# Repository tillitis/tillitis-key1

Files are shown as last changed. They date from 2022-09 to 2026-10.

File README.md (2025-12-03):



# Tillitis TKey

Read about current work in progress
[here](#current-work-in-progress-in-this-repository).

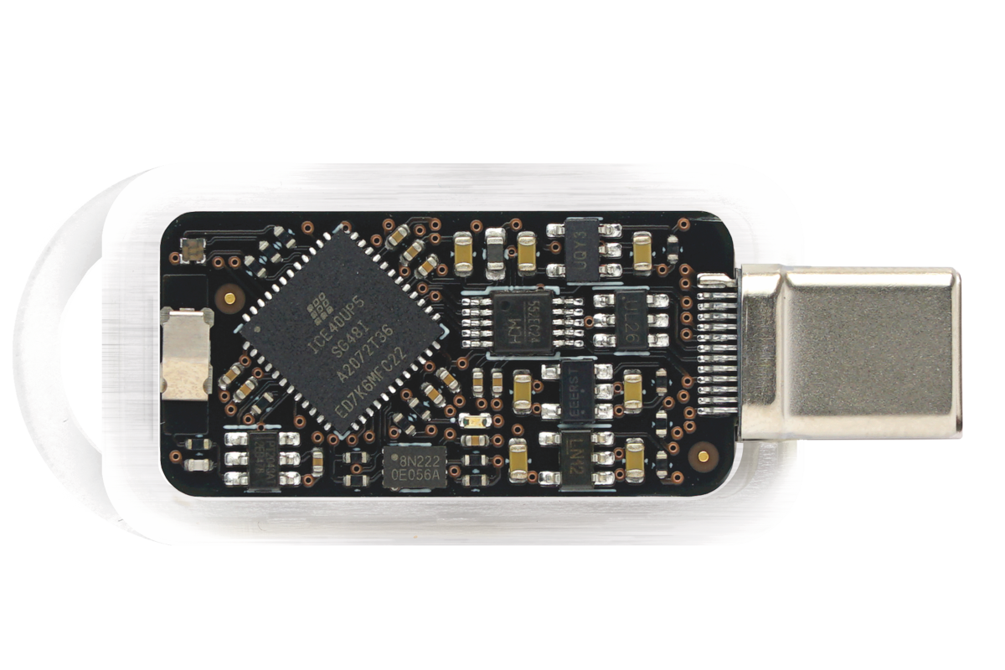
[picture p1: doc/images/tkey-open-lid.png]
TK1 PCB
 *The TK1 PCB, also known as
TKey.*

## Introduction

The Tillitis TKey is an open source, open hardware FPGA-based USB
security token using
[DICE-like](https://trustedcomputinggroup.org/work-groups/dice-architectures/)
unconditional measured boot that can run generic applications while
still guaranteeing the security of its cryptographic assets.

[TKey Threat Model](doc/threat_model/threat_model.md).

With the right application, the TKey can be used for:

- authentication,
- cryptographic signing,
- encryption,
- root of trust,
- and more: it's a general computer!

If you want to know more about Tillitis and the TKey, visit:

- Main web: <https://tillitis.se/>
- Shop: <https://shop.tillitis.se/>
- Developer Handbook: <https://dev.tillitis.se/>
- Officially supported apps: <https://tillitis.se/download/>
- Other known apps: <https://dev.tillitis.se/projects/>

All of the TKey software, firmware, FPGA Verilog code, schematics and
PCB design files are open source, just like all trustworthy security
software and hardware should be.

## Licensing

Unless otherwise noted, the project sources are copyright Tillitis AB,
but you can redistribute it and/or modify it under the terms of the
BSD-2-Clause license.

Until Oct 29, 2025, the license was GPL-2.0 Only.

Each imported project is typically kept in its own directory with its
own LICENSE file.

### SPDX

The project uses single-line references to Unique License Identifiers
as defined by the Linux Foundation's [SPDX project](https://spdx.org/).
The line in each individual source file identifies the license
applicable to that file.

The current set of valid, predefined SPDX identifiers can be found on
the SPDX License List at:

https://spdx.org/licenses/

We attempt to follow the [REUSE
specification](https://reuse.software/).

### Notable imported projects

- ch552 firmware: `hw/usb_interface/ch552_fw/`

  Originally by WCH under MIT. Much changed by Tillitis.

- picorv32: `hw/application_fpga/core/picorv32`

  From https://github.com/YosysHQ/picorv32

  ISC.

- PicoRV32 custom ops: `hw/application_fpga/fw/tk1/picorv32/`

  CC-1.

- tkey-libs: `hw/application_fpga/tkey-libs/`

  BSD2. From https://github.com/tillitis/tkey-libs

## Repositories

This repository contains the FPGA design, the source of the
firmware/bootloader, and the source of the USB controller firmware.

Specific documentation regarding implementation is kept close to the
code/design in README files, typically in the same directory.

Note that development is ongoing. To avoid unexpected changes of
derived key material, please use a tagged release. Read the [Release
Notes](doc/release_notes.md) to keep up to date with changes and new
releases.

The TKey PCB [KiCad](https://www.kicad.org/) design files are kept in
a separate repository:

<https://github.com/tillitis/tk1-pcba>

The TP1 (TKey programmer 1) PCB design files and the firmware sources
are kept in:

<https://github.com/tillitis/tp1>

Note that the TP1 is only used for provisioning the FPGA bitstream
into flash or the FPGA configuration memory. It's not necessary if you
just want to develop apps for the TKey.

We use the tkey-libs libraries used for device app development in the
firmware, too:

https://github.com/tillitis/tkey-libs

but keep our own copy of it in the repo. See below.

## Building & flashing

These instructions assume you're using a Linux distribution. Most of
them also assume you're using our OCI image
[tkey-builder](https://ghcr.io/tillitis/tkey-builder). If you want to
run native tools, look in `contrib/Dockerfile` and
`contrib/buildtools.sh` for the tools and versions to use.

### FPGA

You need a [TKey
Unlocked](https://shop.tillitis.se/products/tkey-not-provisioned), a
[the TP1 TKey Programmer
board](https://shop.tillitis.se/products/tkey-dev-kit), and probably a
[Blinkinlabs CH55x Reset
Controller](https://shop-nl.blinkinlabs.com/products/ch55x-reset-controller)
to use this on real hardware.

Building is probably easiest using make and Podman.

To build everything and then flash the resulting bitstream with the
defaultapp in app slot 0 and the partition table copies in one go,
place the TKey Unlocked in the TP1, then do:

```
cd contrib
make flash
```

This uses the make target `prog_flash` in
`hw/application_fpga/Makefile` behind the scenes, but mounts your TP1
device into the container.

If you want to change the default app the TKey uses, change
`FLASH_APP_0` in the `hw/application_fpga/Makefile`.

To see all container targets:

```
cd contrib
make
```

See the [Tillitis Developer Handbook](https://dev.tillitis.se) for
more.

### USB Controller

The TKey uses a WCH CH552 chip as a USB controller. It has its own
firmware.

Build:

```
cd contrib
make run
cd hw/usb_interface/ch552_fw
make
```

To flash the controller with new firmware you need hardware like the
[Blinkinlabs CH55x Reset
Controller](https://shop-nl.blinkinlabs.com/products/ch55x-reset-controller)
and a USB-A to USB-C converter.

[Reset Controller source](https://github.com/Blinkinlabs/ch55x_programmer).

You also need [chprog](https://github.com/ole00/chprog).

The bootloader identifies itself as USB VID 4348, PID 55e0. To be able
to access it and run `chprog` without root you need to allow your user
to access it. Place `contrib/99-tillitis.rules` in `/etc/udev/rules.d`
and run `udevadm control --reload`. Now you can add your user to the
`dialout` group and access it.

1. Connect the Reset Controller to your computer through "DUT\_IN"/"PC".
2. Connect the TKey to "DUT\_OUT"/"DUT".
3. Press the "Bootloader" button.
4. Run `make flash_patched` in `hw/usb_interface/ch552_fw` outside of
   a container.

## Updating and working with tkey-libs

A copy of [tkey-libs](https://github.com/tillitis/tkey-libs) is kept
in `hw/application_fpga/tkey-libs`. This is mostly to avoid the
subtleties of Git submodules.

If you want to change something in tkey-libs, always change in the
upstream library at:

https://github.com/tillitis/tkey-libs

You can build with an out-of-tree copy if you set `LIBDIR`, for
example:

```
make LIBDIR=~/git/tkey-libs firmware.elf
```

When it's time to update the in-tree tkey-lib first tag the upstream
repo with an `fw` prefix, like `fw-1` even if it already has an
official version tag.

Easiest is probably to just remove the tkey-libs directory and then
git clone the desired tag. Use the entire repo, but remove the .-files
like `.git`, `.github`, et cetera. Something like:

```
$ rm -rf tkey-libs
$ git clone git@github.com:tillitis/tkey-libs.git
$ cd tkey-libs
$ git checkout fw-3
```

Note that you need to change the optimization flag in the tkey-libs'
Makefile to `-Os`.

## Measured boot

The key behind guaranteeing security even as a general computer is the
unconditional measured boot. This means that we have a small,
unchangeable, trusted firmware in ROM that creates a unique identity
before starting the application. This identity is used as a seed for
all later cryptographic keys.

We call this identity the Compound Device Identity (CDI). The CDI is a
cryptographic mix of:

1. the Unique Device Secret (UDS), a hardware secret, unique per
   device, something the user *has*,
2. the hash digest of the TKey device application that has been
  loaded, the *integrity* of the application, and,
3. an optional User Supplied Secret (USS), something the user *knows*.

CDI is computed using the BLAKE2s hash function:

CDI = BLAKE2s(UDS, BLAKE2s(application loaded in RAM), USS)

When firmware is about to start the device application it changes the
TKey to a less permissive hardware mode, application mode. In
application mode the UDS and the User Supplied Secret are no longer
available, but the device application can use the CDI as a seed to
deterministically generate any cryptographic keys it needs.

- If the wrong application has been loaded, or the original
  application has been tampered with, the generated keys will be
  different.
- If the USS is not the same, the generated keys will be different.
- If the same USS and device application is used on a different TKey,
  the generated keys will be different.

The TKey unconditional measured boot is inspired by, but not exactly
the same as part of [TCG
DICE](https://trustedcomputinggroup.org/work-groups/dice-architectures/).

# Current Work in Progress in this repository

We are updating the FPGA and firmware on TKey as part of the Castor
release. This update will simplify TKey’s usage, laying the groundwork
for future support of U2F/FIDO authentication.

You can track our progress through this
[milestone](https://github.com/tillitis/tillitis-key1/milestone/1).

Note that main branch is in development. We try to keep status of main
branch updated in the [release notes](/doc/release_notes.md#upcoming-release-castor).

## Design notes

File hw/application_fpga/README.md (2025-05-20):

## TKey hardware design

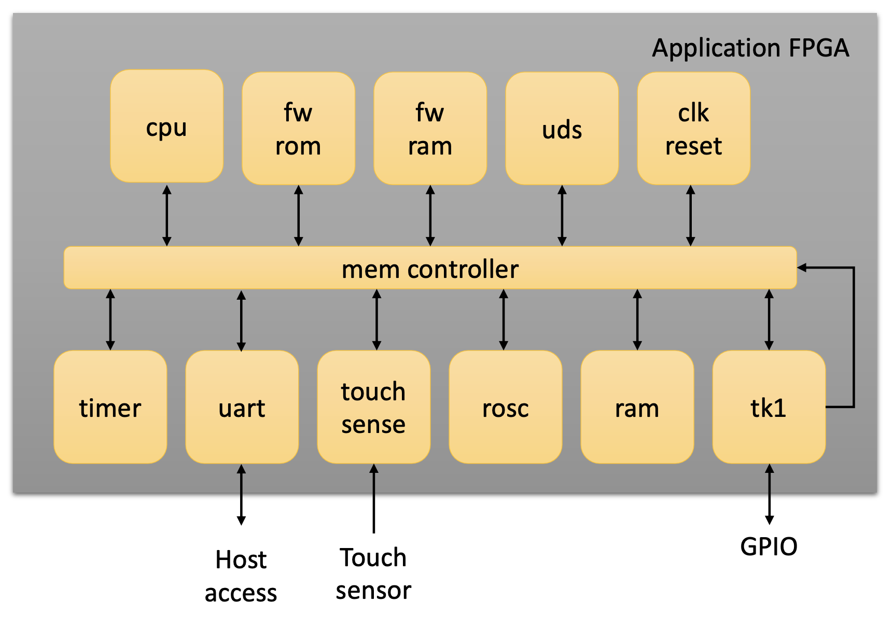
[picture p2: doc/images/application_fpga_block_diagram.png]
The Application FPGA block diagram


The application FPGA is implemented using a Lattice [iCE40 UltraPlus
UP5K
device](https://www.latticesemi.com/en/Products/FPGAandCPLD/iCE40UltraPlus).
Only open tools are used in the toolchain.

The design top level is in `rtl/application_fpga.v`. It contains
instances of all cores as well as the memory system.

The memory system allows the CPU to access cores in different ways
given the current execution mode. There are three execution modes -
firmware, application and system call. Each mode give access to a
different set of resources. Where app mode is the most restrictive and
firmware mode is the least restrictive.

The rest of the components are under `cores`, except the firmware,
which is under `fw/tk1`. They typically have their own `README.md`
file documenting them and their API in detail.

Hardware functions with APIs, assets, and input/output are memory
mapped starting at base address `0xc000_0000`. For specific offsets
and bitmasks, see the file `tk1_mem.h` in tkey-libs.

Rough memory map:

| *name*  | *prefix* |
|---|---|
| ROM | 0x00 |
| RAM | 0x40 |
| TRNG | 0xc0 |
| Timer | 0xc1 |
| UDS | 0xc2 |
| UART | 0xc3 |
| Touch | 0xc4 |
| FW\_RAM | 0xd0 |
| Syscall | 0xe1 |
| TK1 | 0xff |

## Firmware

Firmware is kept in ROM. See the [Firmware implementation
notes](fw/README.md).

## `clk_reset_gen`

Generator for system clock and system reset.

The device does not rely on external clock or reset. Instead the
internal HFOSC oscillator combined with an internal PLL is used to
generate the main clock. Currently the clock frequency driving the SoC
is 21 MHz.

The device also generates its own reset.

## `fw_ram`

Special firmware-only RAM. Unreachable from app mode.

## `picorv32`

A softcore 32 bit RISC-V CPU from [upstreams
PicoRV32](https://github.com/YosysHQ/picorv32).

Configuration of optional CPU features like `ENABLE_FAST_MUL` et
cetera are in `rtl/application_fpga.v`.

The instance enables the following features

- Compressed ISA (C extension)
- Fast multiplication. Two cycles for 32x32 multiplication
- Barrel shifter

No other modification to the core has been done. No interrupts are
used.

## `ram`

The 128 KByte main RAM. The RAM is only used by applications.
The memory is cleared by firmware before an application is loaded.

The application RAM is available to use by firmware and applications.

The RAM core also implements (from the view of the CPU) transparent
RAM address and data scrambling. This scrambling is applied to make it
harder to extract application and application data from a memory dump
directly from the memory cores.

## `rom`

ROM for the firmware. The firmware.elf minus the ELF header is
embedded here in the bitstream.

After reset the CPU will initialize the program counter to start of
ROM.

## `timer`

A general purpose 32 bit timer. The timer will count down from the
initial value to one. In order to handle long time sequences (minutes,
hours, days) there is also a 32 bit prescaler.

The timer is available to use by firmware and applications.

## Syscall

System call trigger area. A 32-bit write to address 0xe1000000 will
trigger interrupt 31, which in turn triggers a system call in the
firmware.

## Interrupts

Triggering an interrupt will cause the CPU to execute the interrupt
handler att address 0x10.

The interrupt handler is shared by all PicoRV32 interrupts but only
interrupt 31 is enabled on the Tkey. Register `x4` can be inspected to
determine the interrupt source. Each interrupt source is assigned one
bit in x4. Triggered interrupts have their bit set to `1`.

| *Source* | *x4 Bit* |
|---|---|
| Syscall  | 31 |

The return address is located in register `x3`. Calling the PicoRV32
specific instruction `retirq` exits the interrupt handler and clears
the interrupt source.

No registers are stored/restored when entering/exiting the interrupt
handler. It is up to the software to store/restore as necessary.

Interrupts can be enabled/disabled using the PicoRV32 specific
`maskirq` instruction.

## Restricted resources

The following table shows resource availablility for each execution
mode:

| *Execution Mode* | *ROM* | *FW RAM* | *SPI* | *UDS* |
|---|---|---|---|---|
| Firmware mode | r/x | r/w | r/w | r/w*  |
| Syscall | r/x | r/w | r/w | i |
| Application mode | r | i | i | i |

Legend:
r = readable
w = writeable
x = executable
i = invisible
* = UDS words are readable only once in firmware mode.

## `tk1`

See [tk1 README](core/tk1/README.md) for details.

Contains:

- FPGA name and version.
- Execution mode control: firmware mode/application mode.
- RGB LED control.
- General purpose input/output (GPIO) pin control.
- Application introspection: start address and size of binary.
- Compound Device Identity (CDI).
- Unique Device Identity (UDI).
- RAM memory protection.
- Security monitor.
- SPI main.
- System reset.

### Illegal instruction monitor

Execution of illegal instructions will cause the CPU to enter its trap
state from which it can't exit. The hardware in the TKey will monitor
the CPU state. If the CPU enters the trap state, the hardware will
start flashing the RED led, signalling that the TKey is stuck in an
error state.

### RAM memory protection

The TKey hardware includes a simple form of RAM memory protection. The
purpose of the RAM memory protection is to make it somewhat harder and
more time consuming to extract application assets by dumping the RAM
contents from a TKey device. The memory protection is not based on
encryption and should not be confused with real encryption. The
protection is randomised between power cycles. The randomisation
should make it infeasible to improve asset extraction by observing
multiple memory dumps from the same TKey device. The attack should
also not directly scale to multiple TKey devices.

The RAM address and data scrambling is done in the RAM core.

The memory protection is setup by the firmware. Access to the memory
protection controls is disabled for applications. Before the memory
protecetion is enabled, the RAM is filled with randomised data using
Xorwow. During boot the firmware perform the following steps to setup
the memory protection:

1. Get a random 32-bit value from the TRNG to use as data state for
   Xorwow.
2. Get a random 32-bit value from the TRNG to use as accumulator
   for Xorwow.
3. Fill RAM with a random sequence of values by writing to all RAM
   addresses. For each address use Xorwow to generate a new state,
   using the accumulator.
4. Write a random 32-bit value from the TRNG into the
   ADDR\_RAM\_ADDR\_RAND register.
5. Write a random 32-bit value from the TRNG into the
   ADDR\_RAM\_DATA\_RAND register.
6. Receive the application sent from the client and write it in
   sequence into RAM.

## `touch_sense`

Provide touch sensor events to software.

It is recommended that software start by acknowledge any stray events
prior to signalling to the user that a touch event is expected and
then start waiting for an event.

The touch sensor is available to use by firmware and applications.

## `trng`

Provide a True Random Number Generator to software.

The TRNG generates entropy with a fairly good quality. However for
security related use cases, for example key generation, the TRNG
should not be used directly. Instead use it to create a seed, and
reseed as necessary, for a Digital Random Bit Generator (DRBG), also
known as a Cryptographically Safe Pseudo Random Number Generator
(CSPRNG). Examples of such generators are Hash\_DRGG, CTR\_DRBG, and
HKDF.

## `uart`

A simple universal asynchronous receiver/transmitter (UART) used for
communication with the client through the USB controller.

The UART contain a 512-byte Rx-FIFO with status (data available).

The UART is available to use by firmware and applications.

## `uds`

The Unique Device Secret. During build initial value is taken from
`data/uds.hex`.

However, with the finished bitstream you can patch in another UDS and
UDI by using `tools/patch_uds_udi.py` with nextpnr.

It's a 256 bit memory implemented using eight 32-bit registers. The
registers can only be accessed once between power cycling. This means
that the UDS **must** be read as u32. If read as u8, only the first
byte from a given address will be correct, subsequent bytes will be
zero.

The UDS can only be read in firmware mode. Reading from the UDS in
application mode will return all zeros.

## References
More detailed information about the firmware running on the device can
be found in the
[hw/application_fpga/fw/README.md](hw/application_fpga/fw/README.md).

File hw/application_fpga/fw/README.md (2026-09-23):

# Firmware implementation notes

## Introduction

This text is specific for the firmware, the piece of software in TKey
ROM. For a more general description on how to implement device apps,
see [the TKey Developer Handbook](https://dev.tillitis.se/).

## Definitions

- Firmware: Software in ROM responsible for loading, measuring,
  starting applications, and providing system calls. The firmware is
  included as part of the FPGA bitstream and not replaceable on a TKey
  (note: on TKey Unlocked the user themself program the TKey and can
  choose not to lock the memory in TKey and thus leave it open for
  re-programming).
- Client: Software running on a computer or a mobile phone the TKey is
  inserted into.
- Device application or app: Software supplied by the client or from
  flash that runs on the TKey.

## CPU modes and firmware

The TKey has two modes of software operation: firmware mode and
application mode. The TKey always starts in firmware mode when it
starts the firmware. When the application starts the hardware
automatically switches to a more constrained environment: the
application mode.

The TKey hardware cores are memory mapped but the memory access is
different depending on mode. Firmware has complete access, except that
the Unique Device Secret (UDS) words are readable only once even in
firmware mode. The memory map is constrained when running in
application mode, e.g. FW\_RAM and UDS isn't readable, and several
other hardware addresses are either not readable or not writable for
the application.

When doing system calls from a device app the context switches back to
firmware mode. However, the UDS is still not available, protected by
two measures: 1) the UDS words can only be read out once and have
already been read by firmware when measuring the app, and, 2) the UDS
is protected by hardware after the execution leaves ROM for the first
time.

See the table in [the Developer
Handbook](https://dev.tillitis.se/memory/) for an overview about the
memory access control.

## Communication

The firmware communicates with the client using the
`UART_{RX,TX}_{STATUS,DATA}` registers. On top of that it uses three
protocols: The USB Mode protocol, the TKey framing protocol, and the
firmware's own protocol.

To communicate between the CPU and the CH552 USB controller it uses an
internal protocol, used only within the TKey, which we call the USB
Mode Protocol. It is used in both directions.

| *Name* | *Size* | *Comment* |
|---|---|---|
| Endpoint | 1B | Origin or destination USB endpoint |
| Length | 1B | Number of bytes following |
| Payload  | See below | Actual data from or to firmware |

The different endpoints:

| *Name* | *Value* | *Comment* |
|---|---|---|
| CH552  | 0x04 | USB controller control endpoint. Always active. |
| CDC | 0x08 | USB CDC-ACM, a serial port on the client. |
| FIDO | 0x10 | A USB FIDO security token device, useful for FIDO-type applications. |
| CCID | 0x20 | USB CCID, a port for emulating a smart card |
| DEBUG  | 0x40 | A USB HID special debug pipe. Useful for debug prints. |

You can turn on and off different endpoints dynamically by sending
commands to the `CH552` control endpoint. After a power cycle only the
`CH552` endpoint is active. After a software-induced reset, the TKey
firmware quickly sets the USB controller back to this state.

To change which endpoints are active you send a command to `CH552` in
this form:

| *Name* | *Size* | *Comment* |
|---|---|---|
| Command  | 1B | Command to the CH552 firmware |
| Argument | 1B | Data for the command |

Commands:

| *Name* | *Value* | *Argument* |
|---|---|---|
| Enable endpoints | 0x01 | Bitmask of endpoints |

On top of the USB Mode Protocol is [the TKey Framing
Protocol](https://dev.tillitis.se/protocol/) which is described in the
Developer Handbook.

The firmware uses a protocol on top of this framing layer which is
used to load a device application. All commands are initiated by the
client. All commands receive a reply. See [Firmware
protocol](http://dev.tillitis.se/protocol/#firmware-protocol) in the
Dev Handbook for specific details.

## Memory constraints

| *Name*  | *Size* | *FW mode* | *App mode* |
|---|---|---|---|
| ROM | 8 kByte | r-x | r |
| FW\_RAM | 4 kByte*  | rw- | - |
| RAM | 128 kByte | rwx | rwx |

* FW\_RAM is divided into the following areas:

- firmware stack: 3000 bytes.
- `resetinfo` area: 256 bytes.
- `.data` and `.bss`: 840 bytes.

## Firmware behaviour

The purpose of the firmware is to:

1. Load, measure, and start an application received from the client
   over the USB/UART or from one of two flash app slots.
2. Provide functionality to run only apps with specific BLAKE2s
   digests.
3. Provide system calls to access the filesystem and get other data.
4. To help measure data into the new Compound Device Identifier when
   chaining apps.

The firmware binary is part of the FPGA bitstream as the initial
values of the Block RAMs used to construct the ROM. The ROM is located
at `0x0000_0000`. This is also the CPU reset vector.

### Reset type

When the TKey is started or reset it can load an app from different
sources. We call this the reset type. Reset type is located in the
`resetinfo` part of FW\_RAM. The different reset types loads and start
an app from:

1. Flash slot 0 (default): `FLASH0` with a specific app hash defined
   in a constant in firmware.
2. Flash slot 1 with a specific app hash left from previous app:
   `FLASH1_VER`.
3. Client: `CLIENT`.
4. Client with a specific app hash left from previous app:
   `CLIENT_VER`.

### Firmware state machine

Change of state occur when we receive specific I/O or a fatal error
occurs.

```mermaid
stateDiagram-v2
    S0: INITIAL
    S1: WAITCOMMAND
    S2: LOADING
    S3: LOAD_FLASH
    S4: LOAD_FLASH_MGMT
    S5: START
    SE: FAIL

    [*] --> S0

    S0 --> S1
    S0 --> S4: Default
    S0 --> S3
    S0 --> SE: Unknown reset type

    S1 --> S1: Other commands
    S1 --> S2: LOAD_APP
    S1 --> SE: Error

    S2 --> S2: LOAD_APP_DATA
    S2 --> S5: Last block received
    S2 --> SE: Error

    S3 --> S5
    S3 --> SE

    S4 --> S5
    S4 --> SE

    SE --> [*]
    S5 --> [*]
```

States:

- *INITIAL*: Transitions to next state through reset type left in
  `FW_RAM`.
- *WAITCOMMAND*: Waiting for initial commands from client. Allows the
  commands `NAME_VERSION`, `GET_UDI`, `LOAD_APP`.
- *LOADING*: Expecting application data from client. Allows only the
  command `LOAD_APP_DATA` to continue loading the device app.
- *LOAD_FLASH*: Loading an app from flash. Allows no commands.
- *LOAD_FLASH_MGMT*: Loading an app from flash and registering it as a
  prospective managment app. Allows no commands.
- *START*: Computes CDI. Possibly verifies app. Starts the
  application. Does not return to firmware. Allows no commands.
- *FAIL* - Halts CPU. Allows no commands.

Allowed data in state *INITIAL*:

| *reset type* | *next state* |
|---|---|
| `FLASH0` | *LOAD_FLASH_MGMT* |
| `FLASH1_VER` | *LOAD_FLASH* |
| `CLIENT` | *WAITCOMMAND* |
| `CLIENT_VER` | *WAITCOMMAND* |
| unknown | *FAIL* |

I/O in state *LOAD_FLASH*:

| *I/O* | *next state* |
|---|---|
| Last app data read | *START* |

I/O in state *LOAD_FLASH_MGMT*:

| *I/O* | *next state* |
|---|---|
| Last app data read | *START* |

Commands in state *WAITCOMMAND*:

| *command* | *next state* |
|---|---|
| `FW_CMD_NAME_VERSION` | unchanged |
| `FW_CMD_GET_UDI` | unchanged |
| `FW_CMD_LOAD_APP` | *LOADING* or unchanged on invalid app size |

Commands in state *LOADING*:

| *command* | *next state* |
|---|---|
| `FW_CMD_LOAD_APP_DATA` | unchanged or *START* on last chunk |

No other states allows commands.

See [Firmware protocol in the Dev
Handbook](http://dev.tillitis.se/protocol/#firmware-protocol) for the
definition of the specific commands and their responses.

Plain text explanation of the states:

- *INITIAL*: Start here. Check the `FW_RAM` for the `resetinfo` type
  for what to do next.

  For type `FLASH0` transition to *LOAD_FLASH_MGMT* because the app in
  slot 0 is considered a special management app. For all other types
  beginning with `FLASH*` transition to *LOAD_FLASH* to load an
  ordinary app from flash.

  For type `CLIENT*` transition to *WAITCOMMAND* to expect a device app
  from the client.

  If type is unknown, error out.

- *LOAD_FLASH*: Load device app from flash into RAM, app slot taken
  from context. Compute a BLAKE2s digest over the entire app.
  Transition to *START*.

- *LOAD_FLASH_MGMT*: Load device app from flash into RAM, app slot
  always 0. Compute a BLAKE2s digest over the entire app. Register the
  app as a prospective management app. Transition to *START*.

- *WAITCOMMAND*: Wait for commands from the client. Transition to
  *LOADING* on `LOAD_APP` command, which also sets the size of the
  number of data blocks to expect.

- *LOADING*: Wait for several `LOAD_APP_DATA` commands until the last
  block is received, then transition to *START*.

- *START*: Compute the Compound Device Identifier (CDI). If we have a
  registered verification digest, verify that the app we are about to
  start is indeed the correct app. This also means that a prospective
  management app is now verified.

  We can compute the CDI in two different ways. See [Compound Device
  Identifier computation](#compound-device-identifier-computation) below

  Clean up firmware data structures, enable the system calls, and
  start the app, which ends the firmware state machine. Hardware
  guarantees that we leave firmware mode automatically when the
  program counter leaves ROM.

- *FAIL*: Execute an illegal instruction which traps the CPU. Hardware
  detects a trapped CPU and blinks the status LED in red until power
  loss. No further instructions are executed.

After leaving *START* the device app is now running in application
mode. We can, however, return to firmware mode (excepting access to
the UDS) by doing system calls. Note that ROM is still readable, but
is now hardware protected from execution, except through the system
call mechanism.

If during this whole time any commands are received which are not
allowed in the current state, or any errors occur, we enter the *FAIL*
state.

### Golden path from start to default app

Firmware will load the device application at the start of RAM
(`0x4000_0000`) from either flash or from the client through the UART.
Firmware is using a part of the FW\_RAM for its own stack.

When reset is released, the CPU starts executing the firmware. It
begins in `start.S` by clearing all CPU registers, clears all FW\_RAM,
except the part reserved for the `resetinfo` area, sets up a stack for
itself there, and then jumps to `main()`. Also included in the
assembly part of firmware is an interrupt handler for the system
calls, but the handler is not yet enabled.

Beginning at `main()` it fills the entire RAM with pseudo random data
and setting up the RAM address and data hardware scrambling with
values from the True Random Number Generator (TRNG).

Firmware then proceeds to:

1. Read the partition table from flash and store in FW\_RAM.

2. Reset the CH552 USB controller to a known state, only allowing the
   CDC USB endpoint and the internal command channel between the CPU
   and the CH552.

3. Check the special `resetinfo` area in FW\_RAM for reset type. Type
   zero means default behaviour, load from flash app slot 0, expecting
   the app there to have a specific hard coded BLAKE2s digest.

4. Load app data from flash slot 0 into RAM.

5. Compute a BLAKE2s digest of the loaded app.

6. Compare the computed digest against the allowed app digest
   hard coded in the firmware. If it's not equal, halt CPU.

7. [Start the device app](#start-the-device-app).

### Start the device app

1. Check if there is a verification digest left from the previous app
   in the `resetinfo` area. If it is, compare with the loaded app's
   already computed digest. Halt CPU if different.

2. Compute the Compound Device Identifier
   ([CDI](#compound-device-identifier-computation)).

3. Write the start address of the device app, currently `0x4000_0000`,
   to `APP_ADDR` and the size of the loaded binary to `APP_SIZE` to
   let the device application know where it is loaded and how large it
   is, if it wants to relocate in RAM.

4. Clear the stack part of `FW_RAM`.

5. Enable system call interrupt handler.

6. Start the application by jumping to the contents of `APP_ADDR`.
   Hardware automatically switch from firmware mode to application
   mode. In this mode some memory access is restricted, e.g. some
   addresses are inaccessible (`UDS`), and some are switched from
   read/write to read-only (see [the memory
   map](https://dev.tillitis.se/memory/)).

### Management app, chaining apps and verified boot

Normally, the TKey measures a device app and mixes it together with
the Unique Device Secret in hardware to produce the [Compound Device
Identifier]((#compound-device-identifier-computation)). The CDI can
then be used for creating key material. However, since any key
material created like this will change if the app is changed even the
slightest, this make it hard to upgrade apps and keep the key
material.

This is where a combination of measured boot and verified boot comes
in!

To support verified boot the firmware supports reset types with
verification. This means that the firmware will load an app as usual
either from flash or from the client, but before starting the app it
will verify the new app's computed digest with a verification digest.

Such a verified boot loader app:

- Might be loaded from either flash or client.

- Typically includes a security policy, for instance a public key and
  code to check a cryptographic signature.

- Can be specifically trusted by firmware to be able to do filesystem
  management to be able to update an app slot on flash. Add the app's
  digest to `allowed_app_digest` in `mgmt_app.c` to allow it to use
  `PRELOAD_DELETE`, `PRELOAD_STORE`, `PRELOAD_STORE_FIN`, and
  `PRELOAD_GET_METADATA`.

It works like this:

- The app reads a digest of the next app in the chain and the
  signature over the digest from either the filesystem (system call
  `PRELOAD_GET_METADATA`) or sent from the client.

- If the signature provided over the digest is verified against the
  public key the app use the system call `RESET` with the reset type
  set to `START_FLASH1_VER`, or `START_CLIENT_VER` depending on where
  it wants the next app to start from. It also sends the now verified
  app digest to the firmware in the same system call.

- The app leaves something it want's to be measured by the firmware
  for the coming CDI, typically a digest of its own security policy,
  like a vendor public key.

- The key is reset and firmware starts again. It checks:

  1. The reset type. Start from client or a slot in the filesystem?
  2. The expected digest of the next app.

- Firmware loads the app from the expected source.

- Firmware refuses to start if the loaded app has a different digest.

- If the app was allowed to start it can use the CDI as usual for its
  key material. See the [Compound Device Identifier
  computation](#compound-device-identifier-computation) for more about
  the different CDI computations.

### App loaded from client

The default is always to start from a verified app in flash slot
0. To be able to load an app from the client you have to send
something to the app to reset the TKey with a reset type of
`START_CLIENT` or `START_CLIENT_VER`.

After reset, firmware will:

1. Wait for data coming in through the UART.

2. The client sends the `FW_CMD_LOAD_APP` command with the size of
   the device app and the optional 32 byte hash of the user-supplied
   secret as arguments and gets a `FW_RSP_LOAD_APP` back. After
   using this it's not possible to restart the loading of an
   application.

3. On a successful response, the client will send multiple
   `FW_CMD_LOAD_APP_DATA` commands, together containing the full
   application.

4. On receiving`FW_CMD_LOAD_APP_DATA` commands the firmware places
   the data into `0x4000_0000` and upwards. The firmware replies
   with a `FW_RSP_LOAD_APP_DATA` response to the client for each
   received block except the last data block.

5. When the final block of the application image is received with a
   `FW_CMD_LOAD_APP_DATA`, the firmware measure the application by
   computing a BLAKE2s digest over the entire application. Then
   firmware send back the `FW_RSP_LOAD_APP_DATA_READY` response
   containing the digest.

6. [Start the device app](#start-the-device-app).

### User-supplied Secret (USS)

USS is a 32 bytes long secret provided by the user. Typically a client
program gets a secret from the user and then does a key derivation
function of some sort, for instance a BLAKE2s, to get 32 bytes which
it sends to the firmware to be part of the CDI computation.

Note: From the user’s perspective, the USS can be any length—there is
no minimum or maximum. The client program must safely convert the user
input into a 32-byte value.

### Compound Device Identifier computation

The CDI is computed in one of two ways. In both of them the Unique
Device Secret is used as a key in the BLAKE2s hash function.

1. CDI is a result of a hash of the Unique Device Secret, a domain
   byte with the measured-id bit cleared, the digest of the entire
   loaded app, and optionally the User Supplied Secret, if sent from
   the client:

   ```C
   CDI = blake2s(
       key = UDS,
       data = domain || blake2s(app) || USS)
   ```

   This is the default case.

2. CDI is a result of a hash of the Unique Device Secret, a domain
   byte with the measured-id bit set, something left by the previous
   app, and optionally the User Supplied Secret, if sent from the
   client:

   ```C
   CDI = blake2s(
       key = UDS,
       data = domain || measured_id* || USS)
   ```

   ```C
    measured_id* = blake2s(
        key = previous-CDI,
        data = measured_id_seed)
    ```

  This alternative computation is only done if the `mask` in `struct
  reset` includes `RESET_SEED`.

  Note that this is done in two parts, before and after reset, in
  order not to leak CDI between resets.

  1. Before reset (marked with an asterisk above): Typically a calling
     app would do a `TK1_SYSCALL_RESET` system call and fill in
     something it wants to be mixed into the new CDI in
     `measured_id_seed`. The firmware will then mix a new
     `measured_id` before doing the actual reset:

  2. After reset: `measured_id` will survive the reset and will be
     used in the CDI computation for the next app.

The domain byte is used to separate combinations of the following:

- Directly loaded or chained app
- USS or no USS
- Boot type (resetinfo.type)

| *Bits* | *Name* | *Value* | *Meaning* |
|---|---|---|---|
| 0 | DOMAIN_USS_USED | 0 | No USS |
| | | 1 | USS |
| 1 | DOMAIN_CHAINED | 0 | Directly loaded app |
| | | 1 | Chained app |
| 2:3 | DOMAIN_RESET_TYPE | 0-3 | Value present in resetinfo.type at boot |
| 4:7 | | | Reserved, all zeros |

- Directly loaded app: the app's BLAKE2s digest is used.
- Chained app: the `measured_id` measurement from before a reset is used.

In an ideal world, software would never be able to read UDS at all and
we would have a BLAKE2s function in hardware that would be the only
thing able to read the UDS. Unfortunately, we couldn't fit a BLAKE2s
implementation in the FPGA.

The firmware instead does the CDI computation using the special
firmware-only `FW_RAM` which is invisible in app mode. We keep the
entire firmware stack in `FW_RAM` and clear the stack just before
switching to app mode just in case.

We sleep for a random number of cycles before reading out the UDS,
call `blake2s_update()` with it and then immediately call
`blake2s_update()` again with the program digest, destroying the UDS
stored in the internal context buffer. UDS should now not be in
`FW_RAM` anymore. We can read UDS only once per power cycle so UDS
should now not be available even to firmware.

Then we continue with the CDI computation by updating with the domain,
measured_id, and optional USS digest. Then finalizing the hash,
storing the resulting digest in `CDI`.

### System calls

The firmware provides a system call mechanism through the use of the
PicoRV32 interrupt handler. They are triggered by writing to the
trigger address: 0xe1000000. It's typically done with a function
signature like this:

```C
int syscall(uint32_t number, uint32_t arg1, uint32_t arg2,
	    uint32_t arg3);
```

Arguments are system call number and up to 6 generic arguments passed
to the system call handler. The caller should place the system call
number in the a0 register and the arguments in registers a1 to a7
according to the RISC-V calling convention. The caller is responsible
for saving and restoring registers.

The system call handler returns execution on the next instruction
after the store instruction to the trigger address. The return value
from the system call is now available in x10 (a0).

The system call numbers are kept in `syscall_num.h`. The system calls
are handled in `syscall_handler()` in `syscall_handler.c`.

#### `RESET`

```C
struct reset {
	enum reset_start type;
	uint8_t mask;
	uint8_t app_digest[RESET_DIGEST_SIZE];
	uint8_t measured_id_seed[RESET_DIGEST_SIZE];
	uint8_t next_app_data[RESET_DATA_SIZE];
};

struct reset rst;
uint32_t len; // Length of data in next_app_data.

syscall(TK1_SYSCALL_RESET, (uint32_t)&rst, len, 0);
```

Resets the TKey. Does not return.

You can pass data to the firmware about the reset type `type` and
`measured_id_seed` that you want to include in the CDI measurement for
the next app by the firmware. The next app's identity will be measured with
what you leave in `measured_id_seed`, typically a digest of your
security policy, the current app's CDI, the UDS of the TKey, and
optionally a USS.

You can also leave some data to the next app in the chain in
`next_app_data`.

The types of reset are defined in `reset.h`:

| *Name* | *Comment* |
|---|---|
| `START_FLASH0` | Load next app from flash slot 0 |
| `START_FLASH1_VER` | Load next app from flash slot 1, but verify it |
| `START_CLIENT` | Load next app from client |
| `START_CLIENT_VER` | Load next app from client |

#### `GET_RESET_DATA`

```C
uint8_t next_app_data[184];
syscall(TK1_SYSCALL_GET_RESET_DATA, (uint32_t)next_app_data, 0, 0);
```

Fills in data left from previous app in the chain into next_app_data.
Buffer needs to be large enough to receive `RESET_DATA_SIZE` bytes.

#### `ALLOC_AREA`

```C
syscall(TK1_SYSCALL_ALLOC_AREA, 0, 0, 0);
```

Allocate a flash area for the current app. Returns 0 on success.

#### `DEALLOC_AREA`

```C
syscall(TK1_SYSCALL_DEALLOC_AREA, 0, 0, 0);
```

Free an already allocated flash area for the current app. Returns 0 on
success.

#### `WRITE_DATA`

```C
uint32_t offset = 0;
uint8_t buf[17];

syscall(TK1_SYSCALL_WRITE_DATA, offset, (uint32_t)buf, sizeof(buf))
```

Write data in `buf` to the app's flash area at byte `offset` within
the area. Returns 0 on success.

Up to storage area size bytes can be written at once and offset must
be a multiple of 256 bytes.

#### `READ_DATA`

```C
uint32_t offset = 0;
uint8_t buf[17];

syscall(TK1_SYSCALL_READ_DATA, offset, (uint32_t)buf, sizeof(buf);
```

Read into `buf` at byte `offset` from the app's flash area. The read
length limit is the size of the storage area.

#### `ERASE_DATA`

```C
uint32_t offset = 0;
uint32_t size = 4096;

syscall(TK1_SYSCALL_ERASE_DATA, offset, size, 0);
```

Erase `size` bytes from `offset` within the area. Returns 0 on
success.

Both `size` and  `offset` must be a multiple of 4096 bytes.

#### `GET_VIDPID`

```C
syscall(TK1_SYSCALL_GET_VIDPID, 0, 0, 0);
```

Returns Vendor and Product ID. Notably the serial number is not
returned, so a device app can't identify what particular TKey it is
running on.

#### `PRELOAD_STORE`

```C
uint8_t *appbinary;
uint32_t offset;
uint32_t size;

syscall(TK1_SYSCALL_PRELOAD_STORE, offset, (uint32_t)appbinary,
			  size);
```

Store an app, or possible just a block of an app, from the `appbinary`
buffer in flash slot 1 at byte `offset`.

If you can't fit your entire app in the buffer, call `PRELOAD_STORE`
many times as you receive the binary from the client. Returns 0 on
success.

At most 4096 bytes can be written at once and `offset` must be a
multiple of 4096 bytes.

Only available for the verified management app.

#### `PRELOAD_STORE_FIN`

```C
uint8_t app_digest[32];
uint8_t app_signature[64];
size_t app_size;

syscall(TK1_SYSCALL_PRELOAD_STORE_FIN, app_size,
		    (uint32_t)app_digest, (uint32_t)app_signature)
```

Finalize storing of an app where the complete binary size is
`app_size` in flash slot 1. Returns 0 on success. Only available for
the verified management app.

Compute a BLAKE2s hash digest over the entire binary. Pass the result
in `app_digest`.

Sign `app_digest` with your Ed25519 private key and pass the
resulting signature in `app_signature`.

#### `PRELOAD_DELETE`

```C
syscall(TK1_SYSCALL_PRELOAD_DELETE, 0, 0, 0);
```

Delete the app in flash slot 1. Returns 0 on success. Only available
for the verified management app.

#### `PRELOAD_GET_METADATA`

```C
uint8_t app_digest[32];
uint8_t app_signature[64];
uint8_t pubkey[32];

syscall(TK1_SYSCALL_PRELOAD_GET_METADATA, (uint32_t)app_digest,
		(uint32_t)app_signature, (uint32_t)pubkey;
```

Copies the digest and signature of app, and pubkey in flash slot 1 to
`app_digest`, `app_signature` and `pubkey`. Returns 0 on success. Only
available for the verified management app.

#### `PRELOAD_SET_PUBKEY`

```C
uint8_t pubkey[32];

syscall(TK1_SYSCALL_PRELOAD_SET_PUBKEY, (uint32_t)pubkey, 0, 0);
```

Stores pubkey for app in flash slot 1. Only available for the verified
management app. Returns 0 on success.

#### `STATUS`

```C
syscall(TK1_SYSCALL_PRELOAD_STATUS, 0, 0, 0);
```

Returns filesystem status. Non-zero when problems have been detected,
so far only that the first copy of the partition table didn't pass
checks.

#### `ERASE_AREA`

```C
uint8_t area;
syscall(TK1_SYSCALL_ERASE_AREA, (uint32_t)area, 0, 0);
```

Erases a storage area. Privileged syscall. Returns 0 on success.

## Developing firmware

Standing in `hw/application_fpga/` you can run `make firmware.elf` to
build just the firmware. You don't need all the FPGA development
tools. See [the Developer Handbook](https://dev.tillitis.se/tools/)
for the tools you need. The easiest is probably to use our OCI image,
`ghcr.io/tillitis/tkey-builder`.

[Our version of qemu](https://dev.tillitis.se/tools/#qemu-emulator) is
also useful for debugging the firmware. You can attach GDB, use
breakpoints, et cetera.

There is a special make target for QEMU: `qemu_firmware.elf`, which
sets `-DQEMU_DEBUG`, so you can debug prints using the `debug_*()`
functions. Note that these functions are only usable in QEMU and that
you might need to `make clean` before building, if you have already
built before.

To build a flash image file suitable for use with qemu, use the
`tools/tkeyimage` program. See its documentation.

If you want debug prints to show up on the special TKey HID debug
endpoint instead, define `-DTKEY_DEBUG`. This might mean you can't fit
the firmware in the ROM space available, however. You will get a
warning if it doesn't fit. In that case, just use explicit
`puts(IO_DEBUG, ...)` or `puts(IO_CDC, ...)` and so on.

Note that if you use `TKEY_DEBUG` you *must* have something listening
on the corresponding HID device. It's usually the last HID device
created. On Linux, for instance, this means the last reported hidraw
in `dmesg` is the one you should do `cat /dev/hidrawX` on.

### tkey-libs

Most of the utility functions that the firmware use lives in
`tkey-libs`. The canonical place where you can find tkey-libs is at:

  [https://github.com/tillitis/tkey-libs](https://github.com/tillitis/tkey-libs)

but we have vendored it in for firmware use in `../tkey-libs`. [See
top README](../../../README.md) for how to update.

### Test firmware

The test firmware is in `testfw`. It's currently a bit of a hack and
just runs through expected behavior of the hardware cores, giving
special focus to access control in firmware mode and application mode.

It outputs results on the UART. This means that you have to attach a
terminal program to the serial port device, even if it's running in
qemu. It waits for you to type a character before starting the tests.

It needs to be compiled with `-Os` instead of `-O2` in `CFLAGS` in the
ordinary `application_fpga/Makefile` to be able to fit in ROM.

### Test apps

There are a couple of test apps, see `../apps`.

## Filesystem

The TKey supports a simple filesystem.

The `tkeyimage` tool is used to parse or generate partition table or
entire filesystem images for the TKey.

The fileystem layout looks like this:

| **name** | **size** | **start address** | **comment** |
|---|---|---|---|
| Bitstream | 128 kiB  | 0x00 | The FPGA bitstream |
| Partition | 64 kiB | 0x20000 | Partition table |
| Slot 0 | 128 kiB  | 0x30000 | 1st pre-loaded app |
| Slot 1 | 128 kiB  | 0x50000 | 2nd pre-loaded app |
| Storage 0 | 128 kiB  | 0x70000 | Storage for app |
| Storage 1 | 128 kiB  | 0x90000 | Storage for app |
| Storage 2 | 128 kiB  | 0xB0000 | Storage for app |
| Storage 3 | 128 kiB  | 0xD0000 | Storage for app |
| Partition 2 | 64 kiB | 0xf0000 | Backup of parititon table |

The storage area `Bitstream` is for development and prototyping
purposes with a TKey Unlocked. For normal use of a TKey the bitstream
should be programmed in the NVCM memory inside the FPGA and locked for
re-programming.

The partition table is made up of:

| **name**  | **size** |
|---|---|
| Version | 1 B |
| App 0 | 4 B length, 32 B digest, 64 B signature, 32 B pubkey |
| App 1 | 4 B length, 32 B digest, 64 B signature, 32 B pubkey |
| Storage 0 | 1 B status, 16 B nonce, 16 B auth tag |
| Storage 1 | 1 B status, 16 B nonce, 16 B auth tag |
| Storage 2 | 1 B status, 16 B nonce, 16 B auth tag |
| Storage 3 | 1 B status, 16 B nonce, 16 B auth tag |
| Checksum  | 32 B |

- Digest is a BLAKE2s hash digest of the app.
- Signature is an Ed25519 signature of the above digest.
- Pubkey is an Ed25519 pubkey which can verify the signature above.
- Checksum is a BLAKE2s hash digest of everything that came before.
  Usual to detect broken flash and a signal to use the backup copy.

The digest, signature and pubkey are reported from the
`PRELOAD_GET_METADATA` system call as a part of chaining of apps. See
Management app, chaining apps and verified boot.

The storage status field is 0 if not allocated by an app and 1 if
allocated.

The storage auth tag is a way of controlling if a device app can
access a storage area. It's computed with the 16 byte version of the
BLAKE2s hash function like this:

```C
digest = BLAKE2s_16(
    key = CDI,
    data = nonce)
```

The auth tag is filled in when a device app first allocates an area.
It is then checked on all calls to access the app storage area.

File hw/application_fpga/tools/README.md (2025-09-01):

# Tools

We have developed some tools necessary for the build.

- `app_bin_to_spram_hex.py`: Script used to include a device app in a
  testbench simulation.

- `b2s`: Compute and print a BLAKE2s digest over a file. Used for the
  digest of the app in app slot 0 included in the firmware.

- `load_preloaded_app.sh`: Script to load two copies of the partition
  table to flash and a pre-loaded to app slot 0 or 1. Needs
  `default_partition.bin`, generated with `tkeyimage` and the binary
  of the device app to load. Call like:

  ```
  ./tkeyimage/tkeyimage -app0 path/to/binary -o default_partition.bin
  ./load_preloaded_app 0 path/to/binary
  ```

- `makehex.py`: Used to build hex version of firmware ROM for FPGA
  bitstream build.

- `patch_uds_udi.py`: Script used to patch in the Unique Device Secret
  in `data/uds.hex` and the Unique Device Identifier in `data/udi.hex`
  into the bitstream without having to rebuild the entire bitstream.

- `run_pnr.sh`: Script to run place and route with `nextpnr` in order
  to find a routing seed that will meet desired timing.

- `tkeyimage`: Utility to create and parse a partition table or entire
  flash images with a TKey filesystem. You can flash the image with
  the [iceprog tool](https://github.com/tillitis/icestorm/). Remember
  to flash the flash image first and the FPGA bitstream afterwards.

- `tpt/tpt.py`: Utility to create the Unique Device Secret (UDS) and
  Unique Device Identity (UDI) interactively.

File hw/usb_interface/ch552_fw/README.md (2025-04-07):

# CH552 USB-to-Serial firmware

## Toolchain setup

SDCC:

    sudo apt install build-essential sdcc

chprog (for flashing the firmware to a device):

    cd ~
    sudo apt install libusb-1.0-0-dev
    git clone https://github.com/ole00/chprog.git
    cd chprog
    ./build_linux.sh
    sudo cp chprog /usr/local/bin

## Usage

Build the firmware using a default serial number:

    make

Flash the firmware to a device:

    make flash_patched

## Re-programming the firmware

By design, once the USB to serial firmware is loaded onto the chip,
there isn't an intended way to reflash it using only software.
However, if 3.3V is applied to the D+ line through a 10K resistor
during power-up, then the CH552 will enter bootloader mode, and a new
firmware can be programmed onto the chip.

The Blinkinlabs CH55x Reset Controller can help you do this:

https://shop-nl.blinkinlabs.com/products/ch55x-reset-controller

https://github.com/Blinkinlabs/ch55x_programmer

Note that the CH552 flash is only guaranteed for a few hundred flash
cycles.

## License

Originally based on reference firmware for the CH552 by WCH released
under the MIT license:

https://www.wch-ic.com/

The oldest files Copyright 1999.

Much changed and added to by Tillitis.

Check licenses using the reuse tool:

https://github.com/fsfe/reuse-tool

Note that so far you need to specify this directory as root, as in:

```
$ reuse --root . lint
```

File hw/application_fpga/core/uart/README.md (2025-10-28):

uart
====

A simple universal asynchronous receiver/transmitter (UART) core
implemented in Verilog. The core is completed and has been used in
several FPGA designs.

## Introduction

The UART core is used as main communication channel between the TKey
device System on Chip (SoC) and the TKey client. The UART contains a
512 byte receive buffer, allowing the SW running on the SoC to not
have to wait for bytes and poll them as soon as they are received. The
number of bytes in the FIFO is also exposed to the SW through the
ADDR_RX_BYTES address.

The number of data and stop bits can be configured prior to building
the core.

The bit rate can also be configured prior to building the core. It
should be based on the target clock frequency divided by the bit rate
in order to hit the center of the bits. For example, a clock of 18 MHz
and a target bit rate of 62500 bps yields:
Divisor = 18E6 / 62500 = 288

The UART core includes hardware flow control in the form of two CTS
lines. One input that the core will check before sending bytes, and
one output to signal to a connected device that the internal FIFO is
full. The CTS are active-low.

## API

```
ADDR_RX_STATUS: 0x20
ADDR_RX_DATA:   0x21
ADDR_RX_BYTES:  0x22

ADDR_TX_STATUS: 0x40
ADDR_TX_DATA:   0x41
```

## Implementation notes.

The FIFO allocates a single block RAM (EBR).

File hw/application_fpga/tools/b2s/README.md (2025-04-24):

# b2s

The firmware included a BLAKE2s digest of the expected device app in
the first app slot. The firmware refuses to start the app if the
computed digest differs from the constant.

To simplify computing the digest, use this tool with the `-c` flag for
including the digest in a C program:

## Building

`go build`

## Running

```
./b2s -m b2s -c
// BLAKE2s digest of b2s
uint8_t digest[32] = {
0x17, 0x36, 0xe9, 0x4e, 0xeb, 0x1b, 0xa2, 0x30, 0x89, 0xa9, 0xaa, 0xe, 0xf2, 0x6f, 0x35, 0xb2, 0xa9, 0x89, 0xac, 0x64, 0x63, 0xde, 0x38, 0x60, 0x47, 0x40, 0x91, 0x4e, 0xd7, 0x72, 0xa0, 0x58,
};
```

To print the digest in a more user friendly way, leave out the `-c`:

```
./b2s -m b2s
1736e94eeb1ba23089a9aa0ef26f35b2a989ac6463de38604740914ed772a058 b2s
```

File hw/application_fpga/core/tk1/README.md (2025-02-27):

# tk1

## Introduction

The tk1 core is where information, control and monitoring
functionality unique to the TKey1 can be found. This means that it
provides more than one distinct functionality accessible via the core
API.

## API

### Access to device information

```
ADDR_NAME0:   0x00
ADDR_NAME1:   0x01
ADDR_VERSION: 0x02
```

These addresses provide read only information about the name (type)
and version of the device. They can be read by FW as well as
applications.

### Control of RGB LED

```
ADDR_LED:  0x09
LED_B_BIT: 0
LED_G_BIT: 1
LED_R_BIT: 2
```

This register control the RGB LED on the TKey device. Setting a bit to
one turns the corresponding color on. It can be read and written by FW
as well as by Apps.

### Control and status of GPIO

```
ADDR_GPIO: 0x0a
GPIO1_BIT: 0
GPIO2_BIT: 1
GPIO3_BIT: 2
GPIO4_BIT: 3
```

This register control and provide status access to the four GPIOs on
the TKey. GPIO one and two are inputs. They will sample the input
level and present it to SW. GPIO three and four are outputs. They will
emit either high or low voltage level depending on if the
corresponding register is one or zero.

### Application introspection

```
ADDR_APP_START: 0x0c
ADDR_APP_SIZE:  0x0d
```

These registers provide read only information to the loaded app to
itself - where it was loaded and its size. The values are written by
FW as part of the loading of the app. The registers can't be written
in application mode.

### Access to CDI

```
ADDR_CDI_FIRST: 0x20
ADDR_CDI_LAST:  0x27
```

These registers provide access to the 256-bit compound device secret
calculated by the FW as part of loading an application. The registers
are written by the FW. The register can't be written in application
mode. The CDI is readable by apps, which can then use it as a base
secret for any other secrets required to carry out their intended use
case.

### Access to UDI

```
ADDR_UDI_FIRST: 0x30
ADDR_UDI_LAST:  0x31
```

These read-only registers provide access to the 64-bit Unique Device
Identity (UDI).

The two UDI words are stored using 32 named SB\_LUT4 FPGA multiplexer
(MUX) instances, identified in the source code as "udi\_rom\_idx". One
instance for each bit in core read_data output bus.

Each SB\_LUT4 MUX is able to store 16 bits of data, in total 512 bits.
But since the UDI is 64 bits, we only use the two LSBs in each MUX.
Note that only the LSB address of the SB\_LUT4 instances are connected
to the CPU address. This means that only the two LSBs in each MUX can
be addressed.

During build of the FPGA design, the UDI is set to a known bit
pattern, which means that the SB\_LUT4 instantiations are initialized
to a fixed bit pattern.

The tool 'patch\_uds\_udi.py' is used to replace the fixed bit pattern
with a unique bit pattern before generating the per device unique FPGA
bitstream. This allows us to generate these device unique FPGA
bitstreams without having to do a full FPGA build.

### RAM memory protection

```
ADDR_RAM_ADDR_RAND: 0x40
ADDR_RAM_DATA_RAND: 0x41
```

These write only registers control how the data in the RAM is
randomized as a way of protecting the data. The randomization is
implemented using a pseudo random number generator with a state
initialized by a seed.

The `ADDR_RAM_ADDR_RAND` store the seed for how the addresses are
randomized over the memory space. The `ADDR_RAM_DATA_RAND` store the
seed for how the data itself is randomized. FW writes random seed
values to these registers during boot.

### Security monitor

```
ADDR_CPU_MON_CTRL: 0x60
ADDR_CPU_MON_FIRST:0x61
ADDR_CPU_MON_LAST: 0x62
```

Monitors events and state changes in the SoC and handles security
violations. Currently checks for:

1. Trying to access memory that is outside of the defined size of the
   defined memory areas. *Always enabled*
2. Trying to execute instructions in FW\_RAM. *Always enabled.*
3. Trying to execute instructions from a memory area in RAM defined by
   the application.

Number 1 and 2 are always enabled. Number 3 is set and enabled by the
device application. Once enabled, by writing to `ADDR_CPU_MON_CTRL`,
the memory defined by `ADDR_CPU_MON_FIRST` and `ADDR_CPU_MON_LAST`
will be protected against execution. Typically the application
developer will set this protection to cover the application stack
and/or heap.

An application can write to these registers to define the area and
then enable the monitor. Once enabled the monitor can't be disabled,
and the `ADDR_CPU_MON_FIRST` and `ADDR_CPU_MON_LAST` registers can't be
changed. This means that an application that wants to use the monitor
must define the area first before enabling the monitor.

Once enabled, if the CPU tries to read an instruction from the defined
area, the core will force the CPU to instead read an all zero, which
is an illegal instruction. This illegal instruction will trigger the
CPU to enter its TRAP state, from which it can't return unless the
TKey is power cycled.

The firmware will not write to these registers as part of loading an
app. The app developer must define the area and enable the monitor to
get the protection.

One feature not obvious from the API is that when the CPU traps the
core will detect that and start flashing the status LED with a red
light indicating that the CPU is in a trapped state and no further
execution is possible.

## SPI-master

The TK1 includes a minimal SPI-master that provides access to the
Winbond Flash memory mounted on the board. The SPI-master is byte
oriented and very minimalistic.

In order to transfer more than a single byte, SW must read status and
write commands needed to send a sequence of bytes. In order to read
out a sequence of bytes from the memory, SW must send as many dummy
bytes as the data being read from the memory.

The SPI-master is controlled using a few API
addresses:

```
ADDR_SPI_EN:   0x80
ADDR_SPI_XFER: 0x81
ADDR_SPI_DATA: 0x82
```

`ADDR_SPI_EN` enables and disabled the SPI-master. Writing a 0x01 will
lower the SPI chip select to the memory. Writing a 0x00 will raise the
chip select.

Writing to the `ADDR_SPI_XFER` starts a byte transfer. Reading from
the address returns the status for the SPI-master. If the return value
is not zero, the SPI-master is ready to send a byte.

`ADDR_SPI_DATA` is the address used to send and receive a byte. data.
The least significant byte will be sent to the memory during a
transfer. The byte returned from the memory will be presented to SW if
the address is read after a transfer has completed.

The sequence of operations needed to perform is thus:

1. Activate the SPI-master by writing a 0x00000001 to ADDR_SPI_EN
2. Write a byte to `ADDR_SPI_DATA`
3. Read `ADDR_SPI_XFER` to check status. Repeat until the read
   operation returns non-zero value
4. Write to `ADDR_SPI_XFER`
5. Read `ADDR_SPI_XFER` to check status. Repeat until the read operation
   returns a non-zero value
6. Read out the received byte from `ADDR_SPI_DATA`
7. Repeat 2..6 as many times as needed to send a command and data to
   the memory and getting the expected status, data back.
8. Deactivate the SPI-master by writing 0x00000000 to `ADDR_SPI_EN`

The SPI connected memory on the board is the Winbond W25Q80. For
information about the memory including support commands and protocol,
see the datasheet:

https://www.mouser.se/datasheet/2/949/w25q80dv_dl_revh_10022015-1489677.pdf

## System Reset

The TK1 includes an ability for FW and applications to trigger a
hardware reset of the FPGA by writing to an API address.

The hardware reset will force all registers that are in the Tkey FPGA
design reset circuit to be reset to their default values. Basically
this is all registers in the Tkey FPGA design.

The reset will not clear the RAM. However since the CPU program
counter is reset to its reset vector, the CPU will unconditionally
start executing the FW. As part of the device initialization, the FW
will fill the RAM with random data, overwriting any app and
data present in the RAM before the reset was triggered.

The hardware reset will not force the FPGA to read its
configuration. That requires a power cycle of the Tkey device.

The reset is controlled by the following API address. Note that
any value written to the address will trigger the reset.

```
ADDR_SYSTEM_RESET: 0x70
```

## Implementation

The core is implemented as a single module. Future versions will
probably be separated into separate modules.

## Winbond Flash memory model

The testbench for the SPI master requires a memory model of the
Winbond Flash memory. The model [can be downloaded from
Winbond](https://www.winbond.com/hq/support/documentation/downloadV2022.jsp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)
by providing the requested information and supplying the received
verification code.

From the downloaded file 'W25Q80DL.zip', please extract the file
W25Q80DL.v and place it in the 'tb' directory before building the
simulation model.

---

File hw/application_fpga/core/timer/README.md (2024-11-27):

# timer
A simple timer with prescaler.

## Introduction
This core implements a simple timer with a prescaler. The prescaler
can be used to divide the system clock frequency to yield a specific
amount of clock frequency ticks for each timer tick. This allows
measurement of time rather than cycles. If for example setting the
prescaler to the clock frequency in Hertz, the timer will count
seconds.

## API

The following addresses define the API for the timer:

```
	ADDR_CTRL: 0x08
	CTRL_START_BIT: 0
	CTRL_STOP_BIT:  1

	ADDR_STATUS: 0x09
	STATUS_RUNNING_BIT: 0

	ADDR_PRESCALER: 0x0a
	ADDR_TIMER:     0x0b
```

## Details
The core consists of the timer_core module (in timer_core.v) and a top
level wrapper, timer (in timer.v). The top level wrapper implements
the API, while the timer_core implements the timer functionality.

The timer counter and the prescaler counter are both 32 bits. Both the
`prescaler` and the `timer` register can be set through the API above,
and should be a non-zero value, the defaults are one. These values
cannot be changed when the timer is running.

Bit zero of the `status` register shows if the timer is running, one
indicates a running timer.

Start the timer by writing 1 to bit zero of the `ctrl` register, write
1 to bit one to stop it.

Time elapsed can be calculated using:

```
time = clock_freq / (prescaler * timer)
```

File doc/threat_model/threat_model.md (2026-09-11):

# Tillitis TKey threat model

## Introduction

The Tillitis TKey is a platform for running small programs (device
applications) in a physically separated and restricted execution
environment. The device app on the TKey typically provides
functionality to a companion client app for different use cases:
cryptographic signing, authentication, encryption, et cetera.

The TKey provides the device app a secret derived through measurement
of the device app or, when chaining, a secret generated from a chain
of apps.

For more about the TKey, see [TKey Developer
Handbook](https://dev.tillitis.se/), [the firmware
documentation](../../hw/application_fpga/fw/README.md) or [the top
level hardware documentation](../../hw/application_fpga/README.md).

This threat model tries to describe the threats that needs to be
mitigated in order for the device app to work in a secure and
trustworthy manner.

TL;DR:

- We believe that a successful attack reproducing the same key
  material will need access to both the user's User Supplied Secret
  (something they know) and physical access to the TKey device
  (something they have).

- When using measured boot we believe the attacker *also* needs to run
  the exact same device app.

- When using chained apps we believe the attacker *also* needs to run
  the exact same device app as the first app in the chain.

- If the first app is our boot verifier we believe the attacker *also*
  needs access to the vendor's private and public key to get the same
  secret. Other verifying apps might have similar requirements.

- We think there are some assets (EBR) available to someone with
  physical access and the knowledge and equipment to do a warm boot
  attack replacing the FPGA configuration while the FPGA chip is
  running. See [Known weaknesses](#known-weaknesses).

- The TKey should be able to withstand software based attacks from the
  client.

- The TKey should be able to make evil maid attacks either take long
  enough that a user will discover that their TKey is missing or an
  attack can be detected after the fact. Regardless, the keys
  generated will be the wrong keys.

### TKey Unlocked

The TKey is available in two versions: the ordinary TKey for general
use and the TKey Unlocked. The Unlocked is for users who want to
provision the bitstream themselves, either because they want to choose
the Unique Device Secret themselves or want to change the hardware
design or the firmware.

The threat model and the mitigations listed applies to unlocked
devices too as long as they have been provisioned with:

- the bitstream from the official release,
- a unique, random UDS,
- a unique UDI

The configuration must have been written into the NVCM and locked by
blowing the fuses.

TODO Might need to remove above if we rely on new casing as
mitigations in the threat model.

## Assumptions

- The security boundary is the FPGA itself. The client, the CH552 USB
  controller, and the flash chip, are outside of the security
  boundary, even if we make our best efforts to secure them they are
  basically outside of our control.

- There are no backdoors or vulnerabilities in Lattice iCE40 UltraPlus
  FPGA devices that allow external access to the internal
  configuration memory (Non-Volatile Configuration Memory, NVCM) after
  the device configuration has been written to the NVCM and external
  access has been locked down through the fuses.

- There is no access path to the contents of the NVCM from the FPGA
  fabric besides the configuration circuit.

- The FPGA development toolchain, including YoSys, NextPnR and
  IceStorm generates a correct design, and also does not inject
  hardware exfiltration mechanisms in the generated bitstream.

- The end user is not an attacker. The end user at least doesn't
  knowingly aid the attacker in attacks on their device.

## Assets

- UDS - Unique Device Secret.

  Provisioned and stored in the FPGA NVCM during TKey device
  provisioning. Never to be replaced or altered during the life time
  of a given TKey device. Used to derive application secrets. Must
  never leave the device. Tillitis must not store a copy of the
  UDS.

- UDI - Unique Device ID.

  Provisioned and stored in the FPGA NVCM during TKey device
  provisioning. Never to be replaced or altered during the life time
  of a given device. Not secret, although the second half (serial
  number) is more sensitive, since it uniquely identifies a specific
  device.

- USS - User Supplied Secret.

  Provisioned by the user from the client during loading of the device
  app. Should not be revealed to a third party.

- CDI - Compound Device Identity.

  A secret computed by firmware. Used by the device app to derive
  cryptographic keys et c. as needed. The CDI should never be exposed
  outside of the FPGA.

- Vendor public key.

  Used in a verified boot scenario to verify the next app to start.

  The vendor public key can either be stored on the flash and be
  associated with the device app in slot 1 or be fed to a boot
  verifier app from the client.

- Vendor private key.

  Used by a vendor to sign device apps that are meant to get the same
  CDI by a combination of measured boot and verified boot.

  Not kept on TKey, so handling not in scope in this threat model, but
  handling of the vendor private key is crucial for the verified boot
  scenario.

- Filesystem partition table.

  Partition table on the TKey flash. Keeps metadata about the vendor
  key, preloaded apps, and app storage slots.

- Firmware RAM.

  The firmware has its own memory, `FW_RAM`. It does all its sensitive
  computations here.

- Firmware ROM.

  Firmware is stored and executed from `FW_ROM`.

- RAM.

  The TKey has a memory where the device app is loaded and executed.
  It's available for the apps.

- Firmware mode.

  The TKey has two execution modes: firmware mode and app mode.
  Firmware mode has more priveleges. When running in firmware mode the
  entire memory map (including some of the other assets listed here)
  are available for read and write access.

- Preloaded apps.

  The TKey comes with two preloaded apps stored in slot 0 and slot 1,
  the boot verifier and the FIDO2 app. By default they are started in
  a chain.

- Verification files

  Published files used by the The [TKey Verification
  System](https://github.com/tillitis/tkey-verification). Includes a
  Sigsum proof over a message and some metadata the user can recreate
  from this data.

## Threats and mitigations

There are two major type of attacks

1. Software (SW) based. These are attacks against the TKey device that
   are performed from a client and enter the TKey device through the
   USB port. The SW attacks includes buffer overflow attacks and
   attacks on the firmware protocol.

2. Hardware (HW) based. These are attacks against the FPGA design of
   the TKey device as well as the PCB. The HW attacks includes fault
   injection, side-channel leakage as well as warm boot attacks. These
   attacks may be performed from the client through the USB port,
   through the TKey enclosure, or near the TKey device.

## In scope

- SW attacks from the client against the firmware in the FPGA, the
  boot verifier in flash slot 0, and against the FPGA design itself
  via USB.

- Timing attacks on the firmware and the FPGA design.

## Out of scope

- All physical and electrical attacks applied to the board, including:

  - Reading out of the UDS from the external flash chip. A bitstream
    on flash is not used in production, only development.

  - Triggering of the FPGA warm boot functionality. It should be hard
    to successfully perform against the TKey, but the attack is not
    yet fully mitigated.

  - Triggering firmware update of the CH552 MCU, using the port
    knocking mechanism.

- Glitching attacks including:

  - Faulting of the execution by the CPU in the FPGA and the CH552
    MCU.

  - Disturbing of the TRNG entropy generation.

- Electromagnetic leakage.

- Attacks on the TKey device apps, except the special case the boot
  verifier in slot 0, which we count as a trusted boot stage.

- Attacks on Tillitis' infrastructure outside of the TKey itself.

### General physical attacks

Threat: Opening the TKey to access the chips and the programming pins.

Mitigation:

- A transparent TKey casing glued together which makes it harder to
  open up without leaving physical marks indicating tamper attempts.

### General memory map attacks

Threats:

- Illegal execution.
- Illegal access.

Mitigation:

- Depending on the hardware mode (firmware mode/app mode), different
  areas of the memory map are available. Unmapped or unavailable
  memory forces the CPU into a trap state that requires a reboot. This
  state is indicated by the hardware by slowly flashing the status LED
  red. No software execution takes place.

### Firmware fuzzing

Threat: Finding exploits in the firmware.

Mitigation:

- Firmware has a strict protocol state machine. Illegal messages in a
  specific state leads to a CPU trap state that requires a reboot.

### UDS

Threat: Leaking or changing to known value.

Mitigations:

- The UDS is part of the bitstream, locked down within the NVCM in the
  FPGA chip and can't be read or changed after locking.

  The data in NVCM shouldn't be visible on X-ray and isn't visible
  with microscopes, even SEM. See Lattice's whitepaper [Security
  aspects of Lattice semiconductor iCE40 mobile FPGA
  devices](https://www.latticesemi.com/-/media/LatticeSemi/Documents/WhitePapers/NZ/SecurityAspectOfLatticeSemiconductor-English-090313.ashx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).

- The UDS is implemented as hardware registers, not EBR, so it's not
  vulnerable to a warm boot attack.

- The hardware design allows only one read of the entire UDS once per
  reset, meant to be done by the firmware.

- The firmware reads out UDS exactly once and keeps it in the special
  firmware RAM for a very short period while doing the CDI
  computation, almost immediately discarding it after just a few
  instructions. In order not to keep the UDS in `FW_RAM` on
  predictable cycles, it randomizes when the UDS handling takes place
  using the TRNG.

- UDS is generated and provisioned in an airgapped environment. It's
  kept only until the bitstream for that particular device is
  provisioned and then deleted.

- `tkey-verify` is used by the user to verify that the UDS is
  unchanged from time of provisioning. Usage:

  https://www.tillitis.se/applications/tkey-device-verification/

  Repo with source code and detailed documentation:

  https://github.com/tillitis/tkey-verification

### UDI

Threats:

- Changing after provisioning.
- Behave maliciously for specific devices.

Mitigations:

- The UDI is part of the bitstream, locked down within the NVCM in the
  FPGA chip. The NVCM is write-once and then locked down. According to
  our assumptions it's no longer changeable.

- The second part of the UDI, the serial number, is not available to
  device apps, only the vendor ID and product ID (see `sys_get_vidpid`
  syscall). A malicious device app can't access the serial number and
  can therefore not behave maliciously for a specific device and not
  others.

### USS and USS digest

Threat: Leaking.

Mitigations:

- On the client side, our apps use the pinentry protocol to get the
  USS. They usually depend on gnome3-pinentry on Linux and Gpg4Win on
  Windows, but this isn't enforced. The protection is weak.
  Keyloggers, especially on X11, would probably leak the USS.

- The firmware uses the USS digest in the CDI computation. The memory
  the digest was kept in is wiped and made unavailable to the device
  app by hardware protection.

  Since the firmware does the computation, the device app doesn't even
  see the USS digest.

- On the device side, only the USS digest is handled, not what the
  user entered, but this digest is also very sensitive, as it's the
  actual argument used in the CDI computation, but this means the
  firmware can't leak what the user entered.

### CDI

Threats:

- Leaking.
- Changing by device app.
- Impersonation: one combination of USS, app, vendor key pretending to
  be another app.

Mitigations:

- Leaking (measured boot case): A malicious app designed to leak the
  CDI will leak the *wrong* secret since the CDI includes a
  measurement of the app itself.

- Leaking (verified boot case): A malicious app designed to leak the
  CDI will not be allowed to execute by the trust policy of the boot
  verifier. See [the boot verifier design
  document](https://github.com/tillitis/tkey-boot-verifier/blob/main/doc/design.md)
  for details.

- Leaking (out of scope warm boot attack): CDI is implemented as
  hardware registers, not EBR, so it's not vulnerable to reading even
  with an out of scope warm boot attack.

- Changing: CDI is protected by hardware. It is only writable in
  firmware mode, not app mode. This protects against an app changing
  its own CDI to something not measured by the firmware.

- Impersonation: We separate the CDI into domains/namespaces by
  always measuring the domain, depending on:

  1. If the app was loaded with or without USS.
  2. If the app was directly loaded (the entire app is measured) or
     verified (combination of measured boot and verified boot).

- Impersonation: When using *verified boot* the attacker is in control
  of:

  - vendor public key
  - message (the app they want to load)
  - signature over the app digest.

  It's possible to use an vendor public key with a non-canonical point
  encoding which might verify signatures over many messages. This
  means an attacker can send a correct vendor signature but use their
  own public key and a malicious app, which will still verify with the
  vendor signature.

  The mitigation is that our
  [tkey-boot-verifier](https://github.com/tillitis/tkey-boot-verifier/)
  always measures the vendor key, too, which means if they use an
  unexpected vendor key, they get the wrong CDI.

  This is, of course, also the case if someone uses a valid vendor key
  and their own signature. We're not stopping them from loading and
  executing a malicious app: we're stopping them from unlocking the
  secret.

  If the attacker use their own boot verifier app to try to verify and
  impersonate next app, the entire verifier app is *also* always
  measured, so they still get the wrong CDI.

### Vendor public key

Threat: Replaced by malicious vendor key.

Mitigations:

- Needs physical access, since it can only be done only either by
  cracking case and updating flash (out of scope) or by requesting
  that `tkey-boot-verifier` update the key, which asks the user to
  assert presence.

- Needs to be signed by current vendor private key. Enforced by the
  boot verifier in app slot 0, which cannot be modified [see Preloaded
  apps](#preloaded-apps).

### Vendor private key

Not on TKey. Out of scope, but included for reference.

Threat: Leaking or changing to malicious.

Mitigation:

- Encrypted at rest.
- Used in an airgapped environment.

### Filesystem partition table

Threats: Corruption or malicious change.

Mitigations:

- Corruption: The partition table is held in two copies on flash. It
  also contains a checksum. Firmware checks the checksum at every read
  and computes it on every write. If it ever differs, the filesystem
  is marked as suspect and the copy is used.

- Malicious change: Only firmware is allowed to change the partition
  table. Barring bugs, a malicious change will require physical
  access, breaking of the case, and accessing the flash directly,
  which is currently out of scope.

### Firmware memory (`FW_RAM`)

Threats:

- Leaking sensitive data.
- Execution.

Mitigation:

- The entire `FW_RAM` is cleared when the FPGA is powered up and the
  FPGA is configured.

- Firmware clears the `FW_RAM` except the `resetinfo` area before
  doing a reset.

- The firmware's stack in `FW_RAM` is cleared by firmware before
  jumping to an app.

- Firmware memory is hardware protected by the current execution mode.
  It is only available for reading and writing in firmware mode.

- It is at all times protected by hardware against execution.

### RAM

Threats:

- Leaking sensitive data.
- Execution of writable areas.

Mitigation:

- Execution: A device app can mark one continous area as
  non-executable, typically the areas after `.text`, up to and
  including the stack.

- Writable: No protection.

- Leaking: Firmware fills entire RAM with random data at startup to
  ensure that any rests of data that might have been present are
  wiped.

- Leaking: Firmware turns on a hardware assisted RAM address and data
  scrambling mechanism. This makes it harder for an outside attacker
  to find assets generated by and stored in the RAM by applications.
  Note that this mitigates an attack from outside the CPU, not from an
  exploit towards applications running on it.

  The address and data scrambling is initiated with different
  randomness from the TRNG at each start of the firmware.

### Firmware mode

Threat: Unlawful privilege escalation.

Mitigation:

- Hardware execution modes: Firmware mode (all access, except UDS
  after first read). App mode: Sensitive stuff not readable or
  writable (see specific assets).

- Hardware protection at app start. Execution begins in firmware mode,
  but when starting the app it automatically changes the hardware
  status to app mode, locking off sensitive areas of the memory map
  from reading and/or writing. The entire ROM, where firmware resides,
  is marked non-executable in app mode. It must still be readable,
  though, since `tkey-verify` checks it.

- Hardware protection for system call privilege escalation. In order
  to do priveleged actions the app needs to temporarily change to
  firmware mode. This is done with hardware support from an interrupt
  call.

  When this interrupt is raised, the device temporarily enters
  firmware mode and calls the system call handler in the firmware.
  Arguments are passed in registers. The firmware does the system call
  and then automatically goes back to the hardware app mode when
  returning to the app.

  See the Developer Handbook for [a list of the system
  calls](https://dev.tillitis.se/castor/syscalls/).

### Preloaded apps

Threats:

- Changed to malicious apps.
- Changed remotely.
- Bypassing verified boot.

Mitigation:

- App slot 0, containing the boot verifier, can not be changed after
  provisioning. It's app digest is mentioned in the firmware in ROM.
  Firmware will only start it if the computed digest is the same.

- App slot 1: Changing app needs user to assert presence by touching
  touch sensor. For malicious apps we rely on the app getting it's own
  CDI with the measured boot/verified boot combination so a malicious
  app cannot leak secrets.

- The TKey allows a reset to reset and start directly from slot 1,
  bypassing the boot verifier in slot 0. However, the CDI computed
  will then be different since the app in slot 1 will be measured
  directly, and not use verified boot at all.

## Known weaknesses

- All RAM is writable in both firmware and app mode, even addresses
  marked executable.

- It's possible to change the configuration of the Lattice iCE40
  UltraPlus FPGA while the power is on even when the NVCM is locked.
  See "Security of the On-Chip CRAM and BRAM" in Lattice's whitepaper
  [Security aspects of Lattice semiconductor iCE40 mobile FPGA
  devices](https://www.latticesemi.com/-/media/LatticeSemi/Documents/WhitePapers/NZ/SecurityAspectOfLatticeSemiconductor-English-090313.ashx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).

  > On resetting the product with power still applied, it is possible
  > to insert a new program in CRAM that will read the BRAM data out.
  >
  > However, on resetting the product, the CRAM memory itself is fully
  > erased and there is no possible way to read the CRAM data externally.
  >
  > Therefore, storing Digital Key data in the NVCM with the
  > protection flag set, and then sending that secure data to the CRAM
  > memory of the chip, there is no way to extract it.

  A warm boot leaves the EBR (what the whitepaper calls BRAM) and
  SPRAM intact after the new configuration is loaded, and the contents
  of the EBR and SPRAM can leak. "CRAM" in the quoute is the
  configuration memory the bitstream is in when the chip has power.

  Mitigations:

  - Requires physical access.

  - Requires breaking the case.

  - UDS is stored in locked-down NVCM and in registers in CRAM when
    running. It is not in SPRAM nor EBR, except for a very short
    moment when firmware computes CDI. See [UDS](#UDS) protection
    above.

  - SPRAM is protected by a scrambling mechanism. See above under
    [RAM](#RAM).

  - EBR is not protected, so any hardware cores that use EBR is still
    vulnerable.

    These use EBR:

    - `CPU register x1 to x31`.
    - `FW_RAM`, including the `resetinfo` that is kept over soft
      resets.
    - `FW_ROM`.
    - `UART`, specifically the Rx-FIFO.

- The CH552 MCU USB weaknesses

  Asset: CH552 firmware.

  Threat: Change of firmware to listen and modify to communication
  between client app and device app. For instance:

    - The controller firmware can be updated over USB.

      An attacker with physical access to the TKey and a CH55x
      programmer board can change the USB controller firmware. This
      means they can listen to and modify all communication between
      the client and the firmware and the client and a device app.

    - There may be vulnerabilities in the CH552 firmware reachable
      through USB allowing both controlled execution and modification
      of the CH552 firmware.

  These are outside the security boundary defined above but mentioned
  since a user can actively do a test to mitigate the threat.

  Partial mitigation: `tkey-verify` uses a cryptographic
  challenge/response against a known public key with a device app.
  Succesfully verifying the signature by running `tkey-verify`
  verifies that the communication, at least for those commands, is not
  modified.

## Threat Actors - The bad guys

Different actors have different reasons for performing attacks. They
have also different access to competence, resources etc. This
description tries to capture examples of possible attacks and how the
TKey device should be able to stand up against them.

### 0. Average Joe
[Average Joe Soundtrack](https://www.youtube.com/watch?v=BB0DU4DoPP4)

* Curious opportunist
* No real competence, no resources beyond a personal computer
* No planning or preparation before an attack
* Prepared to invest little time (minutes) or resources - for example
  to connect a device found, try a few user supplied secrets
* End game is to gain access to possible information, client resources
  unknown to the attacker before the attack is performed

Attacks by Average Joe will come from the USB port and is SW based, or
just manual attempts. Given a hard to guess USS, the TKey Device
should withstand any attack no matter how long time the attack is
allowed

### 1. The CCC Hacker
[CCC Hacker Soundtrack](https://www.youtube.com/watch?v=l8DBEbmPh7E)

* Sympathetic to the goals of the project
* Wants to probe all parts and the system in a quest to determine how
  the device really works, use it in possibly different ways, find
  weaknesses (and get them fixed)
* Is possibly a user, but in this case not the legitimate end user
* Have a high level of competence
* Prepared to spend time to prepare and perform an attack. Possibly low
  effort over an extended period
* Access to compute resources. Possibly access to lab equipment
* Will try all possible SW and HW attack vectors. In and out of scope
* End game is to find flaws in threat model. Acquire knowledge and
  findings to produce an interesting talk at Chaos Communication
  Congress, USENIX or Security Fest

Over time (with new releases), and given feedback by the CCC Hacker,
the TKey device should be able to withstand attacks by the CCC Hacker.

### 2. vERyRevil
[vERyRevil Soundtrack](https://www.youtube.com/watch?v=sTSA_sWGM44)

* Ransomware gang. Driven by short term financial gain
* Short term focus. Fastest possible access to economic assets
* Have, or can acquire high level of competence
* Have access to large amount of resources
* Have time and is prepared to spend time on preparations
* Short time to perform an attack. Will not persist for a long time
* Will do strict cost benefit-analysis to decide to perform, abort
  attacks if they don't work
* SW based attacks. Is assumed to remotely own the host
* Supply chain attacks on secure application, host application, SDK,
  infiltration of device and application development
* End game is to gain access, control over resources protected by the
  device. Resources that can be used as leverage for financial gain

Over time (with new releases), The TKey device should be able to
withstand SW attacks by vERyRevil.

### 4. APT4711
[APT4711 Soundtrack](https://www.youtube.com/watch?v=lrWV6pxepDo)

* State actor
* Interested in access to information, perform surveillance, and
  possibly control of the end user or resources
* Long term focus. Attacks are discreet and persistent
* Access to high competence
* Access to very large amounts of resources
* Prepared to invest a lot of time, effort to prepare and execute an
  attack
* Prepared to perform physical visits (evil maid missions) at target
  (end user) as well as Tillitis or the suppliers to Tillitis as
  needed to manipulate, steal, replace components, systems
* SW based attacks. Is assumed to remotely own the host
* Supply chain attacks - both on SW and HW, components
* Supply chain attacks on application, host application, SDK,
  development
* End game: Long term stealth presence providing access to information
  about the end user

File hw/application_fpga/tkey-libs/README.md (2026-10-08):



# Device libraries for the Tillitis TKey

- C runtime: libcrt0.
- System call support: libsyscall.
- Common C functions including protocol calls: libcommon.
- Cryptographic functions: libmonocypher. Based on
  [Monocypher](https://github.com/LoupVaillant/Monocypher) version
  4.0.3
- BLAKE2s hash function: libblake2s.

Release notes in [RELEASE.md](RELEASE.md).

## Licenses

Unless otherwise noted, the project sources are copyright Tillitis AB,
licensed under the terms and conditions of the "BSD-2-Clause" license.
See [LICENSE](LICENSE) for the full license text.

Until Oct 8, 2024, the license was GPL-2.0 Only.

External source code we have imported are isolated in their own
directories. They may be released under other licenses. This is noted
with a similar `LICENSE` file in every directory containing imported
sources.

Imported sources:

- [Monocypher](https://github.com/LoupVaillant/Monocypher)
  (BSD-2/CC-0) by Loup Vaillant.
- blake2s (CC-0), originally based on the reference implementation in
  [RFC 7693](https://www.rfc-editor.org/rfc/rfc7693.html) written by
  Markku-Juhani O. Saarinen ([original
  repository](https://github.com/mjosaarinen/blake2_mjosref). Imported
  from [Joachim Strömbergson's
  fork](https://github.com/secworks/blake2s/) used as a model for a
  hardware implementation.

### SPDX tags

The project uses single-line references to Unique License Identifiers
as defined by the Linux Foundation's [SPDX project](https://spdx.org/)
on its own source files, but not necessarily imported files. The line
in each individual source file identifies the license applicable to
that file.

The current set of valid, predefined SPDX identifiers can be found on
the SPDX License List at:

https://spdx.org/licenses/

We attempt to follow the [REUSE
specification](https://reuse.software/).

## Hardware support

### Bellatrix and earlier

Please note that:

- For reading, only use the blocking `read(IO_UART,..)` or
`serial_read()`.

- Only `IO_UART` and `IO_QEMU` destinations are useful for writing as
  in `write(IO_UART, ...)`, `puts(IO_UART, ...)`, and so on.

- Defining `QEMU_DEBUG` works with all the `debug_*` functions, but
  `TKEY_DEBUG` does not.

## Building

In order to build, you must have the `make`, `clang`, `llvm`, and
`lld` packages installed.

Version 15 or higher of LLVM/Clang is necessary for the RV32IC\_Zmmul
architecture we are using. For more detailed information on the
supported build and development environment, please refer to the
[Developer Handbook](https://dev.tillitis.se/).
## Building using Podman

You can also build the libraries with our OCI image
`ghcr.io/tillitis/tkey-builder`.

The easiest way to build this is if you have `make` installed:

```
make podman
```

You can also specify a different image by using
`IMAGE=localhost/tkey-builder-local`.

Or use Podman directly:

```
podman run --rm --mount type=bind,source=.,target=/src -w /src -it ghcr.io/tillitis/tkey-builder:4 make -j
```

## Minimal application build

You will typically need to link at least the `libcrt0` C runtime
otherwise your program won't even reach `main()`.

We provide a linker script in `apps.lds` which shows the linker the
memory layout.

Minimal compilation would look something like:

```
clang -target riscv32-unknown-none-elf -march=rv32iczmmul -mabi=ilp32 \
  -mcmodel=medany -static -std=gnu99 -O2 -ffast-math -fno-common \
  -fno-builtin-printf -fno-builtin-putchar -nostdlib -mno-relax -flto \
  -Wall -Werror=implicit-function-declaration \
  -I ../tkey-libs/include \
  -I ../tkey-libs -c -o foo.o foo.c

clang -target riscv32-unknown-none-elf -march=rv32iczmmul -mabi=ilp32 \
  -mcmodel=medany -static -ffast-math -fno-common -nostdlib \
  -T ../tkey-libs/app.lds \
  -Wl,--gc-sections,--print-gc-sections \
  -L ../tkey-libs -lcrt0 \
  -I ../tkey-libs -o foo.elf foo.o
```

Note the `--gc-sections` which you need to remove unused sections. For
instance, the recently added support for division means that you
otherwise would get a kilobyte-large table included in your device app
even if you don't use division.

Since the TKey doesn't accept ELF binaries, you now have to strip the
ELF header to produce a raw binary:

```
llvm-objcopy --input-target=elf32-littleriscv --output-target=binary foo.elf foo.bin
```

## Makefile example

See `example-app/Makefile` for an example Makefile for a simple device
application.

## Debug output

If you want to have debug prints in your program you can use the
`debug_putchar()`, `debug_puts()`, `debug_putinthex()`,
`debug_hexdump()` and friends. See `include/tkey/debug.h` for list of
functions.

These functions will be turned on if you define either of these when
compiling your program and linking with `libcommon`:

- `QEMU_DEBUG`: Uses the special debug port only available in qemu to
  print to the qemu console.
- `TKEY_DEBUG`: Uses the extra HID device.

Note that if you use `TKEY_DEBUG` you *must* have something listening
on the corresponding HID device. It's usually the last HID device
created. On Linux, for instance, this means the last reported hidraw
in `dmesg` is the one you should do `cat /dev/hidrawX` on.

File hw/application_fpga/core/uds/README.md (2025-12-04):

# uds

Unique Device Secret core

## Introduction

This core store and protect the Unique Device Secret (UDS) asset. The
UDS can be accessed as eight separate 32-bit words. The words can only
be accessed as long as the `en` input is high.

The UDS words can be accessed in any order, but a given word can only
be accessed once between reset cycles. This read once functionality is
implemented with a companion read bit for each word. The read bit is
set when the word is first accessed. The read bit controls if the real
UDS word is returned or not.

This means that the even if the chip select (cs) control
input is forced high, the content will become all zero when the read
bit has been set after one cycle.

## API

Three address bits are used. Addresses 0-7 address each of the UDS
words. All words are read-only and read-once between reset.

## Implementation

These read-only registers provide read access to the 256-bit UDS.

The eight UDS words are stored using 32 named SB\_LUT4 FPGA
multiplexer (MUX) instances, identified in the source code as
"uds\_rom\_idx". One instance for each bit in the core read\_data
output bus.

During build of the FPGA design, the UDS is set to a known bit
pattern, which means that the SB\_LUT4 instantiations are initialized
to a fixed bit pattern.

The tool 'patch\_uds\_udi.py' is used to replace the fixed bit pattern
with a unique bit pattern before generating the per device unique FPGA
bitstream. This allows us to generate these device unique FPGA
bitstreams without haveing to do a full FPGA build.

Each SB\_LUT4 MUX is able to store 16 bits of data, in total 512 bits.
But since the UDS is 256 bits, we only use the eight LSBs in each MUX.

The eighth MSBs in each MUX will be initialized to zero. The read
access bit (se description above) for a given word is used as the
highest address bit to the MUXes. This forces any subsequent accesses
to a UDS word to read from the MUX MSBs, not the LSBs where the UDS is
stored.

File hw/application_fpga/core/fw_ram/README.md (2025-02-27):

# fw_ram
RAM for the firmware (FW).

## Introduction
This core implements the RAM exclusive to the FW. This allows the FW
to execute without having to use the application RAM. The core
supports mode based lock down to prevent any access in application
mode.

## API
The core does not have an API.

## Implementation Details
The core is implemented by explicitly instantiating one or more pairs
of SB_RAM40_4K RAM cores in the FPGA.

The contents of the fw_ram is cleared when the FPGA is powered up and
configured by the bitstream. The contents is not cleared by a system
reset.

If the app_mode input is set, i.e. in app mode, no memory
accesses are allowed. Any reads when the app_mode is set will
return an all zero word.

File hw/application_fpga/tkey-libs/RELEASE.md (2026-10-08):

# Release notes

## Upcoming release

- NOTE WELL! Rewritten I/O functions with new signatures and
  semantics!
- `blake2s()` with new signature.
- System call support.

### BLAKE2s hash function

The `blake2s()` function no longer call the firmware.

- The `blake2s.h` header file has moved to `blake2s/blake2s.h`.

- The `blake2s()` hash function has changed signature. It's now defined
  as:

  ```
  // All-in-one convenience function.
  int blake2s(void *out, size_t outlen,   // return buffer for digest
      const void *key, size_t keylen,     // optional secret key
      const void *in, size_t inlen);      // data to be hashed

  ```

- The component functions `blake2s_init()`, `blake2s_update()`, and
  `blake2s_final()` are now available.

### I/O

The Castor TKey hardware supports more USB endpoints:

- CDC - the same thing as older versions.
- FIDO security token, for FIDO-like apps.
- CCID, smart card interface.
- DEBUG, a HID debug port.

The communication is still over a single UART. To differ between the
endpoints we use an internal USB Mode Protocol between programs
running on the PicoRV32 and the CH552 USB Controller.

The I/O functions has changed accordingly. Please use:

- `readselect()` with appropriate bitmask (e.g. `IO_CDC|IO_FIDO`) to
  see if there's anything to read in the endpoints you are interested
  in. Data from endpoints not mentioned in the bitmask will be
  discarded. Castor only function.

- `read()` is now non-blocking and returns the number of bytes read
  from the endpoint you specify, because more might not be available
  yet.

- `write()` now takes an endpoint destination.

- We also introduce generic `putchar()`, `puts()`, `puthex()`,
  `putinthex()`, and `hexdump()` functions that take a destination
  argument.

All functions above, except `readselect()`, works with Bellatrix if
using `IO_UART`, or `IO_QEMU` for `puts()` etc.

### Serial convenience functions

To make it easier to write applications working on both Bellatrix and
Castor `serial_read()` and `serial_write()` is added. They use the
appropriate destination depending on version. The cost is a larger
binary size. This API only works with either `IO_CDC` or `IO_UART`
depending on version. They cannot safely be used if additional
endpoints are enabled via `config_endpoints()`.

### Frame handling

When using the defined framing protocol the helper functions
`frame_read()` and `frame_write()` can be used. They can be used with
both Bellatrix and Castor and will aid in the frame parsing.

### Debug prints

The optionally built debug prints have changed. You now use
`debug_puts()` et cetera instead of `qemu_*()`.

You define the debug output endpoint when you compile your program by
including `debug.h` and defining `QEMU_DEBUG` for the qemu debug port
or `TKEY_DEBUG` for output on the DEBUG HID endpoint. If you don't
define either, they won't appear in your code.

Similarly, `assert()` now also follows `QEMU_DEBUG` or `TKEY_DEBUG`,
and prints something on either before halting the CPU.

Note that on the Bellatrix platform only `QEMU_DEBUG` works.

## v0.1.2

From now on tkey-libs is licensed under the BSD-2-Clause license,
moving from the previous GPLv2-only.

Note: There is a possibility that this update may impact the generated
CDI for an app that relies on this library. It is recommended to
always check for potential CDI changes for each specific app with
every update. If the generated CDI does change, and if applicable, it
should be clearly communicated to end users to prevent unintentional
changes to their identity.

Changes:
- New license, BSD-2-Clause
- Reuse compliant, see https://reuse.software/
- Fix row alignment in qemu_hexdump
- Update memory map, tk1_mem.h, from canonical tillitis-key1 repo
- Added make target for creating compile_commands.json for clangd
- Added missing include in touch.h

Full changelog:
[v0.1.1...v0.1.2](https://github.com/tillitis/tkey-libs/compare/v0.1.1...v0.1.2)

## v0.1.1

This is a minor release correcting a mistake and syncing with the
latest HW release, TK1-24.03.

Note: There is a possibility that this update may impact the generated
CDI for an app that relies on this library. It is recommended to
always check for potential CDI changes for each specific app with
every update. If the generated CDI does change, and if applicable, it
should be clearly communicated to end users to prevent unintentional
changes to their identity.

Changes:
- Update memory map, tk1_mem.h, to match the latest TK1-24.03 release.
- Default to tkey-builder:4 for the podman target
- Default to have QEMU debug enabled in tkey-libs. Mistakenly removed
  in previous release.
- Revise readme accordingly

Full changelog:
[v0.1.0...v0.1.1](https://github.com/tillitis/tkey-libs/compare/v0.1.0...v0.1.1)

## v0.1.0

This release contains some changes that forces applications that use
tkey-libs to be updated to work with this release.

Note: It is highly likely that this update will affect the CDI of the
TKey. It is advised to always verify this for each specific app, for
every update. If the CDI changes, and it is applicable, it should be
stated clearly to end users to avoid unknowingly changing the TKey
identity.

Breaking changes:
- Check destination buffer's size for read(). To prevent writing
  outside of destination buffer.
- Renaming LED-functions to follow led_*().

Changes:
- New function, secure_wipe(), to clean memory of secret data.
- New function, touch_wait(). Waits for a touch by the user, with
  selectable timeout.
- New function, led_get(). Get the value of the applied LED color.
- Upgraded Monocypher to 4.0.2.
- Add variable AR in Makefile to enabling passing llvm-ar from command
  line.
- Update example app to use led.h.
- Don't have QEMU debug enabled by default.
- Minor tweaks and formatting.

Full changelog:
[v0.0.2...v0.1.0](https://github.com/tillitis/tkey-libs/compare/v0.0.2...v0.1.0)

## v0.0.2

This release contains some changes that forces applications that use
tkey-libs to be updated to work with this release.

Breaking changes:
- Introducing include hierarchy to make it less generic, e.g.,
  `#include <tkey/led.h>`.
- Use stdint.h/stddef.h infavor of types.h.
- Library .a files built on top level to simplify inclusion.
- Upgraded Monocypher to 4.0.1.
- QEMU debug behaviour changed, instead of defining `NODEBUG` to
  disable debug, one has to enable it by defining `QEMU_DEBUG`.

Changes:
- Introduce functions to control the LED, led.h and led.c.
- New function, assert() to make an illegal instruction and forcing
  the CPU to halt.
- Add functions memcpy_s(), wordcpy_s(), memeq() from firmware
- Adding `const` to MMIO variables and qemu_* functions.
- Minor tweaks, clean up and bugfixes.

Full changelog:
[v0.0.1...v0.0.2](https://github.com/tillitis/tkey-libs/compare/v0.0.1...v0.0.2)

## v0.0.1

Just ripped from

https://github.com/tillitis/tillitis-key1-apps

No semantic changes.

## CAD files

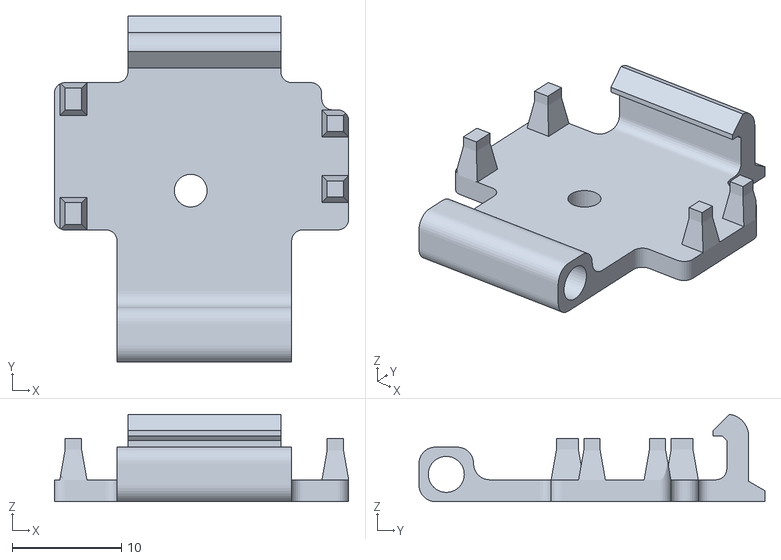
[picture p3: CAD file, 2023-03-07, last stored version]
hw/boards/mta1-usb-v1-programmer/clip_plastic/clip-tk1.stl
27.0 x 31.7 x 8.00

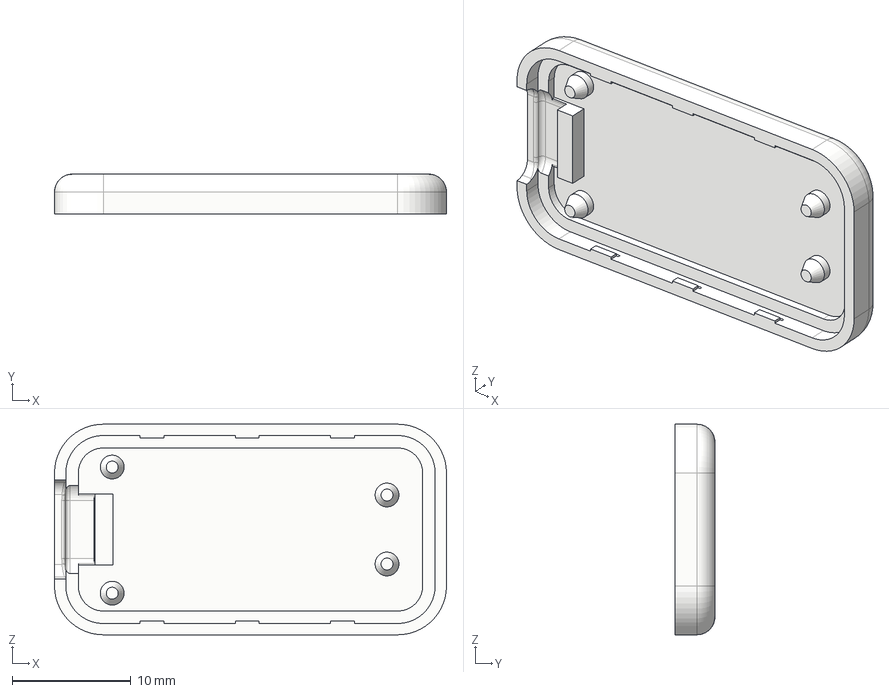
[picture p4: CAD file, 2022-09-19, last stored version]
hw/boards/mta1-usb-v1/case_plastic/2022-08-22 case production top.step
33.0 x 3.35 x 17.7 mm

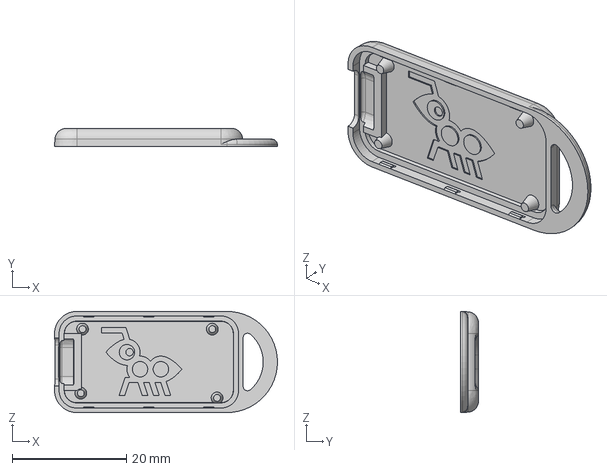
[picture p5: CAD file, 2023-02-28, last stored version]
hw/boards/tk1/case_plastic/3D_printed/case_top_revc.step
39.0 x 3.20 x 17.7 mm

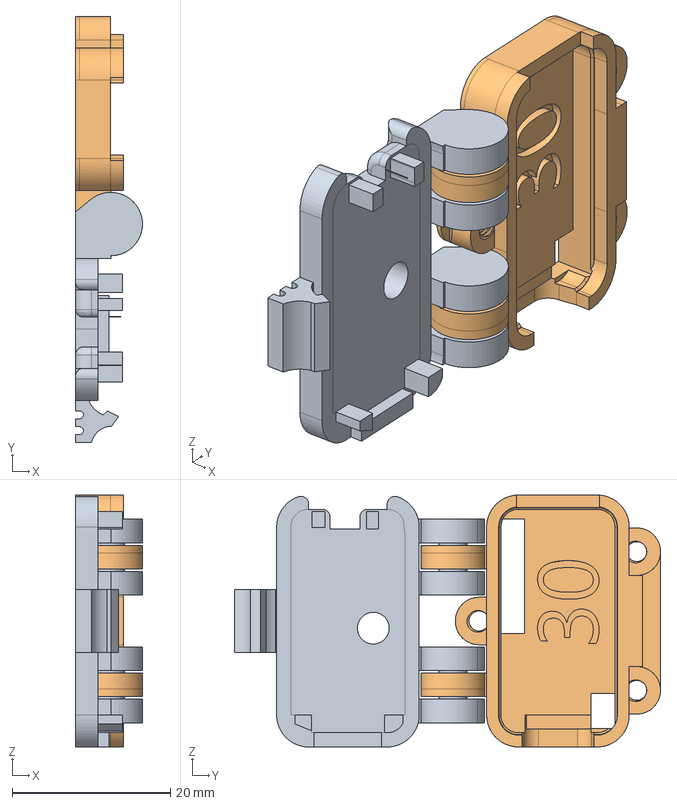
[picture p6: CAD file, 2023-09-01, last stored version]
hw/boards/tp1/clip_plastic/clip_base_30.stp
8.45 x 53.8 x 31.8 mm

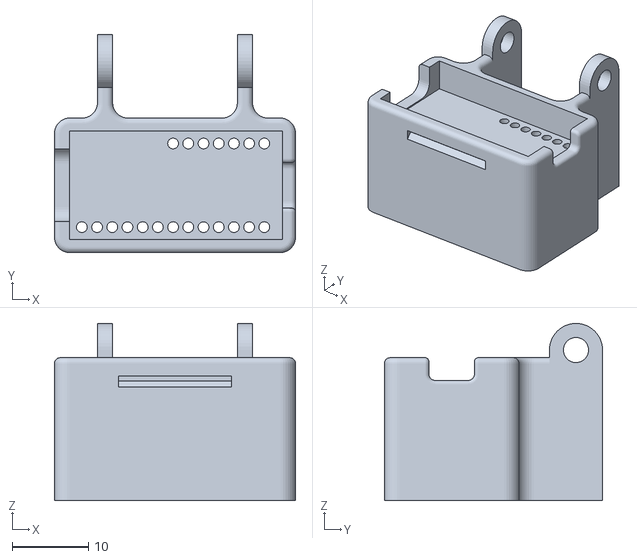
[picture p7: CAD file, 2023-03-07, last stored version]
hw/boards/mta1-usb-v1-programmer/clip_plastic/base-tk1.stl
31.7 x 28.7 x 23.3

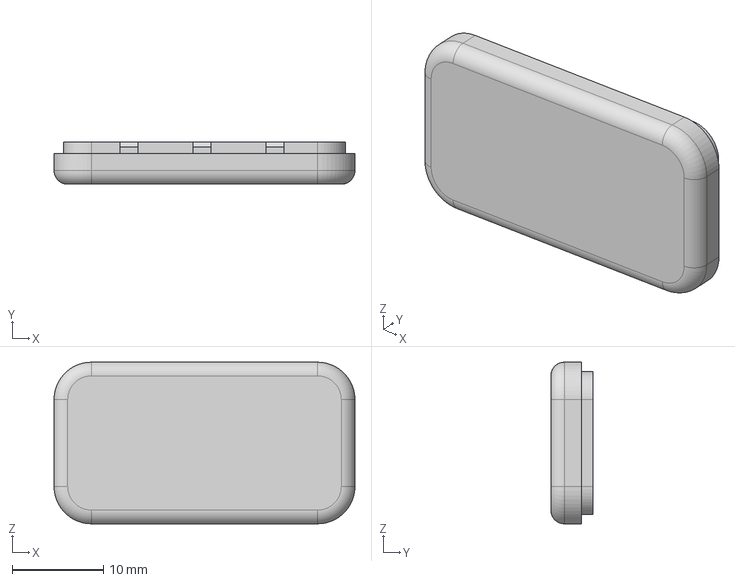
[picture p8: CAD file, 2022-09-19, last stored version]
hw/boards/mta1-usb-v1/case_plastic/2022-08-22 case production bottom.step
33.0 x 4.65 x 17.7 mm

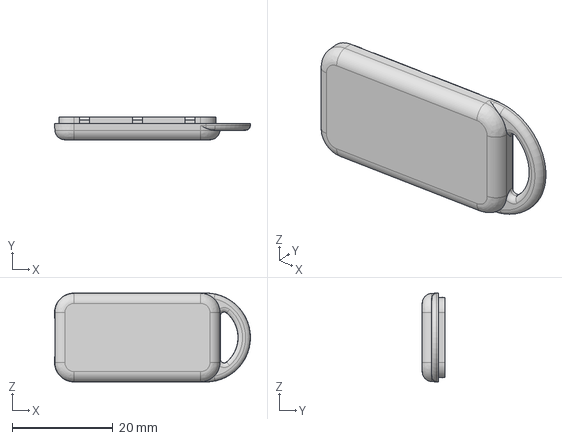
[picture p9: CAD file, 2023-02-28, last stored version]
hw/boards/tk1/case_plastic/3D_printed/case_bottom_revc.step
39.0 x 4.50 x 17.7 mm

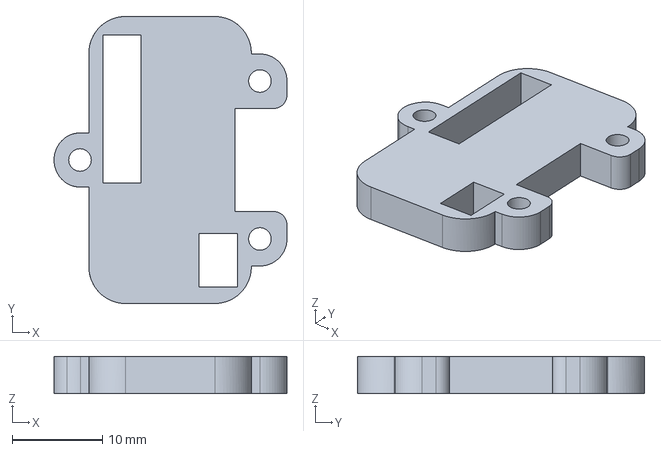
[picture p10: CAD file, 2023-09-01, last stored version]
hw/boards/tp1/clip_plastic/clip_base_spacer_30.stp
25.8 x 31.8 x 4.10 mm

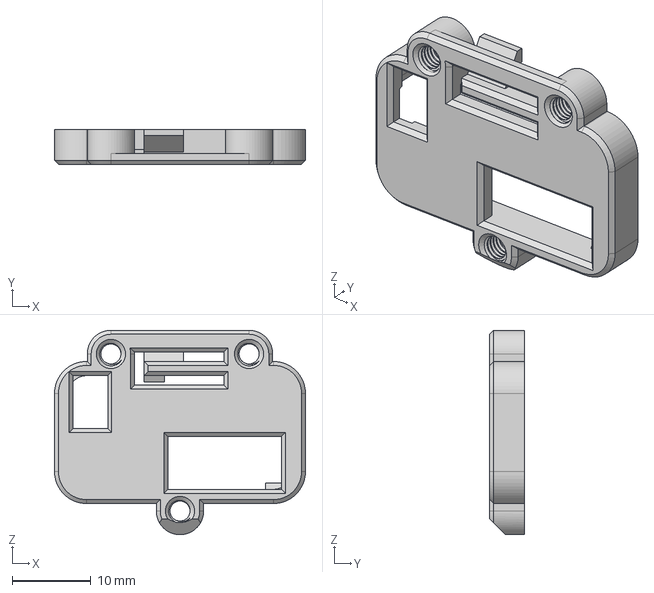
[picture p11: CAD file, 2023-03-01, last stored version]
hw/boards/tp1/clip_plastic/clip_base_15.step
31.8 x 4.40 x 25.9 mm

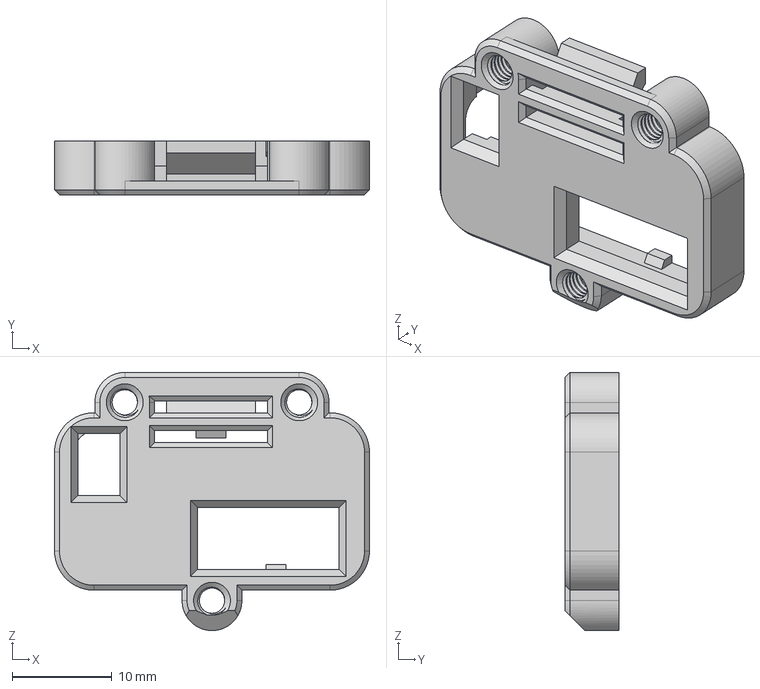
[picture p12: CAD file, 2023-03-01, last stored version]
hw/boards/tp1/clip_plastic/clip_base_24.step
31.6 x 5.40 x 25.9 mm

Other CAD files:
hw/boards/mta1-usb-v1-programmer/clip_plastic/clip.stl
hw/boards/mta1-usb-v1-programmer/clip_plastic/base-mta1.stl
hw/boards/mta1-usb-v1-programmer/clip_plastic/clip-mta1.stl
hw/boards/mta1-usb-v1-programmer/clip_plastic/base.stl
hw/boards/mta1-usb-v1/case_plastic/2022-08-22 case v3.f3z
hw/boards/tp1/clip_plastic/clip_base_15.f3d
hw/boards/tp1/clip_plastic/clip_base_24.f3d
hw/boards/tp1/clip_plastic/clip_base_30.3mf

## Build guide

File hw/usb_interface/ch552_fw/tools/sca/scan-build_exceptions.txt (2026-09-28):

# <issue_type_regex>:<filename_regex>:<function_regex>:<reason_string>
alpha.core.CastToStruct:src/main.c:UsbEp0SetupHandler:Ignore for now
alpha.core.Conversion:inc/debug.h:mInitSTDIO:Ignore for now
alpha.unix.cstring.OutOfBounds:src/main.c:CreateCfgDescriptor:False positive
deadcode.DeadStores:inc/debug.h:UART1Clean:By design

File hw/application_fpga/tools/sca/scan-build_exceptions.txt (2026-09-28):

# <issue_type_regex>:<filename_regex>:<function_regex>:<reason_string>
core.FixedAddressDereference:.*:.*:Ignore FixedAddressDereference
core.NullPointerArithm:fw/tk1/flash.c:flash_read_status:False positive

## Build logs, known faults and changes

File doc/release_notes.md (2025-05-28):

# Release Notes

Descriptions of the tagged TKey releases.

## Upcoming release: Castor

Overview of changes since [TK1-24.03
Bellatrix](https://github.com/tillitis/tillitis-key1/releases/tag/TK1-24.03)
for the Castor milestone so far.

Main branch in the repository contains Castor design and specifically
the tag `TK1-Castor-alpha-1` reflects the upcoming release.

**Note well**: BREAKING CHANGE! Older device apps WILL NOT WORK.

The introduction of the USB Mode Protocol between the programs running
on the PicoRV32 CPU and the CH552 means that device apps that have not
been changed to use the protocol will not have any way to communicate
with the outside world.

### How to test TK1-Castor-alpha

To test this alpha release you will need:

- Tkey Unlocked
- TKey Programmer Board
- CH55x Reset Controller from [Blinkinlabs](https://shop-nl.blinkinlabs.com/products/ch55x-reset-controller)

Read
[here](https://github.com/tillitis/tillitis-key1/blob/main/README.md#building--flashing)
for instructions.

### General

- Split repo:

  - tk1, mta1-usb-dev, mta-usb-v1 and mta1-library moves to
    <https://github.com/tillitis/tk1-pcba>

  - tp1, mta1-usb-programmer, mta1-library and KiCad-RP Pico moves to
    <https://github.com/tillitis/tp1>

For full change log [see](https://github.com/tillitis/tillitis-key1/compare/TK1-23.03.2...coming-tag)

### FPGA

- Make Security Monitor memory access checks more complete.

- Add SPI main controller mainly to access the flash chip.

- Add system reset API. Device apps can reset the FPGA and restart
  the firmware.

- Increase clock frequence to 24 MHz.

- Increase UART baudrate to 500,000.

- Fix UART baudrate counter issues noticable at higher baudrates.

- Fix missing clock cycles in timer core.

- Remove the UART runtime configuration API.

- Several minor clean ups of design and testbench.

- Add hardware clear to send (CTS) signals for communication between
  UART and CH552.

- Increase size of ROM and FW\_RAM.

- Make ROM non-executable in app mode.

- Remove MMIO address for access to the firmware blake2s() function
  from apps.

- Automatically leave firmware mode when execution leaves ROM and
  remove the now unnecessary APP\_MODE\_CTRL register.

- Change UDS read protection: When execution leaves ROM the first
  time, UDS is hardware protected from reads. The already existing
  protection that UDS is protected after the first read is also still
  available.

- Introduce interrupt handler for hardware-based privilege raising and
  automatically privelege lowering for system calls.

### Firmware

- At startup, fill RAM with random data using the xorwow PRNG, seeded
  by TRNG.

- Add support for the new USB Mode Protocol to communicate with
  different USB endpoints in the USB controller.

- Support a filesystem on flash: There's space for two pre-loaded
  apps and four storage areas for device apps.

  A typical use is that app slot 0 will contain a loader app for
  verified boot and app slot 1 contains the app to be verified.

- Automatically start an app in flash app slot 0 after power cycle and
  when instructed to by reset intentions.

  The automatically started app is trusted by the firmware by
  including an app digest in the firmware ROM. This means we extend
  the user's trust in the firmware to the first app, but only if it's
  measured to the correct digest by the firmware. Anything else is a
  hard error which halts the CPU.

- Support chaining of apps through soft resets, including support for
  verifying that the next app is the expected one (exact measured
  digest the previous app expected), and leaving data for the next app
  to use.

- Add a system call mechanism and system calls. See [firmware's
  README](../hw/application_fpga/fw/README.md) for documentation, but
  its probably easier to use the the syscall wrappers in libsyscall in
  [tkey-libs](https://github.com/tillitis/tkey-libs) if you're writing
  in C.

- Harmonize with [tkey-libs](https://github.com/tillitis/tkey-libs).
  Import tkey-libs to this repo for convenience.

- Rewrite test firmware to work with the new leaving ROM-scenario.
  Introduce a separate `testapp` for the app mode parts.

### Device apps

Introduce some device apps mostly for testing.

- `reset_test`: Test the different types of soft reset.

- `testapp`: Tests in app mode that used to live in `testfw`.

- `testloadapp`: A simple loader app for management and verification
  of a second app.

- `defaultapp`: An app that immediately resets the TKey to load an app
  from the client, just like earlier releases.

### CH552 firmware

- Use the new CTS signals for communication over the UART.

- Add support for two HID endpoints (security token and our debug
  HID).

- Add support for CCID endpoint.

- Add a protocol to communicate with the different endpoints: CDC,
  CCID, FIDO, debug.

- Change USB frame sending from a software timer to instead be
  controlled by the USB Controller Protocol.

Note that to update the CH552 firmware you will need something like
the Blinkinlabs CH55x Reset Controller:

<https://shop-nl.blinkinlabs.com/products/ch55x-reset-controller>

<https://github.com/Blinkinlabs/ch55x_programmer>

### Tooling

- Add tools to parse and generate partition tables and flash images.

- Add tool to compute a print a BLAKE2s digest, optionally as C code.

### tkey-builder

- New versions of:
  - clang (18.1.3, part of ubuntu 24.04)
  - icestorm (commit 738af822905fdcf0466e9dd784b9ae4b0b34987f
)
  - yosys (0.45)
  - nextpnr (0.7) + extra patches for RNG seed handling and early exit
  - iverilog (v12)
  - verilator (v5.028)
  - verible (v0.0-3795)
  - cocotb (v1.9.1)

- Remove TKey Programmer (TP) toolchain:

  - gcc-arm-none-eabi: Used for the TKey Programmer firmware, now
    moved to it's own repo.
  - libnewlib-arm-none-eabi
  - libstdc++-arm-none-eabi-newlib
  - pico-sdk

  TP1 is now in <https://github.com/tillitis/tp1>

- Remove Go compiler support.

- Introduce buildtools.sh for building upstream tools for inclusion
  in the image.

### Docs

- All docs now in READMEs close to the design or code.

- Protocol docs moved to [the Developer
  Handbook](https://dev.tillitis.se/)
  [repo](https://github.com/tillitis/dev-tillitis)

## TK1-24.03

This is an official release of the "Bellatrix" version of the Tillitis'
TKey. This version is ready for general use.

Using OCI image `ghcr.io/tillitis/tkey-builder:4`, built from
`../contrib/Dockerfile`, and the generic
`../hw/application_fpga/data/uds.hex` and
`../hw/application_fpga/data/udi.hex`, a clean build should generate
the following digest:

```
321924aa3b26507f2a02325750e63c83b306c7831f8e2c87e8d198cecf8cc1c1  application_fpga.bin
```

### FPGA

- Security Monitor now prevents access to RAM outside of the physical
  memory. If it detects an access outside of the RAM address space, it
  will halt the CPU.
- CPU Monitor changes name to Security monitor, which CPU Monitor is a
  part of. Prepare for more functions in the future.
- Support incremental builds for the bitstream, when changing UDS/UDI
  between builds. Requires tkey-builder:3 or higher.
- Update Verilog linter to Verilog-2005 and fixed warnings.
- Complete testbenches and add 9 tests for the FPGA cores.

### Firmware

- Protect zeroisation against compiler optimisation by using
  secure_wipe(), fixing a memset() that was removed during
  compilation.
- Make memeq() function side channel silent.
- Change memory constants to defines instead of an enum, to be
  compatible with ISO C.
- Deprecate TK1_MMIO_TK1_RAM_ASLR and introduce
  TK1_MMIO_TK1_RAM_ADDR_RAND instead to distinguish from OS-level
  ASLR.
- Use pedantic warnings while building firmware and fixed warnings.
- Use clang-tidy in CI.
- Fix warnings from splint.

### TP1

- New plastic clip o and update of BOM.
- Build TP1 firmware in CI.

### CH552

- Fixed a bug where a byte of data could in some rare circumstances be
  dropped, causing a client app to hang.
- General clean-up of code, translated all comments to English.

### TK1

- New injection moulded plastic case

### tkey-builder

- Updated to version 3. Bumping Ubuntu to 23.10, Yosys to 0.36 and
  nextpnr to 0.6.
- Updated to version 4. Bumping pico-sdk to 1.5.1, adding clang-tidy
  and splint.

### Docs

- Fixing broken links, cleaning up docs and READMEs.
- Clarify warm boot attack mitigations and scope for Bellatrix in
  threat model.

For full change log [see](https://github.com/tillitis/tillitis-key1/compare/TK1-23.03.2...TK1-24.03)

## TK1-23.03.2

This is the official release of the "Bellatrix" version of the
Tillitis TKey device. This version is ready for general use.

This release only contains a hardware update to tk1. Capacitor C8 is
not populated. A PCB spring contact, U11, is insted placed on the
footprint of C8.

## TK1-23.03.1

This is the official release of the "Bellatrix" version of
the Tillitis TKey device. This version is ready for general
use.

Given the OCI image `ghcr.io/tillitis/tkey-builder:2` built from
`../contrib/Dockerfile` and the generic UDS.hex and UDI.hex, a clean
build should generate the following digest:

```
sha256sum application_fpga.bin
d2970828269b3ba7f09fb73b8592b08814dfe8c8087b00b0659feb516bb00f33  application_fpga.bin
```

This bug fix release contains the following changes:

- Change the firmware protocol max frame size back to 128 bytes
- Correct a bug with the reading out of UDS

## TK1-23.03

This is the official release of the "Bellatrix" version of
the Tillitis TKey device. This version is ready for general
use.

Given the OCI image `ghcr.io/tillitis/tkey-builder:1` built from
`contrib/Dockerfile` and the generic UDS.hex and UDI.hex, a clean
build should generate the following digest:

```
shasum -a256 application_fpga.bin
f11d6b0f57c5405598206dcfea284008413391a2c51f124a2e2ae8600cb78f0b  application_fpga.bin
```

### New and improved functionality

- (ALL) The TKey HW design, FW, protocol and first applications has
  been audited by a third party. No major issues was found, but the
  audit has lead to several updates, changes and fixes to improve
  the security and robustness. The third party report will be
  published when completed.

- (APPS) Applications can now use the whole 128 kByte RAM.

- (FW) The firmware now use the `FW_RAM` for the stack. It keeps no
  .bss or .data segments and only uses RAM for loading the
  application.

- (FW) The firmware has been hardened and the state machine simplified
  to reduce the number of commands that can be used and in which
  order. It exits early on failure to a fail state indicated by the
  RGB LED blinking red on error in an eternal loop.

- (FW) Steady white LED while waiting for initial commands. LED off
  while loading app.

- (HW) The memory system now has an execution monitor. The monitor
  detects attempts at reading instructions from the firmware ram.
  The execution monitor can also, when enabled by an application,
  detect attempts at reading instructions from the application
  stack. If any such attempt is detected, the memory system will
  force the CPU to read an illegal instruction, triggering the
  trap state in the CPU.

  Note that the execution monitor can only be enabled, not
  disabled. The address range registers defining the region
  protected by the monitor can only be set when the monitor
  has not yet been enabled.

- (HW) The CPU trap signal is now connected to an illegal instruction
  trap indicator. When an illegal instruction is detected, the RGB LED
  will start flashing red. Note that the CPU will stay in the trap
  state until the TKey device is disconnected.

- (HW) The RAM memory now includes an address randomisation and data
  scrambling mechanism to make it harder for someone outside of the
  CPU to find assets generated by and stored in the RAM by
  applications. This randomisation and scrambling is set up by
  firmware before the application is loaded, and does not affect how
  applications executes.

- (HW) The UART Rx FIFO now allows applications to read out the
  number of bytes received and not yet consumed by the application.

- (HW) The FPGA bitstream can now be stored in the non volatile
  configuration memory (NVCM). This is done using of a new icestorm
  tool developed partly in the project and sponsored by Tillitis
  and Mullvad. The tool supports locking down NVCM access after
  writing the FPGA bitstream to the memory.

- (TOOLS) There is now an OCI image
  (`ghcr.io/tillitis/tkey-builder:1`) and Dockerfile setting up all
  tools as needed to build the bitstream.

- (TOOLS) There is now a version of iceprog able to write to the FPGA
  bitstream to the NVCM and lock the NVCM from external access

### Bugs fixed

- No known bugs have been fixed. Numerous issues has been closed.

### Limitations

- The RAM address and data scrambling in this release is not
  cryptographically secure. It his however randomized every time
  a TKey device is powered up.

## engineering-release-2

### New and improved functionality

- (HW) The rosc TRNG has now been completed and tested. The TRNG
  can now be used to generate seeds by applicaitons.

- (HW) The main clock frequency has been increased to 18 MHz.

- (HW) The FW now has a separate RAM used during loading and
  measurement of applications.

- (HW) The UART Rx FIFO is now able to handle 512 bytes.

- (HW) The UART default bitrate has been increased to 62500 bps.

- (HW) Support for division instruction (div) was removed from
  PicoRV32. Please compile your programs with the Zmmul extension,
  `-march=rv32iczmmul` for `clang`.

- (HW) The UDI is locked down and can only be accessed by firmware, to
  prevent applications from tracking a particular TKey.

- (HW) The timer MMIO API now takes separate start and stop bits for
  triggering the respective action, mitigating a time-of-check to
  time-of-use (TOCTOU) issue.

- (FW) The firmware has been restructured to be a Finite State
  Machine (FSM) with defined states for booting, loading
  applications, measure applications, calculate the CDI and
  start the loaded application.

  This change also changes the firmware protocol which now accepts a
  request to load a binary with an optional USS and automatically
  returns its digest and start the program when the last data chunk is
  received.

- (FW) A BLAKE2s hash function present in firmware is now exposed for use
  by TKey apps (through a function pointer located in MMIO `BLAKE2S`).
  See [software.md](system_description/software.md) for more
  information.

- (FW) To make warm boot attacks harder, the firmware sleeps for a
  random number of cycles before reading out the sensitive UDS into
  FW RAM.

## engineering-release-1

### Hardware

#### Limitations

- The entropy generated by the TRNG has not yet been thoroughly tested,
  and the generator has not been adjusted to generate good, unbiased
  randomness. Any application that wants to use the entropy source
  SHOULD NOT use the output directly, but only as seed to a Digital
  Random Bit Generator (DRBG), such as Hash_DRBG.

- The UART is currently running at 38400 bps. Future releases will
  increase the bitrate when communication at higher bitrates has
  been verified as stable and error free.

- The internal clock frequency is currently limited to 12 MHz.
  Future releases will increase the clock frequency to provide
  improved performance.

- The functionality in the firmware is currently not exposed to the
  applications via a stable name space, API. Future releases will
  provide access to FW functions such as the BLAKE2s hash function.

- The timer currently does not include a timeout interrupt. Applications
  using the timer must check the status in order to detect a timeout event.

- The timer currently does not provide a set of typical settings.
  Applications using the timer must set timer and prescaler as
  needed to get the desired time given the current clock speed.

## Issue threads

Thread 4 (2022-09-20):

[tillitis-key1/hw/boards/mta1-usb-v1/] USB-C connector might not be very durable?

GvY85, 2022-09-20:
Hi,

First of all, thanks for the great work.

If I may, I would like to critique the USB-C connector choice a bit. It seems you are limited (but then you did your own housing design) in PCBA space but it feels like the SMT USB-C connector uses is not very durable and would come off the board pretty quickly after some insertion cycles.
Any chance of changing it to a part that offers some THT mechanical support? This can even be a pin-in-paste type so that you do not need an additional THT solder step but can reflow the THT connector part.

Also, I noticed a few instances in the layout where the min gap is around 100um that could easily be extented to 125um minimum track-gap to improvbe manufacturability a bit.

cibomahto, 2022-09-20:
Thanks- do you have any recommendations for a connector?

The plastic housing is designed to capture the USB connector, so that the majority of the insertion/removal forces are absorbed by the case/connector interface, instead of the connector/pcb interface.

GvY85, 2022-09-20:
Hi,

Thanks for the quick reply.
I understand the reasoning behind it but in my experience in the long term that is not always the most robust solution.

Some connectors can be found here, most are reasonably priced (<€1,-) and feature 4 THT solder tabs that, with creative solder paste design, can be soldered in a SMT reflow process

[Digikey](https://www.digikey.nl/en/products/filter/usb-dvi-hdmi-connectors/usb-dvi-hdmi-connectors/312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)

GvY85, 2022-09-20:
Hmm, I see I linked in receptacles and not plugs.

Plug doe not seem to have such robust options it seem....:

[Digikey](https://www.digikey.nl/en/products/filter/usb-dvi-hdmi-connectors/usb-dvi-hdmi-connectors/312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)

Closed 2022-11-21.

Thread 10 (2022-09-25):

Flash the key from the container (a rootless podman container)

faern, 2022-09-25:
I have been trying to figure out how to flash the device from within the [build container](https://github.com/tillitis/tillitis-key1/blob/main/contrib/Dockerfile) without needing root. This issue serves both as documentation for others coming here, and a request to update the documentation around it :)

1. Add udev rules to allow the `dialout` group to access the programmer board. Your user must then of course be in the `dialout` group:
    ```
    $ cat /etc/udev/rules.d/55-tillitis.rules
    SUBSYSTEM=="usb", ATTR{idVendor}=="cafe", ATTR{idProduct}=="4004", MODE="0666", GROUP="dialout"
    KERNEL=="hidraw*", ATTRS{idVendor}=="cafe", ATTRS{idProduct}=="4004", MODE="0666", GROUP="dialout"

    $ sudo udevadm control --reload-rules && sudo udevadm trigger
    ```
    Make sure to unplug and plug your device again after this.

    *If you have SELinux on your system (for example Fedora)*, you will also need to allow containers to access forwarded hardware devices. Run the following:
    ```
    setsebool container_use_devices=true
    ```

1. Build the container:
    ```
    podman build -t tillitis-dev contrib/
    ```

1. Open `hw/application_fpga/Makefile` and remove all usages of `sudo` (It's not installed in the container, and not needed)

1. Build the firmware and flash the device, all from within the container:
    ```
    podman run --rm \
        --device /dev/bus/usb/$(lsusb | grep -m 1 cafe:4004 | awk '{ printf "%s/%s", $2, substr($4,1,3) }') \
        -v .:/build:Z -w /build/hw/application_fpga \
        -it tillitis-dev make prog_flash
    ```

faern, 2022-09-26:
I got some very helpful tips in https://github.com/containers/podman/issues/15930 that allowed me to flash without disabling SELinux :partying_face:

mchack-work, 2023-09-11:
Thanks for the input. Now documented in Dev Handbook at https://dev.tillitis.se/ - only a year later!

Closed 2023-09-11.

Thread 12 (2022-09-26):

picorv32 built without DIVision, but extension "m" includes div/rem (rv32imc)

quite, 2022-09-26:
@bjoto wrote:

> The picorv32 on the key is built with ENABLE_DIV=0, and we're compiling the source (fw/app) with the "m extension" enabled. The m-ext includes div/rem so we're just lucky that we're not getting those in the app/fw. Two options:
> - Enable division in the picorv32 (more LUTs)
> - Use the Zmmul extension instead of m (recent clangs has support): "RISC-V Zmmul Multiply Only enables low-cost implementations that require multiplication operations but not division, and is part of the RISC-V Unprivileged Specification."

Thank you. We currently use clang 14 and it does not have `Zmmul`, checked with `llc -march=riscv32 -mcpu=help |& grep -i zmmul`. For catching this early and right now we could do `llvm-objdump | grep (div|rem)` or "look into the exception handling of illegal instruction in picorv32... maybe it's possible to trap and blink the leds aggresively!"

quite, 2022-09-26:
@secworks  I tried building with `ENABLE_DIV=1`, result is this increased device utilisation, from:

 ```
 Info:            ICESTORM_LC:  4446/ 5280    84%
```
to
```
 Info:            ICESTORM_LC:  5189/ 5280    98%
 ```

Maybe this is not great at all, considering that the space might be needed for other things, like a blake2 in hw? Or what else we've had on the table.

quite, 2022-09-26:
Maybe we can just avoid DIV/REM being used? If so, then eating up more space in the FPGA seems like really bad idea. In this case, would it be fine to check for DIV/REM in the final ELF, and fail if they are present. And once we get onto clang 16 (or what is needed), we can get onto Zmmul extension.

quite, 2022-09-27:
Ah yes, we should try to use a DIV and see what happens, crash or not?

secworks, 2022-09-27:
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

Interesting, I don't see the change in utilization when I enable DIV.

To answer the the use of resources - if apps crash when using a div instruction that would make this a high priority, and thus a good use of resources. As long as we get good clock frequency with 98% fill rate I would be happy. I don't see any things more important to add right now.

Blake2s in HW will require more resources that we have as it is before enabling DIV.

secworks, 2022-09-28:
Fixed in commit https://github.com/tillitis/tillitis-key1/commit/f09ff87f9e5d5ed9940f1550ae7fae4b6486aabf

Closed 2022-09-28.

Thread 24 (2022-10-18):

I/O problems

quite, 2022-10-18:
I furnished a script to run signing in a loop. After some 1000-2000 iterations, the signing hangs. This on 38400 bps.

I seemed to have hung on `getSig` in the signerapp. So a byte was lost, and the ReadFull() hung because it never got the whole frame, the whole size that it expected? Possibly

When trying this at 500_000 bps, it would hang after some 10s of signing iterations.

quite, 2022-10-18:
One small observation: when signing has hung, device is back flashing blue. So i should be able to sign again, right? i try, but it doesn't work -- the first getPubkey cmd doesn't have the expected number of bytes in the response.

I also tried -- upon connecting to the device -- to first read any "left over" bytes, and then proceed to sign (like, was there something laying around there?). didn't work.

So, is there then something wonky with the state of the device's fifo.

secworks, 2022-10-18:
There is no TX FIFO, so unless FW itself has a buffer that it is trying to send there wouldn't be any data left to send. Since device is flashing blue I assume that it is not ready to send stuff, but to receive stuff (commands).
But you do get a response when asking for a pubkey? And are the number of missing bytes the same?

There could be something wonky with the  RX FIFO. But we need to isolate when hanging occurs. Is it always at the same situation? One thing we could try is look at if the FIFO get full. We currently have no detection of this, but could be added.

quite, 2022-10-19:
Yesterday I set up uart.v for 40000 bps, which is a nice and even divisor of 450. I started the test-loop and it ran overnight successfully (I stopped it now after more than 16h). 105000 iterations! So we might have both the fractional divisor issue (with 38400), and some other speeding issue?

quite, 2022-10-20:
Ran 62500 overnight -- a supposedly good bps for both fpga-uart and ch552. After 47000 iterations (almost 7 hours) the signing loop had stopped, because a signature from the device could not be verified.

The next "good" number is 100_000 bps, but that hangs very soon.

secworks, 2022-11-21:
I think we have concluded that 62500 is what works. It is the default bitrate since several weeks.
I suggest that we close this issue.

Closed 2022-11-21.

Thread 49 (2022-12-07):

Lock down access to UDI to only FW

secworks, 2022-12-07:
Only the FW should have access to the UDI.
We should add a check of the switch_app_reg when handling UDI read operations.

quite, 2022-12-07:
Oh, is having app access it some security issue?  In tkey-ssh-agent it is useful to display as the ssh key comment in `ssh-add -L`, so use can identify which TKey is plugged in that way.

quite, 2022-12-07:
Firmware protocol should still allow fetching of UDI, right?

secworks, 2022-12-08:
Yes, FW will have access to UDI. It is useful to display UDI to the user when the device has been connected. It is also useful for Tillitis to be able to extract UDI to identify devices during production, handling of warranty, repair issues.

secworks, 2022-12-08:
The security issue with apps having access to the UDI allows apps to use the UDI for all kinds of identification towards services etc. This may lead to hard connection between a user and a device, possibly leakage of who the user really is in a way the user have little, no knowledge nor control of.

This way identification towards a service has to be solved either by deriving an identity based on CDI, or explicitly asking the user for an ID. Which of course could be scripted (having a cookie on the host, for example). But we should at least not provide device specific info to the apps to support this.

quite, 2022-12-08:
Yup, I understand the reasoning.

My notes about the consequences of this change (@mchack-work for information):

This would mean that tkey-ssh-agent only will be able to get hold of the UDI the TKey if is started when TKey is in firmware mode (and it loads the signerapp itself). If signerapp is already loaded when tkey-ssh-agent starts, it would be able to use the agent, but not get hold of UDI for showing through the comment field displayed by `ssh-add -L`.

When tkey-ssh-agent loads the app itself, the UDI is also displayed in the USS input dialog for the user.

Either tkey-ssh-agent won't (or alternatively should not ever) display the UDI in `ssh-add -L` if it doesn't load the signerapp itself. Or maybe it should refuse to operate if it does not find TKey in firmware mode when starting up. Not sure.

secworks, 2022-12-08:
Created a feature branch with a commit that locks down the UDI access:
https://github.com/tillitis/tillitis-key1/compare/main...udi_fw_access_only

quite, 2022-12-08:
Looks good @secworks , will be expecting adjustments to software.md and system_description.md in the same PR ;)

secworks, 2022-12-08:
Good! Yes, those should be updated too. And we need to test the access control too.
I just wanted to add the isse and a commit with the HW changes to have something to discuss.

mchack-work, 2022-12-19:
PLease see PR https://github.com/tillitis/tillitis-key1/pull/60

quite, 2023-01-26:
This was impl in the tk1 core in 5c74a0727c19b4f0f21d75a9eef8e7f231d48a43

Closed 2023-01-26.

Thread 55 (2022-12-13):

CI

mchack-work, 2022-12-13:
CI for main repo: Probably at least do a complete build and run linters.

Maybe start things under Verilator.

secworks, 2022-12-15:
I'll start looking into this. Possibly asking OlofK for help.

mchack-work, 2022-12-15:
I pushed a container image built from `contrib/Dockerfile` to ghcr.io/tillitis/tkey-builder so it can be used by Github Actions. Not sure if we can keep it there since it's 2.3 GiB.

quite, 2023-02-03:
I've added basic CI. On push to main and on PR it does:
- build all
- check fw C code fmt

- [ ] I also added spdx-ensure script like I did in the apps repo. But it is not enabled, as we have many files in hw/boards/ and hw/production_test/ that either need the SPDX tag, or should be marked in the script as not needing the tag.
- [ ] should also do `make verilator`, but it is currently broken @secworks

Also @secworks I see we have a `make lint` target that uses verilator for linting, but there are quite some lint_issues.txt that should be fixed before we can run it automatically (perhaps some are related to verilator build currently breaking)

secworks, 2023-02-06:
Regarding the warnings in lint_issues. All but one relates to issues in the ice40 cell library, and ports not assigned by Yosys when instantiating the cells. This is external to our design. The final warning relates to PicoRV32 using both blocking and non-blocking assignments for the same signal. This is bad coding, but will break the CPU functionality. Since we instantiate the PicoRV32 as a component, I've decided to ignore it too.

secworks, 2023-02-06:
The "make verilator" target will be fixed. Not sure if we should run it as part of CI though.

secworks, 2023-02-06:
So "make" to build the whole FPGA including FW,  and "make lint" should be in CI. IMHO.

quite, 2023-02-07:
No we chose to not actually run verilator for now. And leave the spdx-ensure out for now.

Closed 2023-02-07.

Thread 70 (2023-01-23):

Change timer API to have explicit start and stop bits to fix TOCTOU.

secworks, 2023-01-23:
The current API for the timer contain a combined start/stop-bit. Based on the current state (idle or running), writing to the bit will either start or stop the timer. The problem is that when reading the status and then writing to this bit, the status may have changed (the timer finished). A nice example of a TOCTOU issue.

secworks, 2023-01-23:
Commit https://github.com/tillitis/tillitis-key1/commit/b84a5aa18a3ef1d4f116a955247d9e99f3284551 changes the API to have separate 'start' and 'stop' bits.  The start bit is will only work when timer is not running. Similarly, the stop bit will only work when the timer is running.

Additionally, this commit change the name of the 'ready' bit to 'running' to make it more clear. This change also inverse the values. The bit is zero when the timer is not running, and one when the timer is running.

The commit updates the documentation and header file. The commit also updates the core testbench.

quite, 2023-01-23:
@secworks Just to confirm; you mentioned that for the watchdog, writing to the start-bit when the timer is already running would cause it to restart (with same timer value & prescaler). That was only for the watchdog, and not for our general timer then?

secworks, 2023-01-23:
Yes. That is only for the watchdog. Unless you think otherwise. I'm open to suggestions on the API, alining behaviours between cores have benefits (I think - like having control and status on the same intra-addresses.). Would it make sense to have the timer behave like this? When would it make sense? (Use case?)

quite, 2023-01-30:
@secworks i've updated fw & testfw to the new API and pushed a commit. Also small change to software.md in another commit.

secworks, 2023-01-30:
I have reviewed the changes and think this can be merged.

Closed 2023-01-30.

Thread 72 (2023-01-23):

Add watchdog core

secworks, 2023-01-23:
We want to be able to handle TKey FW and apps stuck. We do this by adding a watchdog core.

The core when activated will count cycles from a preset value down to zero. When it reaches zero it will trigger the reset process in the FPGA design. Note that this will NOT force the FPGA device to perform configuration by reading the configuration bitstream, just reset the FPGA design already configured.

FW and SW can avoid the reset by periodically write the 'start'-bit in the watchdog core API. FW and SW can also disable the watchdog by writing to the 'stop'-bit when the watchdog counter is running.

secworks, 2023-01-23:
The https://github.com/tillitis/tillitis-key1/tree/watchdog branch contains a (hopefully) working implementation. It needs review and testing.

mchack-work, 2023-01-26:
When attempting to add support for the hardware watchdog in qemu I noticed that exposing `TK1_MMIO_WATCHDOG_CURR_TIMER` means we have to update it 18 million times per second. This slows down qemu quite a lot.

I propose we don't expose `CURR_TIMER` to software at all.

mchack-work, 2023-01-26:
qemu support in branch watchdog in https://github.com/tillitis/qemu

Still WIP. Timers and MMIO work and the watchdog() callback function is hit but we still can't reset the machine properly.

secworks, 2023-01-27:
Commit https://github.com/tillitis/tillitis-key1/commit/01fab59132375fc7e8c828b0afca35c9160b8e9f remove the CURR_TIMER from the API.

secworks, 2023-02-08:
An important question is if the watchdog improves the ability to perform warm-boot attacks. By crafting an app that simply enables the watchdog after n cycles it allows an attacker to control when a device is being reset, and get the FPGA to configure itself without disconnecting it (and reconnecting it again) to the host.

secworks, 2023-05-03:
Will not be integrated in the TKey1 device.

Closed 2023-05-03.

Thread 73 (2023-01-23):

Checking if TKey is running an App

0xMihir, 2023-01-23:
Currently, if you try to send app commands when the TKey is in firmware mode, the TKey locks up and cannot load apps.

It would be nice if there were a way to check that the TKey is currently running an app so you do not need to re-flash software each time.

quite, 2023-01-24:
It would be interesting to know exactly what you send to the firmware which "bricks" it, making app-loading impossible. But I think I can see ways of this happening.

Our usual procedure in the host programs is that they either assume the TKey-app they want to talk to is running, and talk away. This is the simple case.

The `tkey-ssh-agent` tries to probe for firmware by doing GetNameVersion with a read timeout. If it gets a response, then firmware is running and it proceeds to load its signer-app. If it times out, then some app is assumed to be running, so it does GetNameVersion towards the app (which signer-app implements) and if it the signer-app is indeed running, then go ahead and talk to it. If it times out, some other TKey-app is probably running and the TKey currently needs to be removed and plugged in again to put it back in firmware mode.

We're considering to add watchdog which can be used to allow firmware and app to reset itself to a known state if it doesn't receive enough bytes for a cmd etc. https://github.com/tillitis/tillitis-key1/issues/72

quite, 2023-01-24:
Oh, and to specifically answer your question. No you cannot in the general case find out if an app is running, because the app can implement any protocol of choice. So you can try to talk to firmware with timeout, and this *should* fail if an app is running. But it would also fail if you're talking to the wrong serial port/tty. And the app could as well implement the firmware protocol, impersonating the firmware.

Protocol guidelines could be introduced, where TKey app developers agree to implement a certain command in the same way, or to ignore a certain firmware command.

mchack-work, 2023-03-23:
In https://github.com/tillitis/tillitis-key1-apps we decided to probe for firmware and have running apps checking framing protocol header for incoming commands to `DST_FW` and replying `NOK`. Not great, but at least a workaround for now.

Closing.

Closed 2023-03-23.

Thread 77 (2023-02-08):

Add EXE monitor

secworks, 2023-02-08:
Currently all context of a TKey application is stored in the same memory - code (text section), heap and stack. A malicious (or inventive - dynamic programming is fun.) App (or a successful injection attack) would be able to change the code loaded. It would also be possible to have the CPU execute data stored on the stack as instructions.

We would like to improve this by being able to prevent the CPU from writing to the code in App mode. We would also like to prevent execution from the stack. This is similar in concept to The W^X in OpenBSD (and other OSes) - that is exclusively allow either writes or execution to specific memory areas.

This issue deals with how we can accomplish this. And what the proper response should be when an incorrect behavior is encountered.

secworks, 2023-02-08:
If we could expose the instruction pointer (PC) inside the CPU core we can observe where the CPU is trying to to read instructions. We can also already observe write operations (the CS and WE flags in combination with the address).

A monitor core that exposes registers for FW (and possibly Apps themselves) to set boundary limits for execution er write operations could then simply compare the PC or the write address against the boundaries. This monitor would be very cheap in hardware to implement. And if it is not used it would also not change the behavior of the TKey compared to today.

The big question is what the proper response to an access violation should be? Reset the whole FPGA? Would that make it easier to perform warm-boot attacks? Another possible response is to force the CPU to load an instruction that hangs the CPU. Possibly then also trigger flashing of the LED.

secworks, 2023-02-20:
The branch https://github.com/tillitis/tillitis-key1/tree/exe_monitor contains a first implementation of an execution monitor. The monitor allows SW (FW or APP) to define a region that the CPU should not fetch instructions from. SW can also set an instruction that should be returned if instructions are being fetched from that area. The monitor can be enabled by SW. (This allows SW to set up the area and proper response before the monitor starting doing its job.)

The monitor allocates 272 LCs and the design meet timing.

The monitor does not observe write operations to areas writes should not be allowed. This can be added. However the forced execution becomes trickier. Therefore we wait with this function.

Another limitation is that the monitor only works with ROM. It should of course work with the complete memory system.

secworks, 2023-02-20:
The force jump-functionality has now been moved from ROM to top level memory system. This allows us to perform the force jump for all the whole memory space. This means that we can protect from cpu instruction access in  MMIO cores. in RAM, ROM and FW_RAM.

secworks, 2023-02-28:
Changed the design. Now the exe monitor will cause a trap instruction to be read by the CPU, which will cause it to hang. This simplifies the exe monitor a bit (removing the API register for the instruction). It also clearly defines what happens when the exe monitor triggers.

This simplification reduce the allocated LCs to 205, which is 136 less. Surprisingly many.

secworks, 2023-03-02:
The exe monitor should not be possible to disable after being enabled in app mode.
The first and last addresses should not be possible to change when enabled.

secworks, 2023-03-06:
The exe-monitor should really look at prefix bits and then just part of the address. Currently we use the complete 32-bit address.

secworks, 2023-03-06:
There is not a change pushed that adds the fw_ram to be observed by the monitor at all times. And apps can only enable, not disable the monitor.

secworks, 2023-03-07:
The exe monitor has been merged into main.

Closed 2023-03-07.

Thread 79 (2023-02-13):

Programming board: implement faster USB protocol

cibomahto, 2023-02-13:
I'd like to upgrade the USB protocol that the programmer boards speak, in order to have drastically better flash performance. Unfortunately the protocol change is incompatible with the firmware that we currently ship on the programmer boards, so they will need to be updated for this to work.

To upgrade, at the moment you need to:

1. Update the firmware in your programmer to the 'raw_usb' version: https://github.com/blinkinlabs/ice40_flasher/tree/raw_usb (this is already done on the production test jig pico)
2. Update iceprog to the 'raw_usb' version: https://github.com/tillitis/icestorm/tree/raw_usb/iceprog (this should work on Linux, but will need modification again to work on macOs)
3. For anyone using the production test tools (either reset.py, or the actual production test), they will need to switch over to the raw_usb branch in tillits-key1 as well: https://github.com/tillitis/tillitis-key1/tree/raw_usb

Ideally I'd like to merge all of these changes into the main branch on each repo, but doing so will mean that any programmers with older firmware won't work correctly, and will need to be updated.

My proposal is to make this a clean break, and to merge these changes into each of the updated branches. I added a check to iceprog, that warns the user if their programmer firmware needs to be updated. Perhaps this is enough?
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

quite, 2023-03-28:
I think this has all been merged?

cibomahto, 2023-03-28:
Yep, seems so!

Closed 2023-03-28.

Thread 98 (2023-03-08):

Document NVCM programming procedure

cibomahto, 2023-03-08:
This needs to be placed somewhere in the project documentation-

First, the script needs to be run in a python virtual environment. It can use the same one as the production test, so this would be sufficient to set it up:

    ./run (then ctrl+c to exit the production test once it's set up)
    . venv/bin/activate

Next, there are three separate steps that need to be performed for NVCM programming: write, verify, then secure. Note that the device will boot from nvcm once the write stage is completed, but it will still allow read backs until the secure command is completed.

    ./pynvcm.py --write ../application_fpga/application_fpga.bin --my-design-is-good-enough
    ./pynvcm.py --verify ../application_fpga/application_fpga.bin
    ./pynvcm.py --secure --my-design-is-good-enough

dehanj, 2023-08-29:
@cibomahto i'm about to break out the pynvcm.py with friends to a separate repository to separate it a bit from the rest in this repo.
Just to cross-check, it is still fine to do the write, verify and secure in one go? It seems to work fine during my tests, but got a bit curious since you mention it as three seperate steps here
```
./pynvcm.py --write ../application_fpga/application_fpga.bin --verify ../application_fpga/application_fpga.bin --secure --my-design-is-good-enough
```

cibomahto, 2023-08-30:
I think it's fine, the Lattice tools don't power cycle the chip between these steps.

Just note that pynvcm doesn't honor the order of operations passed to it; it has a fixed order that it evaluates them (which works for this case):
https://github.com/tillitis/tillitis-key1/blob/7cd085a17e2b7849ad4ff192286a65678412d2eb/hw/production_test/pynvcm.py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

I think I wrote it as separate steps for clarity.

dehanj, 2023-08-31:
Thanks, appreciate the clarity!

dehanj, 2023-09-11:
pynvcm.py now lives in its own repo: https://github.com/tillitis/pynvcm

We have not removed these files from this repo, but it will most likely be done in the near future, so closing this.

Closed 2023-09-11.

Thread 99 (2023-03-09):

Accelerate blake2s with hardware support

secworks, 2023-03-09:
We would like to increase performance in blake2s by moving the frequent parts into HW.

secworks, 2023-03-09:
The following branch contain a HW implementation of the Blake2s G-function. SW writes a, b, c, d, m0 and m1 variables and then read out the updated values for a, b, c, d.

https://github.com/tillitis/tillitis-key1/tree/blake2s_hw

The implementation is a hair too big and we end up with 103% utilization of LCs.

secworks, 2023-03-28:
There is an even more minimal acceleration (that is also not 100% correct) for BLAKE2s in the following branch:
https://github.com/tillitis/tillitis-key1/compare/main...minimal_blake2s_hw

In this branch we basically accelerate those operations in the G function that takes more than two operators, or can be combined into being so. We calculate the result from two different operations in parallel, and SW is responsible for reading out the result it wants. This saves a control MUX. The implementation fits in the FPGA, but timing is < 18 MHz.

secworks, 2023-05-03:
Will not be integrated in the TKey1 device.

LoupVaillant, 2023-05-29:
Hi,

If I may there may be lower hanging fruits before we start to add actual hardware support. It’s something I’ve noticed with BLAKE2b on my out-of-order 64-bit laptop CPU, that _might_ affect the small RISC-V core as well: loading bytes in the update function:

```c
void blake2s_update(blake2s_ctx *ctx,
    const void *in, size_t inlen)       // data bytes
{
    for (size_t i = 0; i < inlen; i++) {
        // blake2s_compress() and stuff
        ctx->b[ctx->c++] = ((const uint8_t *) in)[i]; // THIS LINE MAY BE VERY SLOW
    }
}
```

On big out of order cores I noticed that loading bytes one by one takes up so much time that switching to loading word by word improved my performance by over 50%. Now this significantly complicated my own update function, whose current version looks like the following monster:

```c
void crypto_blake2b_update(crypto_blake2b_ctx *ctx,
                           const u8 *message, size_t message_size)
{
	// Avoid undefined NULL pointer increments with empty messages
	if (message_size == 0) {
		return;
	}

	// Align with word boundaries
	if ((ctx->input_idx & 7) != 0) {
		size_t nb_bytes = MIN(gap(ctx->input_idx, 8), message_size);
		size_t word     = ctx->input_idx >> 3;
		size_t byte     = ctx->input_idx & 7;
		FOR (i, 0, nb_bytes) {
			ctx->input[word] |= (u64)message[i] << ((byte + i) << 3);
		}
		ctx->input_idx += nb_bytes;
		message        += nb_bytes;
		message_size   -= nb_bytes;
	}

	// Align with block boundaries (faster than byte by byte)
	if ((ctx->input_idx & 127) != 0) {
		size_t nb_words = MIN(gap(ctx->input_idx, 128), message_size) >> 3;
		load64_le_buf(ctx->input + (ctx->input_idx >> 3), message, nb_words);
		ctx->input_idx += nb_words << 3;
		message        += nb_words << 3;
		message_size   -= nb_words << 3;
	}

	// Process block by block
	size_t nb_blocks = message_size >> 7;
	FOR (i, 0, nb_blocks) {
		if (ctx->input_idx == 128) {
			blake2b_compress(ctx, 0);
		}
		load64_le_buf(ctx->input, message, 16);
		message += 128;
		ctx->input_idx = 128;
	}
	message_size &= 127;

	if (message_size != 0) {
		// Compress block & flush input buffer as needed
		if (ctx->input_idx == 128) {
			blake2b_compress(ctx, 0);
			ctx->input_idx = 0;
		}
		if (ctx->input_idx == 0) {
			ZERO(ctx->input, 16);
		}
		// Fill remaining words (faster than byte by byte)
		size_t nb_words = message_size >> 3;
		load64_le_buf(ctx->input, message, nb_words);
		ctx->input_idx += nb_words << 3;
		message        += nb_words << 3;
		message_size   -= nb_words << 3;

		// Fill remaining bytes
		FOR (i, 0, message_size) {
			size_t word = ctx->input_idx >> 3;
			size_t byte = ctx->input_idx & 7;
			ctx->input[word] |= (u64)message[i] << (byte << 3);
			ctx->input_idx++;
		}
	}
}
```

Now in the PicoRV32 core I don’t expect the speed up to be nearly as impressive, but I expect it costs little firmware ROM, and no FPGA gates at all. It might be worth trying out someday.

---

Now I understand actual hardware support may not be worth adding, but I have a couple ideas. How about, instead of implementing the full G function, we’d only implement tiny bits of it in a couple dedicated instructions? Recalling the G function’s main shape:

```c
a += x;  a += b;  d ^= a;  d >>>= 16;
         c += d;  b ^= c;  b >>>= 12;
a += y;  a += b;  d ^= a;  d >>>=  8;
         c += d;  b ^= c;  b >>>=  7;
```

I see a couple candidates for macro-op fusion or dedicated opcodes (`a`, `b`, and `c` are registers, `k` is a constant).

    a = (a + b) + c
    a = (a ^ b) >>> k
    a += b;  c ^= a;  c >>>= k

For the ones involving `k` we could have 4 dedicated opcodes instead of using the barrel shifter. For the last one I even suspect that’s the only way to make it work without lowering frequency.

Though if we’re being honest, the main bottleneck right now probably lies in asymmetric operations. If special hardware support were ever to be added the priority is probably bignum arithmetic, to speed up elliptic curves (and polynomial hashes). Of course there’s no way we’d ever add big multipliers on the puny ICE, I was thinking more of 32->64 bits MUL-ADD instructions, likely separated into MULADD and MULADDH[S] or like MUL and MULH.

Though now the only way to take advantage is for application writers to use those likely non-standard instructions deliberately, either by patching code generation, adding intrinsics, or writing assembly by hand. Probably best left to users of unlocked version.

secworks, 2023-05-30:
Hi!
First, thanks for great comments and ideas!
Changing from byte by byte-copy to w32 copy is a really good idea. It asymptotically reduce the number of read-write ops by four. One needs to measure this of course, but should provide some performance benefit.

I've actually implemented three versions of HW acceleration for blake2s (BLAKE2s, really important according to J-P Aumasson): A full blake2s (https://github.com/secworks/blake2s), a core that perform the G-function, and the minimal version that was related to this issue. The minimal version basically accepts three operands and provides two results in parallel - which is pretty close to what you are suggesting with (a = (a + b) + c and a = (a ^ b) >>> k)

  always @*
    begin : b2_gf_logic
      blake2s_res0 = blake2s_op0_reg + blake2s_op1_reg + blake2s_op2_reg;
      blake2s_res1 = ~blake2s_op0_reg ^ blake2s_op1_reg ^ blake2s_op2_reg;
    end

The second one (blake2s_res1) is incorrect. It should be a barrel shifter controlled by one of the three operands as k (for example blake2s_op0_reg). The reason for the code was just to see that we could fit even this amount of extra logic resources. Changing to a barrel shifter would eat up even more resources than inverse and xor. Unfortunately, even this very minimal acceleration does not fit in our highly allocated FPGA. I can get the resources, but the routing to get to the resources becomes so long that the clock frequency drops below our target 18 MHz.

The purpose of having two results from the same operands is to have fewer operand registers and muxes to select what operation to perform. There will still be a mux selecting which result to read out. The changes SW part of Blake2s would know which result would be valid and read out the appropriate result.

There is a coprocessor interface on the PicoRV32 (pcpi), which could potentially open up for not having to copy register contents to registers in a core. Unfortunately pcpi doesn't support three operands (since the PicoRV32 is a two operand, one result reg-reg machine). So using pcpi would still require the coprocessor to have hold registers and some control logic.  One could potentially see a way to modify the CPU to support three operand operations, but the PicoRV32 doesn't lend itself easily to those more radical modifications. It would for example hit the register file implementation quite hard. The easy route for HW acceleration is MMIO connected cores.

Since I can't even fit these two operations, and we were running out of time for the Bellatrix release, I decided do close this issue and move the minimal blake2s acceleration work to a private repo for now. There are several things we would like to use the very few resources left in the FPGA, and acceleration of blake2s is not the highest priority. But if/when we have a FPGA with more resources I'm sure we will add blake2s HW in some form. One reason is that we would like to not have the Unique Device Secret in Embedded Block Ram, just registers. This would make evil maid-attack much harder. Having the blake2s state in discrete registers, and initialize them with the UDS would allow us to do that.

Regarding the performance - blake2s is used in a several ways not directly related to asymmetric operations. One thing we do every time an application is being loaded onto the TKey device, is to measure it loading it into the application RAM - measure means calculating a blake2s digest of the app together with the Unique Device Secret (UDS) and any User Supplied String (USS). If we could improve the performance of blake2s, we could potentially reduce the time it takes to load the application.

The random number generator app use blake2s in a Hash_DRBG construct to generate the random numbers (periodicallty seeded by the TRNG). And if used in the new signed randomness-mode, it will also calculate a blake2s digest for the random numbers provided to the host. Other applications may also be using the blake2s provided by the FW, so a performant blake2s is quite important.

LoupVaillant, 2023-05-30:
Thanks for your detailed answer. I figured you had good reasons, but man _that_ is due diligence.

> If we could improve the performance of blake2s, we could potentially reduce the time it takes to load the application.

I don't know the relative performance of download and hashing, but I was thinking that perhaps the current hardware (including bitstream) allows parallel download and computation? If it does, interleaving hashing with download might speed things up a bit even if the actual performance of BLAKE2s isn't improved.

_(Just one little regret here: programs come in 127 byte chunks, while they theoretically could have come in 128 byte chunks if we omitted the header just this once.  It would have made optimising incremental hashing a teeny bit easier, since 128 bytes mean exactly two BLAKE2s blocks. Though it would also have broken your firmware protocol's orthogonality…)_

secworks, 2023-05-30:
Good point on the protocol

Closed 2023-05-03.

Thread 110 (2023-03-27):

cannot program again after aborting with ctrl-c

quite, 2023-03-27:
If I run tillitis-iceprog, and abort it using ctrl-c, then i cannot run it again -- it hangs after saying it has raw power. It does not matter if there is a usb stick sitting in the jig or not. The programmer has to be re-plugged to get it working again.

cibomahto, 2023-03-27:
This is probably because the usb device isn't released properly when the program is interrupted by SIGINT.

I think the correct way to fix that is (in rpi_pico_interface.c) to install a signal handler after iceprog claims the device, something like this:

```
void close_on_sigint(int unused) {
    close(); // Call the close routine to release the USB device
}
```

And register the handler before [printing the 'raw power' message](https://github.com/tillitis/icestorm/blob/1d3351826dfbb58133a0a44be91814a78c5f2ff8/iceprog/rpi_pico_interface.c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) :

   signal(SIGINT, close_on_sigint);

The previous communication protocol used HID, and this might have been handled automatically by the hidapi library, or might not have been needed if it used the kernel HID interface instead of the USB interface.

quite, 2023-03-27:
doing the `close()` on `SIGINT` also does not help.

quite, 2023-03-27:
Can you reproduce? Maybe this is on my AMD laptop, that also doesn't benefit from any speed increase heh

quite, 2023-03-28:
Seems ctrl-c:ing does not cause problems on Intel laptop

quite, 2023-03-28:
seems a call to `flash_release_reset()` was what was needed. But I think i'm gonna catch SIGINT in main, let the handler set a bool and let while/for loops stop when that bool is true. And if interrupted probably exit the program with code 1.

Closed 2023-03-30.

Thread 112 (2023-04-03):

Force CPU-hang on errors in FW

secworks, 2023-04-03:
I suggest that errors caught by the FW should be handled by forcing the CPU to hang, not by jumping to an error loop that does the LED blinking. A SW loop could possibly be forced to jump somewhere. By triggering an illegal instruction, the CPU will hang and stop executing. The external effect will be the same - blinking red.

dehanj, 2023-09-11:
Use `assert_fail()` from `tkey-libs`.
This will harmonize code used and lower the amount of code to maintain.

mchack-work, 2023-09-11:
See https://github.com/tillitis/tillitis-key1/issues/129

dehanj, 2024-03-14:
Closes with #168

Closed 2024-03-18.

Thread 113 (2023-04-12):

Side channel leakage in memeq

secworks, 2023-04-12:
The function memeq in lib.c makes an early return when non equal values are found. This creates a timing based side-channel. The memeq function is (currently) only used by the test FW. But we should fix this anyway.

The branch https://github.com/tillitis/tillitis-key1/tree/silence_memeq contain a fix that ensure that the function does not do an early return.

secworks, 2023-04-12:
Closed by https://github.com/tillitis/tillitis-key1/commit/f0983af0f1ac4695f7a68e9056dce12991469736

Closed 2023-04-12.

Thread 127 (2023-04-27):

Debug Verilator simulation

secworks, 2023-04-27:
The Verilator top level simulation seems not to work. We should debug and then add it to the CI flow.

secworks, 2023-06-29:
The verilator simulation builds and starts. It can respond to signals (as touch events). It also opens a pty that should be possible to use to load apps. @mchack-work  will try and do that. If that works, it seems the Verilator model works.

The next step would be to decide how to integrate into the CI-flow. For example load a simple app.

secworks, 2023-09-11:
Reassign to MC.

mchack-work, 2023-09-13:
The Verilator (version  5.014) build stops with these complaints:

```
%Warning-UNOPTFLAT: /home/mc/tillitis/git/tillitis-key1/hw/application_fpga/rtl/rom.v:46:16: Signal unoptimizable: Circular combinational logic: 'application_fpga.rom_inst.rom_ready'
   46 |   reg          rom_ready;
      |                ^~~~~~~~~
                    ... For warning description see https://verilator.org/warn/UNOPTFLAT?v=5.014
                    ... Use "/* verilator lint_off UNOPTFLAT */" and lint_on around source to disable this message.
                    /home/mc/tillitis/git/tillitis-key1/hw/application_fpga/rtl/rom.v:46:16:      Example path: application_fpga.rom_inst.rom_ready
                    /home/mc/tillitis/git/tillitis-key1/hw/application_fpga/tb/application_fpga_vsim.v:345:3:      Example path: ALWAYS
                    /home/mc/tillitis/git/tillitis-key1/hw/application_fpga/tb/application_fpga_vsim.v:92:17:      Example path: application_fpga.rom_cs
                    /home/mc/tillitis/git/tillitis-key1/hw/application_fpga/rtl/rom.v:59:3:      Example path: ALWAYS
                    /home/mc/tillitis/git/tillitis-key1/hw/application_fpga/rtl/rom.v:46:16:      Example path: application_fpga.rom_inst.rom_ready
```

but building with `-Wno-fatal` works. However running the resulting simulation yields disappointing results:

```
% tkey-runapp --port /dev/pts/5 apps/blink/app.bin
Connecting to device on serial port /dev/pts/5 ...
GetNameVersion failed: ReadFrame: Read timeout
```

dehanj, 2024-06-17:
Did a quick check, the warnings does not seem to be present anymore while building.
I have not tried to communicate with the port it gives.

But is this something that we want to finish or should we close and deprecate this?

mchack-work, 2024-06-18:
Having a full simulator in software seems very useful for me. I don't think it's a top priority, but it would certainly help.

I can also build without warnings now. However...

```
% ./verilated/Vapplication_fpga
                                                                    
generate touch event: "$ kill -USR1 202223"
pty: /dev/pts/9

% tkey-sign --port /dev/pts/9 -G -p key.pub
WARNING: App already loaded.
GetAppNameVersion: ReadFrame: Read timeout
Couldn't load signer: no TKey on the serial port, or it's running wrong app (and is not in firmware mode)
```

dehanj, 2024-11-12:
This might not be the only problem, but at least the uart is configured wrong for the Verilator simluation.

In `hw/application_fpga/tb/application_fpga_verilator.cc`
```
// Clock: 18 MHz, 62500 bps
// Divisor = 18E6 / 62500 = 288
#define BIT_DIV 288
```

dehanj, 2024-12-09:
Seem to be fixed with the PR linked above, albeit it takes an awful amount of time to load an app (like 4 minutes).
A solution for that is worked on separately.

Closed 2024-12-09.

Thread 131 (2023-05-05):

Brittle "case hook" for keyring/lanyards

Doctor-love, 2023-05-05:
The "case hook/hole" for attaching the TKey to a keyring/lanyard seems to be quite brittle - mine survived for about two days before breaking.

IMHO this is not a major thing considering the current state of the device, but I would suggest changing the case mold/print or material to make it a bit stronger.

dehanj, 2023-05-11:
We are working on a solution to make the casing less brittle. I have no date on when it will be completed however. Thanks for the feedback.

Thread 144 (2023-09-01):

possible compatible hardware: FOMU

coelner, 2023-09-01:
Maybe this is also a capable device to use:

https://tomu.im/fomu.html
https://www.crowdsupply.com/sutajio-kosagi/fomu#products
https://workshop.fomu.im/en/latest/background.html

    FPGA: Lattice ICE40UP5K
    Speed: 48 MHz external oscillator
    RAM: 128 kB RAM for a soft CPU¹
    Storage: 2 MB SPI flash
    Connectivity: USB 2.0 FS (12 Mbps)
    Buttons: Four
    LEDs: One RGB

rel: https://github.com/tillitis/tillitis-key1/issues/141

The CH552 is missing, but AFAIK it is integrated into the FPGA via tinyUSB (https://github.com/hathach/tinyusb)

secworks, 2023-09-04:
Hi!

Yes, the FOMU is close to the TKey1 in terms of functionality.
Unfortunately, you will not be able to fit the TKey1 FPGA design and the TinyUSB core in the same device. We looked at using TinyUSB or another open FPGA based USB solution on the TKey1. (One can still see this in the name "application_fpga" for the FPGA design in TKey1, there would have been an "interface_fpga" in front of it. Due to reliabilty issues and time constraints, we had to change to the CH552.)

coelner, 2023-09-04:
Well, too bad. But thanks for the explanation.

Closed 2023-09-04.

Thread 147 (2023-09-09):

How do we retrieve the Tkey name & version?

LoupVaillant, 2023-09-09:
So at this point I have read the fine manual, scoured the client Go code *and* the Firmware C code, to try and decipher what magic numbers exactly I'm supposed to send to the TKey to get its name & version, and all I managed to get so far was the blinking red LED.

Currently, the following program triggers the invalid blinking red state (I'm using Ubuntu):

```c
#include <stdio.h>
#include <stdint.h>

int main(void)
{
	FILE   *tkey   = fopen("/dev/ttyACM0", "r+");
	uint8_t cmd[2] = { 0x10, 0x01, };
	fwrite(cmd, 1, sizeof(cmd), tkey);
	return 0;
}
```

As far as I understand I'm supposed to send 2 bytes: the framing header and the command. I've read the header should look like this:

- **Bit 7:** zero
- **Bits 6-5:** Don't care (tag)
- **Bits 4-3:** 2 (firmware endpoint)
- **Bit 2:** zero
- **Bit 1-0:** zero (payload has size one)

The only bit I have to set is bit 4, so `0x10` should work. Now I did notice that your [client code](https://github.com/tillitis/tkeyclient/blob/main/tkeyclient.go#L136) uses the value 2 for the tag, but trying `0x50` didn't work either. Plus, I couldn't find any place in the firmware that validates that tag (all 4 values look valid). As for the payload, it looks like it should be just the command byte: `FW_CMD_NAME_VERSION = 0x01`.

Everything I've read tells me sending `{0x10, 0x01}`, should work, but all it does is crashing the TKey! What did I miss?

_(Note: I have successfully verified my TKey as genuine so I'm pretty sure it works.)_

LoupVaillant, 2023-09-10:
Ok, after a good night sleep, it appears we need to set the baud rate manually (apparently either Linux or USB is too stupid to fetch/communicate the actual baud rate of the device). Now I need to figure out the way to do that from C — for some reason it seems to require more than one system call.

LoupVaillant, 2023-09-10:
I found a way to change the baud rate, but it still doesn't work. Here's what I've tried:

```c
#include <asm/termbits.h>
#include <assert.h>
#include <fcntl.h>
#include <stdio.h>
#include <stdint.h>
#include <sys/ioctl.h>
#include <unistd.h>

int main(void)
{
	// Open device
	int tkey = open("/dev/ttyACM0", O_RDWR | O_NONBLOCK | O_NOCTTY);
	assert(tkey != -1);

	// Change output speed
	struct termios2 tio;
	assert(ioctl(tkey,TCGETS2, &tio) == 0);
	tio.c_cflag &= ~CBAUD;
	tio.c_cflag |= BOTHER;
	tio.c_ospeed = 62500;  // This is the TKey's bauds rate, right?
	assert(ioctl(tkey, TCSETS2, &tio) == 0);

	// Send command
	uint8_t cmd[2] = { 0x10, 0x01, };
	assert (write(tkey, cmd, sizeof(cmd)) == sizeof(cmd));

	sleep(1); // We need to wait for the Tkey to crash
	return 0;
}

```

I basically followed the `tty_ioctl` (there's an example at the end), and it still doesn't work, the TKey still goes blinking red. Any idea how to make this work? _(Short of using Go's stdlib of course.)_

dehanj, 2023-09-11:
Hi,
Just want to let you know that we have seen this and we will get back to you asap, but Mondays some times have a tendency to be full of things you have to to..

LoupVaillant, 2023-09-11:
No problem.

Scouring wider and digging deeper, I learned that there are more parameters to serial interfaces than just speed:

* Linux seems to insert stuff like "terminal mode" or whatnot, where the serial port could take over as a terminal or something.
* We need to defined the length of the stop bit.
* There are different ways to do parity.
* There are different byte lengths (from 5 to 8 bits apparently).

Maybe we need to set up more than the speed?

Also, I've found another way to crash the tkey (rest of the program is the same, except includes):

```
struct serial_struct serial;
assert(ioctl(tkey, TIOCGSERIAL, &serial) == 0);
printf("Baud base: %d\n", serial.baud_base);
serial.custom_divisor = serial.baud_base / 62500;
serial.flags         &= ~ASYNC_SPD_MASK;
serial.flags         |=  ASYNC_SPD_CUST;
assert(ioctl(tkey, TIOCSSERIAL, &serial) == 0);
```

One thing i've noticed here is that `serial.baud_base` has a value of a big flat _zero_. I'm not going very far with such a broken number. I have no idea what is happening, so far the tutorials I've seen on the internet promised me the baud base would be set to the correct value after the `ioctl(2)` call.

Something's going on, I'll run the official TKey verification program again (on Windows _and_ Linux this time).

LoupVaillant, 2023-09-11:
TKey verification app successfully verified my key both on Windows and Linux. I have the purple light, and the following successful output on Linux:

```
Auto-detected serial port /dev/ttyACM0
Connecting to device on serial port /dev/ttyACM0 ...
Firmware name0:'tk1 ' name1:'mkdf' version:5
TKey UDI: 0x01337081000000ee(BE) VendorID:0x1337 ProductID:2 ProductRev:1
Fetching verification data from https://tkey.tillitis.se/verify/01337081000000ee ...
Verification data was created 2023-05-05T09:22:22Z
Auto-detected serial port /dev/ttyACM0
Connecting to device on serial port /dev/ttyACM0 ...
Firmware name0:'tk1 ' name1:'mkdf' version:5
Loading verisigner-app built from tag:verisigner-v0.0.3 hash:f8ecdcda53a296636a0297c250b27fb6… ...
App loaded.
App name0:'veri' name1:'sign' version:3
TKey firmware was verified, size:4192 hash:3769540390ee3d990ea3f9e4cc9a0d1a…
TKey is genuine!
```

Now I know for sure my system is capable of talking with the TKey. I just don't how. I guess the proper sequence of system calls is buried somewhere in the Go standard library, but there are so many indirections I have yet to exfiltrate it _(I did managed to reproduce their auto-detection though)_.

mchack-work, 2023-09-11:
The speed 62500 bit/second is correct. Sending `{0x10, 0x01}` or as the Go package does, `{0x50,0x01}` should work.

You might want to try this with the qemu emulator instead to get some debug output and maybe modifiy it to send even more debug output to the terminal. Compile the firmware without `-DNOCONSOLE` to be able to see output and use the `htif_puts()` and friends. Note that qemu uses a pty instead of a real serial port tty. That might come with its own problems.

You may want to begin with using qemu with the test firmware, target testfw.elf, instead of the real firmware to just get some human readable output.

Another way of testing and developing is to use `tkey-runapp` and load a simple device app that just outputs something. Then attach your C client program to just read something and see that it works.

We mean to supply C libraries on the client side as well, eventually.

LoupVaillant, 2023-09-11:
I'll see about trying that, but… if the TKey goes blinking red when I send 2 presumably correct bytes, I can only conclude the data it actually received has been garbled somehow. It is overwhelmingly likely that the QEMU emulator will either:

* Work out of the box if serial speed doesn't matter (say the USB/serial port isn't cycle accurate and just receives everything that was sent);
* or show me data I didn't sent (because it has been garbled).

> We mean to supply C libraries on the client side as well, eventually.

That would be real nice.

mchack-work, 2023-09-11:
qemu isn't picky about speed at all. We're not emulating the USB controller. If you're seeing garbled data there too, something else is wrong. Might be a useful hint.

LoupVaillant, 2023-09-11:
At last, it works!

Seriously, opening a serial port correctly with raw system calls is a _nightmare_. There's no way I could ever have found how to do that by myself. I'm not aware of any comprehensive tutorial on the internet, so I did the only thing I could: painstakingly prying the standard Go library open.

Here is my working program:

```c
#include <asm/termbits.h>
#include <assert.h>
#include <fcntl.h>
#include <stdio.h>
#include <stdint.h>
#include <string.h>
#include <sys/ioctl.h>
#include <unistd.h>

int main(void)
{
	///////////////////////
	/// BEGIN NIGHTMARE ///
	///////////////////////

	int tkey = open("/dev/ttyACM0", O_RDWR | O_NDELAY | O_NOCTTY);
	assert(tkey != -1);

	// Get settings
	struct termios2 tio;
	assert(ioctl(tkey,TCGETS2, &tio) == 0);

	// Set local mode
	tio.c_cflag |= CREAD;
	tio.c_cflag |= CLOCAL;

	// Set raw mode
	tio.c_lflag &= ~ICANON;
	tio.c_lflag &= ~ECHO;
	tio.c_lflag &= ~ECHOE;
	tio.c_lflag &= ~ECHOK;
	tio.c_lflag &= ~ECHONL;
	tio.c_lflag &= ~ECHOCTL;
	tio.c_lflag &= ~ECHOPRT;
	tio.c_lflag &= ~ECHOKE;
	tio.c_lflag &= ~ISIG;
	tio.c_lflag &= ~IEXTEN;

	tio.c_iflag &= ~IXON;
	tio.c_iflag &= ~IXOFF;
	tio.c_iflag &= ~IXANY;
	tio.c_iflag &= ~INPCK;
	tio.c_iflag &= ~IGNPAR;
	tio.c_iflag &= ~PARMRK;
	tio.c_iflag &= ~ISTRIP;
	tio.c_iflag &= ~IGNBRK;
	tio.c_iflag &= ~BRKINT;
	tio.c_iflag &= ~INLCR;
	tio.c_iflag &= ~IGNCR;
	tio.c_iflag &= ~ICRNL;
	tio.c_iflag &= ~IUCLC;

	tio.c_oflag &= ~OPOST;

	// Block reads until at least one char is available (no timeout)
	tio.c_cc[VMIN ] = 1;
	tio.c_cc[VTIME] = 0;

	// Disable flow control
	tio.c_cflag &= ~CRTSCTS;

	// Skip modem control, because the following fails:
	//   int status;
	//   ioctl(tkey, TIOCMGET, &status);

	// Disable parity
	tio.c_cflag &= ~PARENB;
	tio.c_cflag &= ~PARODD;
	tio.c_cflag &= ~CMSPAR;
	tio.c_iflag &= ~INPCK;

	// Set data bits
	tio.c_cflag &= ~CSIZE;
	tio.c_cflag |= 8;  // 8-bit bytes

	// Set stop bit (1)
	tio.c_cflag &= ~CSTOPB;

	// Set speed
	tio.c_cflag &= ~CBAUD;
	tio.c_cflag |= BOTHER;
	tio.c_cflag &= ~(CBAUD << IBSHIFT);  // Advised by man page, not in Golang
	tio.c_cflag |= BOTHER << IBSHIFT;    // Advised by man page, not in Golang
	tio.c_ispeed = 62500;
	tio.c_ospeed = 62500;

	// Set modified settings
	assert(ioctl(tkey, TCSETS2, &tio) == 0);

	// Set the port back to blocking (why did we open(2) with O_NDELAY??)
	int flags = fcntl(tkey, F_GETFL);
	assert(flags != -1);
	assert(fcntl(tkey, F_SETFL, flags & ~O_NONBLOCK) == 0);

	// Acquire exclusive access (I guess it makes sense for a serial port)
	assert(ioctl(tkey,TIOCEXCL) == 0) ;

	// Skip Pipe hack that the Go library uses to get around blocking reads

	/////////////////////
	/// END NIGHTMARE ///
	/////////////////////

	// Send command
	uint8_t cmd[2] = { 0x10, 0x01, };
	assert (write(tkey, cmd, sizeof(cmd)) == sizeof(cmd));

	// Read response
	uint8_t rsp_header;
	assert(read(tkey, &rsp_header, 1) == 1);
	uint8_t header_version  = (rsp_header >> 7) & 1;
	uint8_t header_tag      = (rsp_header >> 5) & 3;
	uint8_t header_endpoint = (rsp_header >> 3) & 3;
	uint8_t header_ok       = (rsp_header >> 2) & 1;
	uint8_t header_size     = (rsp_header >> 0) & 3;

	printf("Response header: %x\n", rsp_header);
	printf("    version : %u\n", header_version );
	printf("    tag     : %u\n", header_tag     );
	printf("    endpoint: %u\n", header_endpoint);
	printf("    ok      : %u\n", header_ok      );
	printf("    size    : %u\n", header_size    );

	assert(header_size == 2);
	uint8_t buf[32];
	for (size_t i = 0; i < sizeof(buf); i++) {
		assert(read(tkey, buf + i, 1) == 1);
	}
	char     name[9] = {0}; memcpy(name    , buf    , 8);
	uint32_t version;       memcpy(&version, buf + 8, 4); // Little Endian host

	printf("---\n");
	printf("Name   : %s\n", name);
	printf("Version: %u\n", version);

	return 0;
}
```

Now I can work. :sleepy:

dehanj, 2023-09-12:
Great that you got it to work.
Thanks for the feedback, we will update the dev-handbook.

Closed 2023-09-11.

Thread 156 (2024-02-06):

Enhancement idea: persistent upcounter for audit logs

gvegidy, 2024-02-06:
Idea: Add a counter to the hardware that stores it's value within the secured boundary. The counter can only be increased and not be decremented or overflow (=fail instead of overflow).

### Usecase

Consider you want to use your tillitis key for very sensitive operations, for example code signing or authorizing other keys. You want to be able to fully audit these operations afterwards, as in being able to proof that only the sensitive operations that are in the logfile took place and neither were any of them done "off books" nor the log was falsified.

### Use of the counter

Any applet on the tillitis can choose to increase the counter and there is just one counter for all applets to use together. Usually this increment operation will be combined with a signing operation or a multi-step signing operation that includes using an external timestamping service or similar. The new counter value and the data that led to the increase of the counter is then signed with the private key of the tillitis and applet.

In the end the log is stored externally and contains the counter value, metadata like timestamp, applet, operation, hash that was signed and so on and a signature created with the private key of the key and applet. The user is responsible for safe storage of this logfile.

### Auditing

This log can then be compared to the actual current value of the counter and checked for any missing entries of counter values. Also mismatching signatures of course. This allows to proof that the log contains entries for all events that the counter was increased and these entries are not manipulated.

If there are one or more entries in the log missing, it is not possible to reconstruct what happened and which applet was used to increment the counter.

### Hardware implementation

The counter should be big enough to not easily overflow when used reasonably, for example 24 or 32 bit should suffice. Since the least significant bits will be written very often, the hardware implementation should probably contain some kind of wear levelling mechanism to prevent wearout of the flash/eeprom cells used.

The counter must be protected from external overwriting or resetting. This will most probably mean that it should be part of the secret storage that keeps the private key inside the fpga. Since the ice40 to my knowledge does not allow something like this, this feature is probably something for when you design an ASIC for the tillitis in the future. Maybe it could also be prototyped and emulated beforehand by adding an external HSM IC just for this, for example ATECC608B.

dehanj, 2024-03-21:
This is a great feature.
You are right however that the ICE40 does not have any persistent memory, so some external component would be needed. A flash memory would work, storing encrypted data, but would of course quite easily be erased by someone that carries out a physical attack. Is a physical attack something this would need to withstand in your opinion?

I see that I need an NDA with Microchip to dig deeper into ATECC608B, but it seems to have some IO protection so one cannot simply read out/eavesdrop the data over I2C.

gvegidy, 2024-03-21:
> Is a physical attack something this would need to withstand in your opinion?

I'd say yes. If you leave your tillitis key laying around and someone gets hold of it for some time they would be able to reset the counter. The traditional evil maid scenario.

Also if you add an extra hardware storage component for it, you could either add something like a dumb I2C EEPROM or something secured like the ATECC608B. It is both times just one additional IC requiring similar board space.

I have found the full datasheet for the predecessor ATECC608A with a bit of searching and without NDA. AFAIK the ATECC608A and ATECC608B are the same die, they just updated the firmware to harden it against some power side channel attacks that were found. So it is probably very similar. But going the NDA route is probably the proper way when including it in future designs.

You can establish a secure communication channel between the FPGA and the ATECC that is derived from the main secret within the FPGA once. Then all further comms between the FPGA and ATECC is encrypted and authenticated with that.

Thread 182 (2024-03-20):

Verilog linter warnings

dehanj, 2024-03-20:
While updating our tools to a later version of Verilator and updating the lint flags to Verilog-2005 we came across a few new  warnings, see below.

We don't have a quick solution to this for a few reasons:
1. Some of these comes from dependencies we have not written and don't want to edit at the moment.
2. The warning for the oscillator ( Circular combinational logic ) is true, but also the intended design of our oscillator. We need to find a way to suppress it. Setting the the linter off with `UNOPTFLAT` didn't seem to take for some reason.

```
verilator +1364-2005ext+ --lint-only  -Wall -Wno-DECLFILENAME --timescale 1ns/1ns -DNO_ICE40_DEFAULT_ASSIGNMENTS \
-DBRAM_FW_SIZE=1536 \
-DFIRMWARE_HEX=\"/build/firmware.hex\" \
-DUDS_HEX=\"/build/data/uds.hex\" \
-DUDI_HEX=\"/build/data/udi.hex\" \
--top-module application_fpga \
config.vlt /build/rtl/application_fpga.v /build/rtl/clk_reset_gen.v /build/rtl/ram.v /build/rtl/rom.v /build/rtl/fw_ram.v /build/core/picorv32/rtl/picorv32.v /build/core/timer/rtl/timer_core.v /build/core/timer/rtl/timer.v /build/core/uds/rtl/uds.v /build/core/uds/rtl/uds_rom.v /build/core/touch_sense/rtl/touch_sense.v /build/core/tk1/rtl/tk1.v /build/core/tk1/rtl/udi_rom.v /build/core/uart/rtl/uart_core.v /build/core/uart/rtl/uart_fifo.v /build/core/uart/rtl/uart.v /build/core/trng/rtl/rosc.v /usr/local/share/yosys/ice40/cells_sim.v \
>lint_issues.txt 2>&1 \
&& { rm -f lint_issues.txt; exit 0; } \
|| {   cat lint_issues.txt; exit 1; }
%Warning-WIDTHEXPAND: /usr/local/share/yosys/ice40/cells_sim.v:184:19: Operator VAR 'LUT_INIT' expects 16 bits on the Initial value, but Initial value's CONST '2'h1' generates 2 bits.
                                                                     : ... In instance application_fpga.tk1_inst.rom_i.luts[0].lut_i
  184 |  parameter [15:0] LUT_INIT = 0;
      |                   ^~~~~~~~
                      ... For warning description see https://verilator.org/warn/WIDTHEXPAND?v=5.012
                      ... Use "/* verilator lint_off WIDTHEXPAND */" and lint_on around source to disable this message.
%Warning-UNOPTFLAT: /build/rtl/fw_ram.v:38:16: Signal unoptimizable: Circular combinational logic: 'application_fpga.fw_ram_inst.fw_app_cs'
   38 |   wire         fw_app_cs;
      |                ^~~~~~~~~
                    /build/rtl/fw_ram.v:38:16:      Example path: application_fpga.fw_ram_inst.fw_app_cs
                    /build/rtl/fw_ram.v:128:3:      Example path: ALWAYS
                    /build/rtl/fw_ram.v:34:16:      Example path: application_fpga.fw_ram_inst.tmp_read_data
                    /build/rtl/application_fpga.v:360:3:      Example path: ALWAYS
                    /build/rtl/application_fpga.v:121:17:      Example path: application_fpga.fw_ram_cs
                    /build/rtl/fw_ram.v:48:20:      Example path: ASSIGNW
                    /build/rtl/fw_ram.v:38:16:      Example path: application_fpga.fw_ram_inst.fw_app_cs
%Warning-UNOPTFLAT: /usr/local/share/yosys/ice40/cells_sim.v:178:9: Signal unoptimizable: Circular combinational logic: 'application_fpga.trng_inst.__Vcellout__oscillators[15].osc_inv_f__O'
  178 |  output O,
      |         ^
                    /usr/local/share/yosys/ice40/cells_sim.v:178:9:      Example path: application_fpga.trng_inst.__Vcellout__oscillators[15].osc_inv_f__O
                    /build/core/trng/rtl/rosc.v:118:53:      Example path: ASSIGNW
                    /usr/local/share/yosys/ice40/cells_sim.v:179:8:      Example path: application_fpga.trng_inst.__Vcellinp__oscillators[15].osc_inv_f__I0
                    /usr/local/share/yosys/ice40/cells_sim.v:188:11:      Example path: ASSIGNW
                    /usr/local/share/yosys/ice40/cells_sim.v:178:9:      Example path: application_fpga.trng_inst.__Vcellout__oscillators[15].osc_inv_f__O
%Error: Exiting due to 3 warning(s)
make: *** [Makefile:183: lint] Error 1
```

secworks, 2024-06-10:
We should add simulation or linter models that allow us to run lint. See also https://github.com/tillitis/tillitis-key1/pull/233 for more details on lint warnings and how we solve them for the tk1 core.

dehanj, 2024-06-17:
We still have to keep an eye out for linting, there could be introduced lint warnings that are globally ignored.

Closed 2024-06-17.

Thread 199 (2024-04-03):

Add support for client based device reset

secworks, 2024-04-03:
In order to be able to switch device applications, we need a mechanism that allows the client to perform a reset of the connected TKey device. The idea is to have the USB handler, the CH552 MCU be able to receive a command from the client and notify the FPGA trough a separate channel than the serial link (UART) that a reset is requested.

We have a couple of unused connections between the CH552 and the FPGA. The idea is to commandeer one of these for this signalling.

The firmware also needs a way of identifying when a client reset has been made. It needs this signal to know if it's going to wait for a device app from the client app or boot something else.

## Open questions

- Should a client reset request should always be followed, or if it should be possible to be ignored?
One idea is to ignore reset requests in FW-mode.
- How do we signal status or a response back to the client that we have done the reset?

secworks, 2024-04-03:
One question at this stage is if a host reset request should always be followed, or if it should be possible to be ignored?
One idea is to ignore reset requests in FW-mode.

secworks, 2024-04-03:
Another question is how status, response should be conveyed back to the host.

secworks, 2024-04-03:
Created a branch for development:
https://github.com/tillitis/tillitis-key1/tree/199-add-support-for-host-based-device-reset

secworks, 2024-04-03:
Allocating the interface_rts signal, since it has the same intended direction as the interface_tx UART signal. And 'r' can be interpreted as reset.

secworks, 2024-04-03:
First attempt at implementing the feature has been pushed to the branch and is ready for testing. The FPGA builds and should be stable (if the CH552 keeps the interface_rts signal low). And if pulled high should trigger a FPGA reset.

secworks, 2024-04-04:
I've committed an updated implementation. Basically instead of pulling the reset directly at a client reset request, we instad trigger the reset loop to again be active. This will cause the reset to be asserted as it is when the bitststream has been loaded.

mchack-work, 2024-04-04:
Joachim and I discussed the API. We decided to create a first version that overrides the use of what the memory map calls `TK1_SWITCH_APP`, which will probably change name, into a status register with more added modes besides application mode/firmware mode:

- Power cycle happened
- Client reset
- Internal reset

In this way firmware (And apps! We need to discuss if this is what we want.) will know what kind of reset has happened and how to proceed.

secworks, 2024-04-04:
Commit https://github.com/tillitis/tillitis-key1/commit/92a419e73a3f9404d3370f19dfd7638b4d45b717 now updates the design by moving the reset handling logic to the tk1 core. It can now detect external request, and trigger the clk_reset module to perform a reset. The tk1 core can store the reset status (or better the reason why a reset was triggered). This status can be read out via the tk1 API.

Note that this commit changes the behavior of the ADDR_SWITCH_APP register. When written it will switch mode just as before. But when read, it does not return the fw_app-mode in all 32 bits. Instead the reset-status is returned in bit 17..16, and the fw_app-mode in bit 0 only. So one can not determine the fw_app mode by just checking if the API register is zero or not. In a future update we should change the name of the API register. For example to ADDR_SYS_CTRL_STATUS.

cobratbq, 2024-04-16:
- How can I be sure that such a (client) reset is not performed unexpectedly/maliciously?
  The applications that I've seen, all check for the running firmware/application at start, then assume it is the same for the duration of the session.
- I see benefits during development and when debugging, but not while being used. I can imagine an (desktop) application loading one of several programs depending on the needed function, but doesn't this assume single-request/short-running uses? (As opposed to loading a program, then performing a number of related actions, all of which assume the same program and previous data is loaded.)
- What other use-cases did you have in mind?

Given lack of persistence, sensitive data will likely be sent on every use. Now that a reset is possible, is there always the uncertainty of whether the loaded program has changed?

At the very least, it would be very valuable to allow the loaded program to disable this functionality. (Or vice-versa, enable it for development/debugging purposes.)

secworks, 2024-04-17:
Great comments. The main use case for this is the ability to switch apps, sessions without having to physically pull out and reinsert the TKey. But we need to think through the implications for this. And under what situations it can be accepted.

In the PR, the tk1 core includes a reset control. The purpose is to decide if a reset request should be allowed or not. It also tracks if a reset was caused by power up the device, or if it was due to a reset request. We can extend this with allowing an application to cause a reset. And could also add ability to block, deny client reset requests.

We won't merge this functionality until we know that it provides utility, is safe and works as we want it to. You feedback is very valuable for this.

cobratbq, 2024-04-17:
Here are some thoughts/questions, I still had in mind: the use-case involves loading sensitive data, then repeatedly using this data for several requests, which each provide some input of their own. The application counts on the program's continued execution and having the correct data in memory.

- API-based resets (as part of TKey program-binary) are perfectly fine for me.
- Client-side resets would be fine, if the program can control (disabling or explicitly enabling) client-side resets.

My thoughts are in the direction of avoiding unnecessary interference:
- with the running program, or
- having running program swapped, or
- blocking access through repeated resets.

Probably not a convenient suggestion, possibly overkill: you could prefix response frames with an "identifier", some ephemeral random (read-only) value assigned by firmware. Upon changing, one knows there was a reset (or some change of program). Granted, in most cases you would discover as soon as requests/commands no longer work, although not the root cause. (It's probably not practical. I'm just putting it out there.)

Question:
would this reset mean that the connection with the USB device is lost? E.g. does a desktop application that has an (exclusive) open socket, lose its connection? This would be important in case of switching applications with such a controlled reset.

mchack-work, 2024-04-18:
Some context is needed here, I think.

Consider a number of products in a future product portfolio from
Tillitis:

1. Unchanged TKey.
2. A TKey with HID USB as well as the current CDC.
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
mchack-work, 2024-04-18:
> would this reset mean that the connection with the USB device is lost? E.g. does a desktop application that has an (exclusive) open socket, lose its connection? This would be important in case of switching applications with such a controlled reset.

Probably, yes, but you bring up a good point. We probably have to do
even more stuff in the MCU firmware when a write comes to the special
reset endpoint.

We haven't even started on the MCU firmware. Including not just another
USB endpoint for reset but also HID as well as the current CDC will
be... challenging.

cobratbq, 2024-04-18:
Below my view, with some additional information.

> Makes sense? [..] This might be solved in some other way, perhaps, but how? And what is
the best way?

Sure. I see where you're going. Taking a very high-level perspective, you have: client-side + internal resets, internal resets (from within program), or no resets.

If you want to support a use-case where you __cannot__ have physical access (to disconnect and reconnect the device), you either:

1.  offer client-side resets (if you want absolute control), or
2.  offer a request-byte for asking the loaded program for the reset.

However, (2.) would be a risk, given that you don't have physical access. Assuming a sound program or physical access, then (2.) wouldn't be a problem (IMO).

> Currently, [..] we don't have any way of detecting, say, a long
press [..] Possible to add?

I have little experience with hardware or embedded, but I can't think of anything. IIUC you cannot detect the _touch_ itself, only that a touch was _registered_.

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

True. For what I need, I want to be sure of the triple _(device, program-binary, USS)_, so I perform authentication. (I use [this simple custom protocol](<https://dannyvanheumen.nl/post/simple-asymmetric-ake/> "A simple, asymmetric AKE"), which seems to be enough for my case.) I use app-name and -version to check the API.

> If you're only worried about speaking to the *same* instance [..]

Nah, it's not for that. My current prototype establishes a confidential session. I'm more worried that the random gibberish that it sends gets misinterpreted and the client won't know what's going on because of a sudden reset or app-swap. The problem with resets/app-swap is that it could potentially happen at any moment, and leaves the client guessing. That's why having control over the reset-capability would be very valuable. (Or at least, I assumed that there isn't an unmistakable sign. If the connection interrupts, then _confusion_ isn't going to be a problem.)

> The problem on how to identify to the client that it's the *correct* application on *first start* is harder, [..]

My current idea assumes physical access on first use, and then TOFU. (There's a bit more to it.)

secworks, 2024-04-22:
> I have little experience with hardware or embedded, but I can't think of anything. IIUC you cannot detect the _touch_ itself, only that a touch was _registered_.

The current touch_sensor HW core only supports detection of an event. But the sensor is actually simply presenting a high signal when a touch is performed. It is the core itself that does the event-thing. That is detect a low->high transition ,set at status register for SW to read and acknowledge before being able to detect a new event. There is nothing stopping us from providing the (sampled) input to SW, which could detect a finger present for x time.

dehanj, 2024-08-20:
We now have merge an API-based reset functionallity, only controllable from the TKey.
#242
If it is left unused, the behavior is the same as before, i.e., a client cannot force a reset.

Closed 2024-08-20.

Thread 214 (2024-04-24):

Signal intention of system reset from device app to firmware

mchack-work, 2024-04-24:
Firmware is getting the possibility to load a preloaded app from flash. See https://github.com/tillitis/tillitis-key1/issues/215

We need a way to indicate to the firmware the reason the running app want to do a reset.

*Nota bene*: This issue *only* covers hardware changes for how to send the intention to the firmware.

We should be able to signal a couple of intentions from the running app device to firmware:

1. Reset, load and start a new app from client.
2. Reset, load and start a new app from flash.
3. Reset, load and start an app from client with a matching app hash.
4. Reset, load and start an app from flash (where on flash?), matching an exact app hash.

Number 3 & 4 here means we need to communicate the app BLAKE2s hash of the next stage to the firmware.

If we want to be able to have general support for chaining apps and *sharing data between them* we also need to discuss how that sharing should be done. One idea is to reserve some RAM that won't get overwritten by firmware when resetting.

Also, see the investigation in `docs/tkey_client_reset.md` in internal repo about the bigger picture and threat model about how to initiate a reset signal from the *client*, which is orthogonal to this issue.

mchack-work, 2024-05-16:
Decision on meeting on 2024-05-16 to try to use a touch hold for this function. See attached PR.

Needs a software test.

dehanj, 2024-05-20:
Started to investigate this, the touch sensor have a ~300 ms start up time, see attached picture. During this time the output from the touch sensor will be high, regardless of a touch or not. It seems to go low when it is ready.
This is most likely some power up sequence the touch IC needs, maybe calibration, maybe something else.

On top of this, the sensor is not registering a touch that started before the end of these 300 ms, meaning holding on the touch area and powering up the device, will **not** register a touch. The touch needs to start when the touch IC is ready.

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

SallSim, 2024-09-23:
We will implement this with a protocol.

mchack-work, 2024-09-24:
Our UX spec says we will use a client/app protocol request to ask for a system reset. The hardware support for system reset already exist.

However, we still have no way of communicating the device app's *intent* with a system reset to the firmware. The intent might be to just do a system reset because it's finished with it's work and start everything again, but it might also mean that the device app is calling system reset because the client asked it to, in order to load a new app from the client.

This means that, right now, the firmware will happily just start the preloaded app again and again. Clearly we need some way of communicating this intent to the firmware.

A couple of options (more?):

1. Extend the hardware system reset API to include the intent.
2. Use some part of RAM to indicate intent.
3. Use touch and finger detected instead.

For 2 above we might want to use some reserved way of doing this, like calling another system call in the firmware, and store the intent in `FW_RAM` instead, but that needs analysis.

SallSim, 2025-03-21:
Code needed is copied into filesystem branch.

Closed 2025-03-21.

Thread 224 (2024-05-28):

Remove possible redundant RAM clearing functionality

secworks, 2024-05-28:
(The purpose of this issue is primarily to document the observed behavior.)

In FW start.S there is functionality to clear the RAM by writing zeros, see:
https://github.com/tillitis/tillitis-key1/blob/0454e023cd5c05cf8c84df358c45a05f291e153e/hw/application_fpga/fw/tk1/start.S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

In FW main.c there is functionality to fill the RAM with (pseudo) random data, see:
https://github.com/tillitis/tillitis-key1/blob/0454e023cd5c05cf8c84df358c45a05f291e153e/hw/application_fpga/fw/tk1/main.c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

This functionality is called fairly early in main, see:
https://github.com/tillitis/tillitis-key1/blob/0454e023cd5c05cf8c84df358c45a05f291e153e/hw/application_fpga/fw/tk1/main.c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

The zero fill in start.S was probably added before RAM scrambling was added. But do we still need to fill the RAM with zeros first, or is this now redundant? Removing it would reduce the time before the FW is ready to receive a device app. It would also reduce the size of the FW with a few bytes. If we remove the zero fill we could probably move the random fill to before the call to print_hw_version(), see:

https://github.com/tillitis/tillitis-key1/blob/0454e023cd5c05cf8c84df358c45a05f291e153e/hw/application_fpga/fw/tk1/main.c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

This would make the difference in cycles after reset to when the memory is filled the with random data a few cycles. Basically the number of cycles it takes to jump to main().

secworks, 2024-05-28:
A related issue to this is https://github.com/tillitis/tillitis-key1/issues/162

secworks, 2024-06-04:
I would suggest that we instead of removing the zeroisation loop change it to fill FW_RAM instead of the RAM. This would have three benifits:

1. We would shorten the time until the FW is ready to receive an app to load
2. It would close a hole in regards to possibly have assets in FW_RAM between resets
3. It would separate the purpose of the setup in start.S vs main.c. In start.S, we setup the execution of the FW in main.c. In main.c we set up the execution of device apps.

Closed 2024-06-12.

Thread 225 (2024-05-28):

Remove possibly redundant randomized RAM scrambling during randomised RAM fill

secworks, 2024-05-28:
(This issue is primarily to document an observation.)

The functionality in FW to fill the RAM with pseudo random data is done in scramble_ram(), see:
https://github.com/tillitis/tillitis-key1/blob/0454e023cd5c05cf8c84df358c45a05f291e153e/hw/application_fpga/fw/tk1/main.c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

The function starts by setting the HW scrambling parameters in the memory system to random values. Then the RAM is filled with 'random data' with a PRNG in a loop. Finally the HW scrambling parameters are updated again, to ensure that the scrambling on device app memory accesses are not the same as the ones used to fill the RAM, possibly adding a second layer of obfuscation.

The possible issue with this is that setting of the HW scrambling parameters are done using the TRNG. The TRNG has low bitrate. Basically the effective bit generation speed is in order of one kbps. Since we need 32 bits for each call, the CPU will possibly have to wait thousands of cycles. Esp for the second and fourth request to the TRNG since they happen close in time to request one and three, not giving the TRNG time to generate enough bits.

Removing the first two calls, the one before the random fill loop would probably reduce the time for the FW to be ready to load a device app. Removing them would also reduce the size of the FW with a few bytes.

The big question is if the first scrambling makes the random fill better or not. At least address scrambling should make it harder to guess the PRNG state. But since the scrambling is quite simplistic, this potential gain in obfuscation may not be very big. In fact it may be so that it cause patterns to be inserted. (This is primarily in context of the data scrambling.)

The current PRNG that generates the random data written to RAM is very simplistic. There is a  PR to replace this with something better, see: https://github.com/tillitis/tillitis-key1/pull/201

But replacing the PRNG with something better is probably separate from this discussion. There are also ideas to replace the RAM access scrambling in the memory system with something better. That is also outside of this discussion.

dehanj, 2024-06-03:
Measured the time it takes to do one set:
```
// Set RAM address and data scrambling values
*ram_rand = rnd_word();
*ram_scramble = rnd_word();
```

it takes 30 ms, and from the code I would say that both the calls to the rnd_word() would be a maximal delay in form of waiting for the TRNG to be ready.

Closed 2024-06-14.

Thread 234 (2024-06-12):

Hardware syscall support

dehanj, 2024-06-12:
## Introduction

Our firmware is gaining more functionality. We are developing, in effect, system calls in the firmware so device apps can access flash memory in an isolated way. See PR https://github.com/tillitis/tillitis-key1/pull/298

The firmware will need hardware assistance to keep this safe. We need to protect at least SPI access and the FW\_RAM from the device apps. We would also like to protect the firmware ROM from execution in app mode.

## Hardware requirements

- A system call mechanism. See below for some alternatives.
- Raising privilege mode somehow, probably either a toggled bit or a third mode between FW mode and App mode, whichever is cheaper. In the privileged mode:

  - FW\_RAM available for read/write.
  - SPI master available.
  - ROM executable.
- A way of lowering the privilege mode:
  - FW\_RAM no longer available.
  - SPI master no longer available.
  - ROM not executable. Note that this means ROM is no longer executable in app mode. This breaks BLAKE2s access! Can we live with that?

## System calls

In the RISC-V specification a system call to a kernel (or even a firmware call from a kernel) is initiated with the `ecall` instruction. The higher privileged level registers an exception handler vector (STVEC for kernel, MTVEC for machine mode). When the `ecall` is called the CPU saves the PC, raises the privilege level, and jumps to the registered address for the exception handler. When the handler is finished it jumps back to corresponding saved PC (SEPC or MEPC).

We would like to do something very similar, but preferably without changing anything in the PicoRV32 design. However, PicoRV32 doesn't even implement `ecall`, nor the necessary CSR registers. We are running in machine mode all the time. We are currently not even using the simplified interrupt handling PicoRV32 supports, which would give us at least `ebreak`. If built with IRQ, the design doesn't fit in our chip (160% LC utilization).

We have a couple of options to solve this:

### 1. Traditional syscall

A traditional syscall solution, where firmware registers an address for syscalls, the device app triggers something which makes the hardware raise the privilege (see requirements above) and jump to the address.

The "something" that the device app can trigger can be as easy as a write to a specific memory address. We can probably solve save/restore of the PC with software.

We might even consider implementing a simpler version of `ecall` in PicoRV32 itself, but if we can do it in MMIO that will keep PicoRV32 pristine.

### 2. Blessed address or jump table

A blessed jump or branch table that automatically raises the privilege when the program counter reaches it.

This jump table might be filled in in the building process and be part of the ROM or it might be filled in by firmware when starting. Note that if it's stored in ROM we have to exclude this from the ROM execution prevention.

A function trampoline similar to how we offer the firmware's BLAKE2s function to device apps might be used for something like this.

The design will have to watch the program counter and when it reaches the blessed address(es) in the table (which might be just one slot), it will raise the privilege: make FW\RAM available, ROM executable, and enable SPI.

The BLAKE2s is currently implemented like this: The firmware registers the address of the function to call in an MMIO, `TK1_MMIO_TK1_BLAKE2S` (0xff000040). The contents of `TK1_MMIO_TK1_BLAKE2s` is just the address to the beginning of the C function in the firmware. It's called directly a function pointer right into ROM.

To use this for privelege raising, the design must watch PC for the address stored in `TK1_MMIO_TK1_BLAKE2S` and then raise the privileges.

We might to keep backwards compatibility and use a new MMIO, if it's at all possible, and keep the BLAKE2s one.

More options?

## Existing hardware design PoCs

- #259: Close to the hardware support for number 1. Doesn't actually change PC when triggering. Instead of an address in an exception handler vector, firmware will register an instruction. When triggering that instruction will be fed to the CPU. This might be a jump instruction so it would be very similar. Note though the problems noted in the PR. Would be nicer if we can just insert an address and force a jump.

- #256: Trampoline like in number 2 BLAKE2s but uses PC leaving firmware as a way of automatically leaving the higher privilege?

- #258: Trampoline like BLAKE2s.

- #299: A combination of both #256 and #258. Includes both the automatic privilege raising and revoking, using a blessed address and monitoring if we are executing above ROM. This is based on the persistent storage poc #298 and works on target.

- #305 Use PicoRV32 interrupts to do system calls

## Existing software PoCs

The ~~#273~~  #298 PR uses the existing BLAKE2s as a trampoline to access syscall. It relies on the hardware to raise the privilege.

secworks, 2024-06-24:
A test implementation of this functionality can be found in https://github.com/tillitis/tillitis-key1/pull/243

mchack-work, 2024-09-25:
We have a couple of options to solve the problem:

1. A PC-based solution as suggested in #256 that watches where execution is currently being done and switches on SPI access when PC is pointing to firmware.
2. A function trampoline similar to how we offer firmware's BLAKE2s to device apps. The firmware registers the syscall function to call in an MMIO. When this is called, the hardware switches on SPI access and calls the function while still using the device app's stack. See #258.
3. A general syscall solution, where firmware registers an address for syscalls, the device app triggers some kind of interrupt which makes the hardware enable SPI access and start executing the syscall. We will probably need to access `FW_RAM` as well, for firmware's own stack.

More options?

A beginning of something close to the hardware support for 3 is in #259, even though the design in that PR doesn't actually change PC. Instead, firmware will register an instruction, not an address, and that instruction will be fed to the CPU. This might be a jump instruction so it would be very similar.

I think option 3 is the one with the highest security. Not using the app's stack, for one thing, and passing arguments to the syscall by registers. It will also be immediately familiar to OS developers.

mchack-work, 2024-09-25:
I tried turning on the IRQ in PicoRV32 to use it to implement option 3 syscalls, but unfortunately it's much too big.

We need something a lot simpler in the hardware. We need:

- Possibility for firmware to register a way to reach the syscall code. This might be an address, or like in #259, a jump instruction.
- Some way for the device app to trigger the interrupt. In RV32 it's usually done by the `ecall` instruction but we might not want to touch PicoRV32 and introduce that instruction, so we can do this by writing something, anything, to an MMIO we choose.
- The hardware must then switch to a mode where we can access `FW_RAM` and SPI, and jump to the executed address, probably passing the PC's old value in a register, so the firmware has a chance to jump back again.

What does @jthornblad think about the possibility to do this in hardware, possibly based on #259?

mchack-work, 2024-10-02:
Hardware requirements:

- Change of privilege mode somehow, either a bit for SPI access and FW\RAM or a third mode between FW mode and App ode.

In the privileged mode:

- FW\_RAM available
- SPI master available
- ROM executable

ROM not executable in non-privileged mode.

mchack-work, 2024-10-24:
It seems very complex to follow the program counter's every move in qemu to see if it suddenly ends up on a blessed address and then raise the privileges.

From an emulation standpoint solution number 1 above where we trigger the actual exception by reading or writing to some specific memory is much easier. Would that work with the real hardware, too?

niels-moller, 2024-11-26:
(I thought I posted this comment some weeks ago, but it was just lying around in a browser tab).

Is it hard to make some of the ROM accessible in unprivileged mode? From the app's point of view it would make sense to have a jump table at a fix address (like the current blake2 vector), and call using the same calling conventions as any other functions. I.e., what the app sees is more like the libc syscall stubs that the kernel's syscall interface. Then the code behind that jump table (also in ROM accessible in unprivileged mode) would do whatever syscall magic is needed.

secworks, 2024-11-26:
Hi!

That is one of the possibilities, strategies we have discussed. We expose the Blake2s funnctionality in the FW, and this could be seen as an extension of that.

BR
JoachimS

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

dehanj, 2024-11-26:
> (I thought I posted this comment some weeks ago, but it was just lying around in a browser tab).
>
> Is it hard to make some of the ROM accessible in unprivileged mode? From the app's point of view it would make sense to have a jump table at a fix address (like the current blake2 vector), and call using the same calling conventions as any other functions. I.e., what the app sees is more like the libc syscall stubs that the kernel's syscall interface. Then the code behind that jump table (also in ROM accessible in unprivileged mode) would do whatever syscall magic is needed.

That is more or less what we have in this PR #299.
Here we have added a Syscall API, in the same manner as the Blake2s. ROM is not executable, except for the two addresses where blake2s and the syscall are located. These can be seen as entry points, and once we enter ROM through these functions privileges are increased - and decreased once we are returning and executing outside of ROM again.

mchack-work, 2025-01-21:
#305 is the most promising PR implementing this with PicoRV32 IRQs.

Closed 2025-02-27.

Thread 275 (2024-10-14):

fw: Persistent storage

mchack-work, 2024-10-14:
In Castor we will use the existing flash chip on the PCB for storage of:

- FPGA bitstream for development purposes, not used in locked version.
- Two pre-loaded apps. Two apps because we want to do verified boot with unchanged identity, with the first app verifying the second.
- Storage area for apps.

Original proposal is internal:

https://github.com/tillitis/tillitis/blob/main/docs/tkey_persistent_storage.md

Perhaps make this public?

The firmware needs to change to:

- Start pre-loaded app from flash by default if powercycled.
- Use reset intention data from `FW_RAM` to know what to do: start from flash slot 0, slot 1 or start app from client?
- Add system calls for device apps to access storage.

## Syscalls

1. Retrieve information about if the device app has an allocated
   storage area or not.

2. Allocate or deallocate a storage area. The FW shall return status
   indicating if the allocation was successful or not.

3. Perform read or write operations of data to the allocated storage
   area.

(Cut from investigation report.)

In Castor, slot 0 will be locked to a specific loader app with a specific hash digest in the firmware, to be able to rely on the loader app and it's verification of the next step.

dehanj, 2024-10-31:
Unimplemented features and/or open questions

- USS for a preloaded app.
The preloaded app should be able to use the USS.
The USS then needs to be stored in the partition table, in order for
the pre-loaded app to be able to start up without a user supplying the
USS on every boot. It could also mean an option to enable that a user
has to supply the USS at each boot. This is still an open question.
How do we securely store the USS in flash?

- Auto start of a pre-loaded device app
1) auto-start (unless a cmd comes), 2) Wait for cmd, either start pre-loaded or load another app.
Can be configurable when installing a pre-loaded app.

- App digest from device to client when installing a pre-loaded app

- Management app privileges
How much power should the management app have? In the current PoC it can only register/unregister itself and store/delete a preloaded app. Should it be able to
1) erase arbitrarily storage area?
2) manipulate the partition table?
3) "Factory reset"?
4) Access the entire storage?

Some of these might be useful if someone wants to completely erase the storage or have forgotten the USS to an app that has an allocated area.

- Redundancy of the partition table in flash
Write to alternative pages, if something goes wrong during a write it is possible to restore to the previous and only the "latest" change is lost.

mchack-work, 2025-02-28:
Updated the main issue text since we're now resuming work on this.

The new syscall mechanism #305 has been merged and we will use code from #298 on a new branch to adopt the storage to a new world.

mchack-work, 2025-02-28:
Suggested order of commits:

- Add SPI and flash code.
- Add filesystem parts (partition table)
- Copy code to start app from flash - change state machine to include states to check for resetinfo and loading from flash.
- Add storage syscalls for device app.

mchack-work, 2025-04-04:
Implemented:

- Reset intention handling.
- Start device apps from flash. Two app slots supported.
- Partition table checksum and redundancy.
- Loader app for testing implemented. Chaining to verified blink app works, so a combination of measured boot + verified boot works.
- 4 device app storage areas with 128 k each.
- Syscalls to support all the above.

Closed 2025-05-06.

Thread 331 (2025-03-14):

Standardise reset request in protocol

mchack-work, 2025-03-14:
In Castor device apps are in control of the reset function. They can reset whenever they want. If a *client* wants the TKey to reset they have to request this from the device app.

In order to create interoperability between any combination of client app and any device app that is running I propose we standardise a way of doing a reset protocol request.

The firmware might also support this protocol request and we may want to at least discuss what should happen when it receives such a request.

What kind of reset intentions do we allow a client to do?

We support these:

1. Start from flash slot 1 (default).
2. Load and start an app from flash slot 1 with a specific app hash.
3. Load and start an app from flash slot 2 with a specific app hash.
4. Load and start a new app from client.
5. load and start an app from client with a specific app hash.

mchack-work, 2025-03-14:
Some possible solutions:

- Make it a special treatment of the framing protocol, just like the firmware probe? The firmware probe is a framing header with endpoint 2 (firmware) and all well-behaved apps answer back NOK.
- Add something to the reserved bits in the framing protocol?
- Use something in the app level protocols? Framing header with endpoint either 2 (fw) or 3 (dev app) + RESET_CODE and reserve the reset codes not to be used for anything else.

mchack-work, 2025-09-08:
During a reset flow discussion today it was decided that we want to support client reset -> start loader with verified boot on app slot 0 -> device app from client.

This means we need to support some additional data in a client reset request, at least:

1. Start from app slot 0.
2. Digest of device app from client.
3. Signature over this digest.

All this data must be left by the running device app for the loader to use.

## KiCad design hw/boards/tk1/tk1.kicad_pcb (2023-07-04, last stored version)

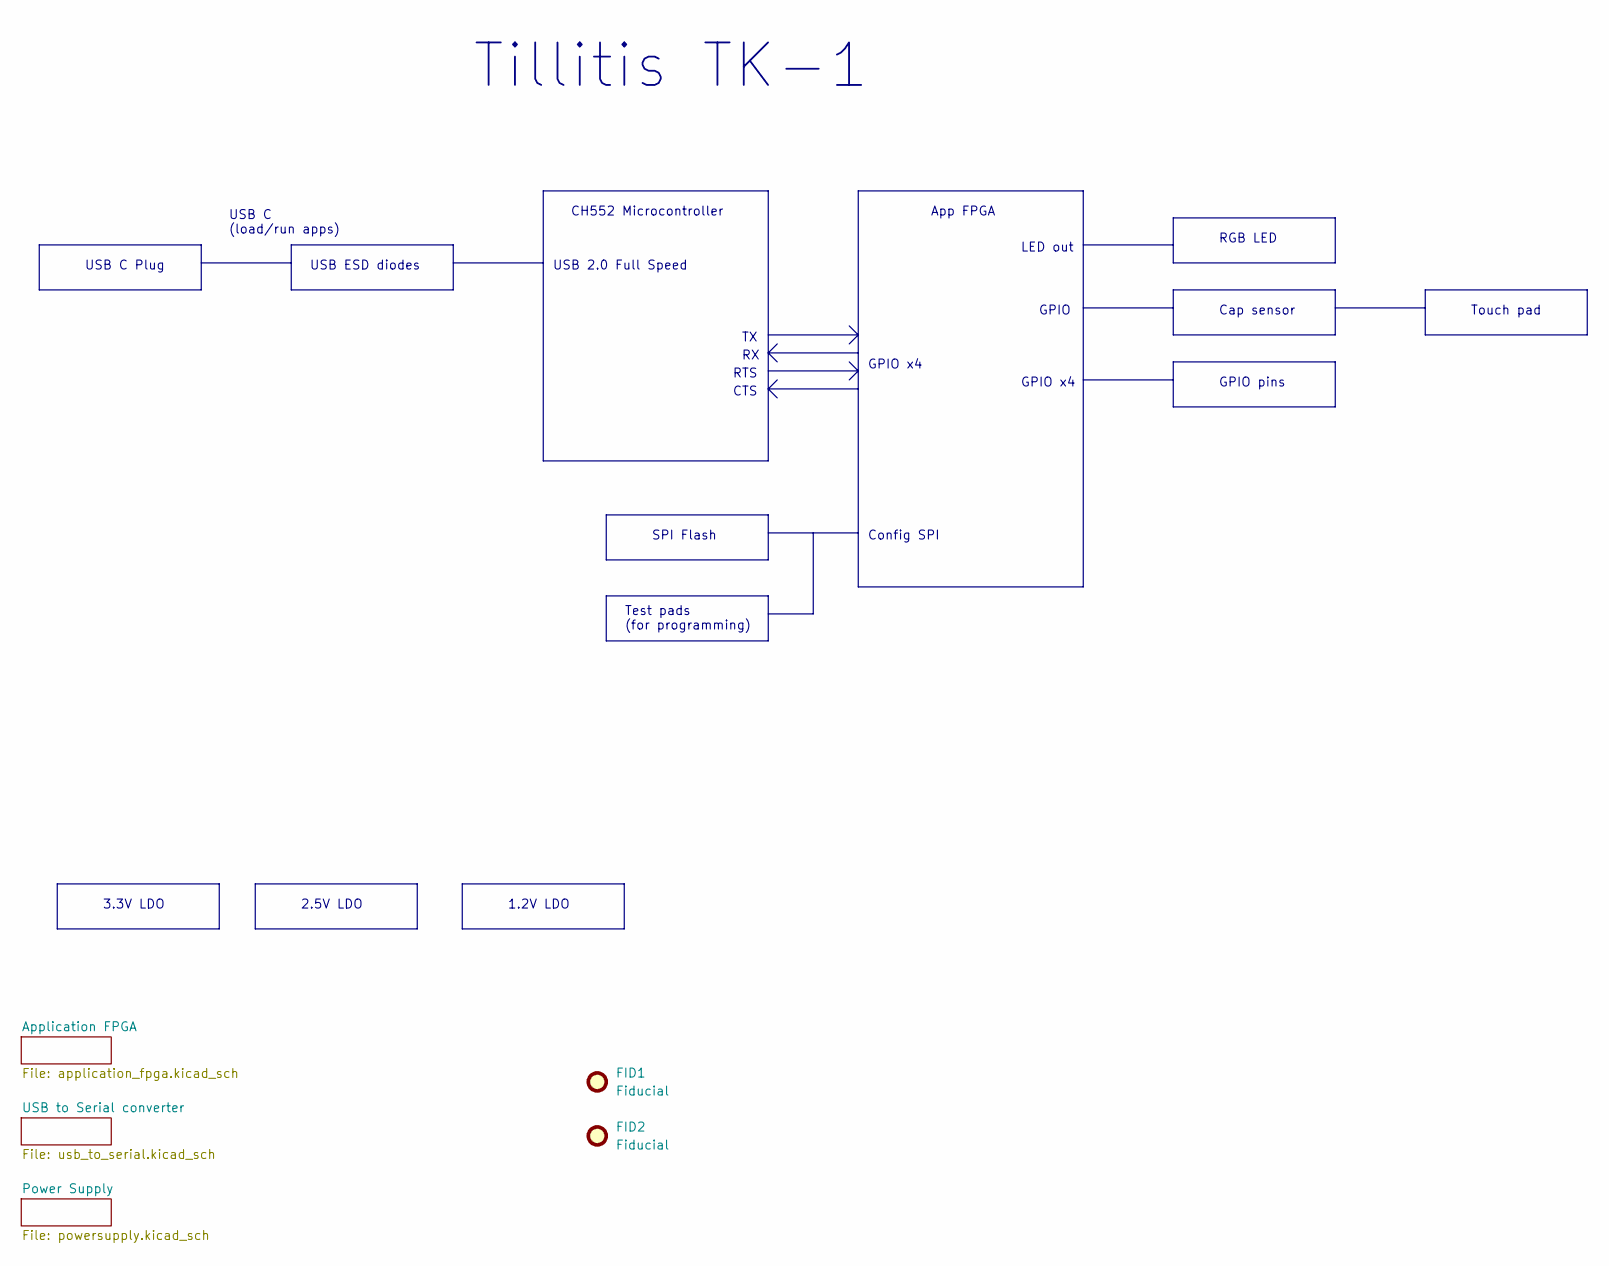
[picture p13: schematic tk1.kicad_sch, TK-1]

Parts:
FID1, FID2: Fiducial; Fiducial_0.75mm_Mask1.5mm

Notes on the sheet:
USB ESD diodes
Touch pad
GPIO x4
GPIO pins
Cap sensor
USB 2.0 Full Speed
RTS
USB C Plug
CH552 Microcontroller
RGB LED
USB C (load/run apps)
1.2V LDO
3.3V LDO
CTS
2.5V LDO
App FPGA
Config SPI
Tillitis TK-1
SPI Flash
GPIO
LED out
Test pads (for programming)

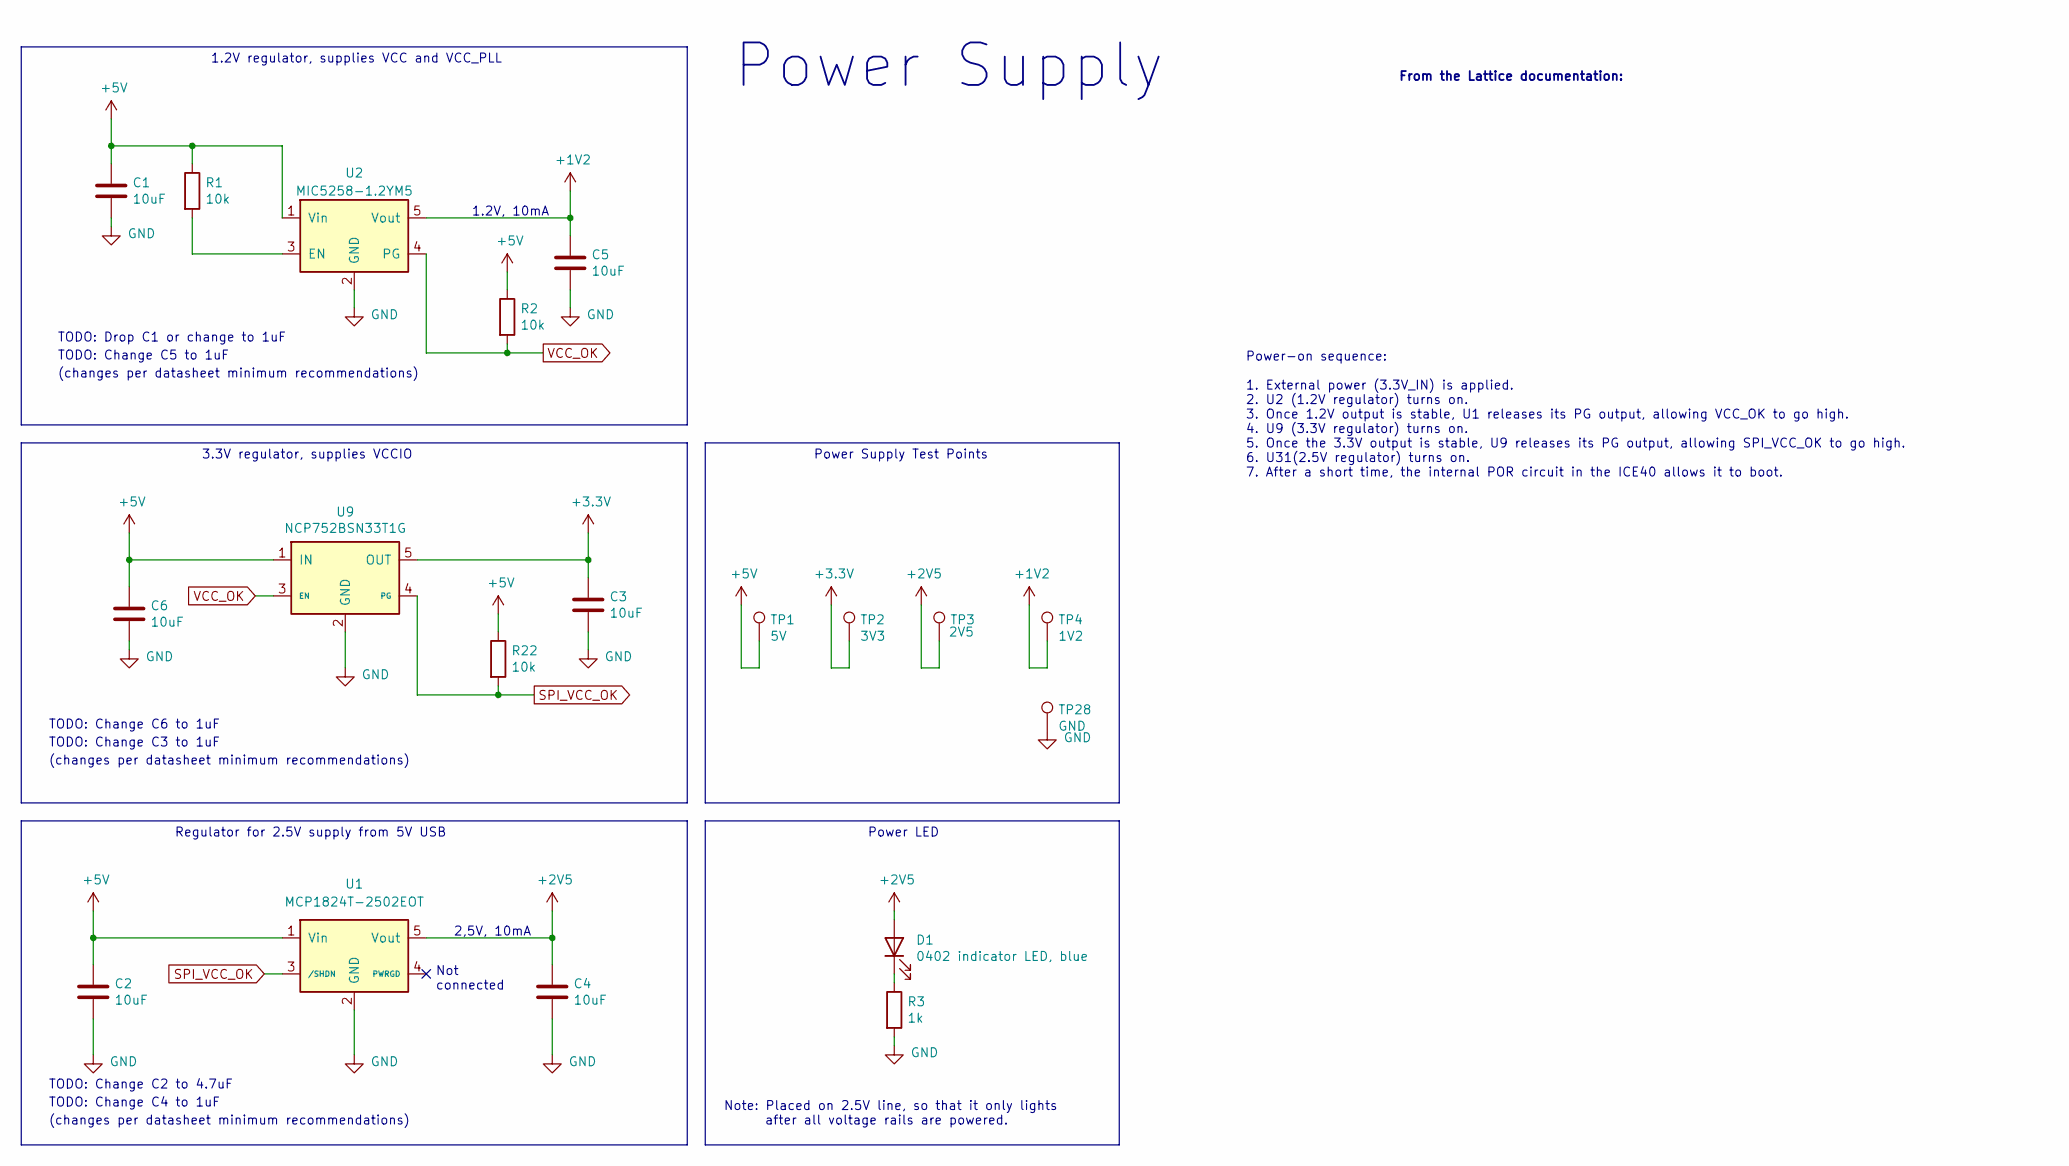
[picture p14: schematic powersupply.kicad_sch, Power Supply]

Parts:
C1, C2, C3, C4, C5, C6: 10uF; CAPC1608X09L
D1: 0402 indicator LED, blue; LED_0402_1005Metric; Manufacturer Part Number NCD0402B1
R1, R2, R22: 10k; ERJ2G(0402)_L
R3: 1k; ERJ2G(0402)_L
TP1: 5V; TestPoint_Pad_D1.0mm
TP2: 3V3; TestPoint_Pad_D1.0mm
TP3: 2V5; TestPoint_Pad_D1.0mm
TP4: 1V2; TestPoint_Pad_D1.0mm
TP28: GND; TestPoint_Pad_D1.0mm
U1: MCP1824T-2502EOT; SOT-23-5; Manufacturer Part Number MCP1824T-2502EOT
U2: MIC5258-1.2YM5; SOT-23-5; Manufacturer Part Number MIC5258-1.2YM5
U9: NCP752BSN33T1G; Manufacturer Part Number NCP752BSN33T1G

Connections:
+1V2: C5.1, TP4.1, U2.5 (Vout); also elsewhere on the board
+2V5: C4.1, D1.2 (A), TP3.1, U1.5 (Vout); also elsewhere on the board
+3V3: C3.1, TP2.1, U9.5 (OUT); also elsewhere on the board
+5V: C1.1, C2.1, C6.1, R1.1, R2.1, R22.1, TP1.1, U1.1 (Vin), U2.1 (Vin), U9.1 (IN); also elsewhere on the board
GND: C1.2, C2.2, C3.2, C4.2, C5.2, C6.2, R3.2, TP28.1, U1.2 (GND), U2.2 (GND), U9.2 (GND); also elsewhere on the board
unnamed: D1.1 (K), R3.1
unnamed: R1.2, U2.3 (EN)
SPI_VCC_OK: R22.2, U1.3 (/SHDN), U9.4 (PG)
VCC_OK: R2.2, U2.4 (PG), U9.3 (EN)

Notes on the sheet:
Power-on sequence: 1. External power (3.3V_IN) is applied. 2. U2 (1.2V regulator) turns on. 3. Once 1.2V output is stable, U1 releases its PG output, allowing VCC_OK to go high. 4. U9 (3.3V regulator) turns on. 5. Once the 3.3V output is stable, U9 releases its PG output, allowing SPI_VCC_OK to go 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
TODO: Change C2 to 4.7uF
(changes per datasheet minimum recommendations)
TODO: Change C6 to 1uF
2,5V, 10mA
Note: Placed on 2.5V line, so that it only lights after all voltage rails are powered.
TODO: Change C3 to 1uF
1.2V, 10mA
Power Supply
TODO: Drop C1 or change to 1uF
TODO: Change C5 to 1uF
From the Lattice documentation:
1.2V regulator, supplies VCC and VCC_PLL
3.3V regulator, supplies VCCIO
TODO: Change C4 to 1uF
Not connected
Power Supply Test Points
Power LED
Regulator for 2.5V supply from 5V USB

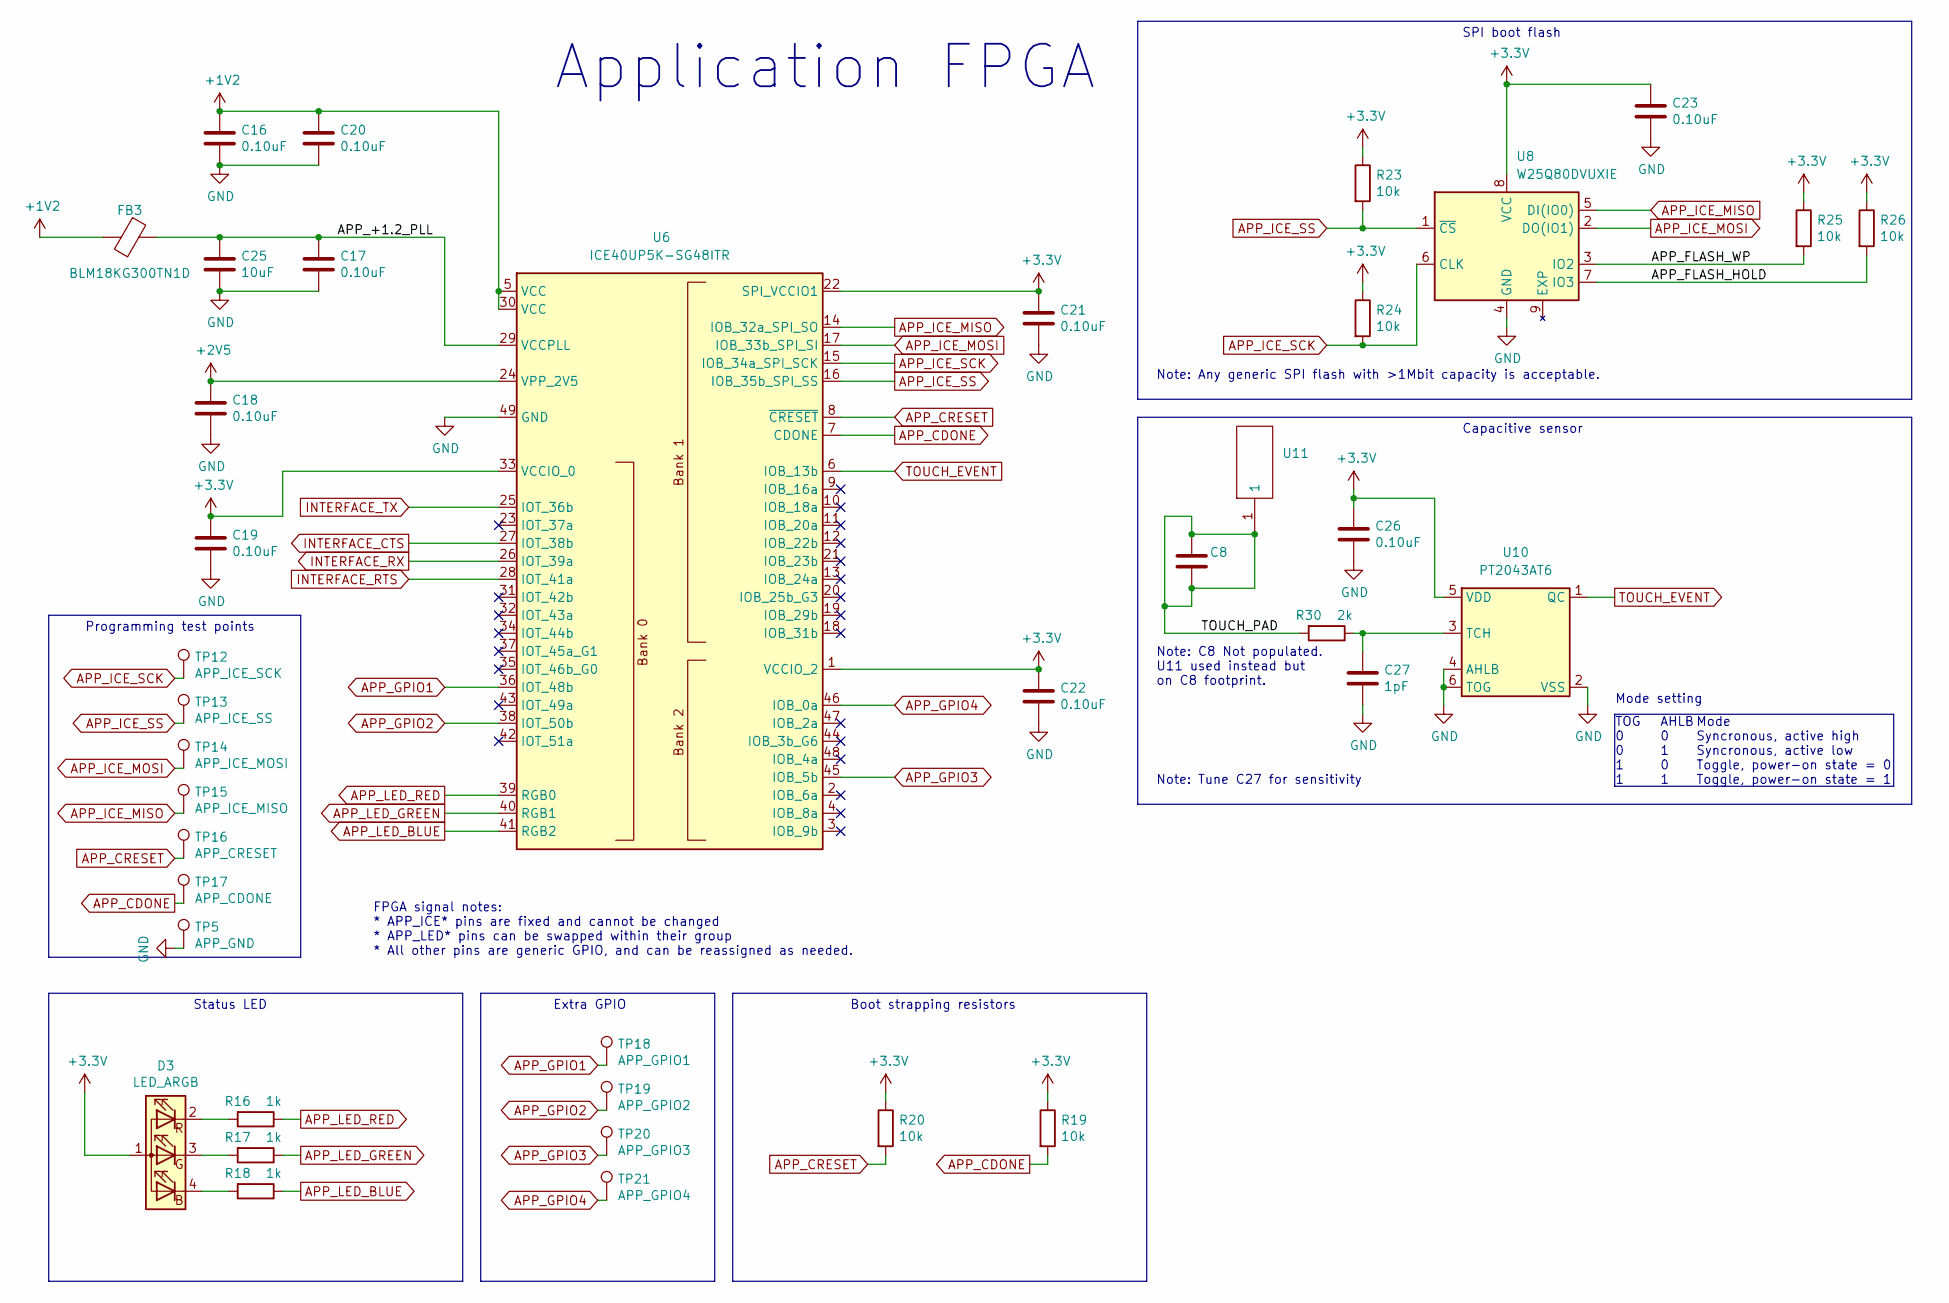
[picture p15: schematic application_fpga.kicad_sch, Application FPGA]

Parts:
C8: Manufacturer Part Number C3216X7R1H105K160AE
C16, C17, C18, C19, C20, C21, C22, C23, C26: 0.10uF; CAPC1005X06L
C25: 10uF; CAPC1608X09L
C27: 1pF; CAPC1005X06L
D3: LED_ARGB; 0402rgb-1010; Manufacturer Part Number FC-B1010RGBT-HG
FB3: BLM18KG300TN1D; Ferritbead_0603_1608Metric; Manufacturer Part Number BLM18KG300TN1D
R16, R17, R18: 1k; ERJ2G(0402)_L
R19, R20, R23, R24, R25, R26: 10k; ERJ2G(0402)_L
R30: 2k; ERJ2G(0402)_L
TP5: APP_GND; TestPoint_Pad_D1.0mm
TP12: APP_ICE_SCK; TestPoint_Pad_D1.0mm
TP13: APP_ICE_SS; TestPoint_Pad_D1.0mm
TP14: APP_ICE_MOSI; TestPoint_Pad_D1.0mm
TP15: APP_ICE_MISO; TestPoint_Pad_D1.0mm
TP16: APP_CRESET; TestPoint_Pad_D1.0mm
TP17: APP_CDONE; TestPoint_Pad_D1.0mm
TP18: APP_GPIO1; TestPoint_Pad_D1.0mm
TP19: APP_GPIO2; TestPoint_Pad_D1.0mm
TP20: APP_GPIO3; TestPoint_Pad_D1.0mm
TP21: APP_GPIO4; TestPoint_Pad_D1.0mm
U6: ICE40UP5K-SG48ITR; QFN-48-1EP_7x7mm_P0.5mm_EP5.6x5.6mm; Manufacturer Part Number ICE40UP5K-SG48ITR
U8: W25Q80DVUXIE; Manufacturer Part Number W25Q80DVUXIE
U10: PT2043AT6; SOT-23-6; Manufacturer Part Number PT2043AT6
U11: Mouser Part Number 571-1674954-1

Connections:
+1V2: C16.1, C20.1, FB3.2, U6.5 (VCC), U6.30 (VCC); also elsewhere on the board
+2V5: C18.1, U6.24 (VPP_2V5); also elsewhere on the board
+3V3: C19.1, C21.1, C22.1, C23.1, C26.1, D3.1 (A), R19.1, R20.1, R23.1, R24.1, R25.1, R26.1, U6.1 (VCCIO_2), U6.22 (SPI_VCCIO1), U6.33 (VCCIO_0), U8.8 (VCC), U10.5 (VDD); also elsewhere on the board
/Application FPGA/APP_+1.2_PLL: C17.1, C25.1, FB3.1, U6.29 (VCCPLL)
/Application FPGA/APP_FLASH_HOLD: R26.2, U8.7 (IO3)
/Application FPGA/APP_FLASH_WP: R25.2, U8.3 (IO2)
/Application FPGA/TOUCH_PAD: C8.1, C8.2, R30.2, U11.1
APP_CDONE: R19.2, TP17.1, U6.7 (CDONE)
APP_CRESET: R20.2, TP16.1, U6.8 (~CRESET)
APP_GPIO1: TP18.1, U6.36 (IOT_48b)
APP_GPIO2: TP19.1, U6.38 (IOT_50b)
APP_GPIO3: TP20.1, U6.45 (IOB_5b)
APP_GPIO4: TP21.1, U6.46 (IOB_0a)
APP_ICE_MISO: TP15.1, U6.14 (IOB_32a_SPI_SO), U8.5 (DI(IO0))
APP_ICE_MOSI: TP14.1, U6.17 (IOB_33b_SPI_SI), U8.2 (DO(IO1))
APP_ICE_SCK: R24.2, TP12.1, U6.15 (IOB_34a_SPI_SCK), U8.6 (CLK)
APP_ICE_SS: R23.2, TP13.1, U6.16 (IOB_35b_SPI_SS), U8.1 (~CS)
APP_LED_BLUE: R18.1, U6.41 (RGB2)
APP_LED_GREEN: R17.1, U6.40 (RGB1)
APP_LED_RED: R16.1, U6.39 (RGB0)
GND: C16.2, C17.2, C18.2, C19.2, C20.2, C21.2, C22.2, C23.2, C25.2, C26.2, C27.2, TP5.1, U6.49 (GND), U8.4 (GND), U10.2 (VSS), U10.4 (AHLB), U10.6 (TOG); also elsewhere on the board
INTERFACE_CTS: U6.27 (IOT_38b); also elsewhere on the board
INTERFACE_RTS: U6.28 (IOT_41a); also elsewhere on the board
INTERFACE_RX: U6.26 (IOT_39a); also elsewhere on the board
INTERFACE_TX: U6.25 (IOT_36b); also elsewhere on the board
unnamed: C27.1, R30.1, U10.3 (TCH)
unnamed: D3.2 (RK), R16.2
unnamed: D3.3 (GK), R17.2
unnamed: D3.4 (BK), R18.2
TOUCH_EVENT: U6.6 (IOB_13b), U10.1 (QC)

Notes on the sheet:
Application FPGA
Mode Syncronous, active high Syncronous, active low Toggle, power-on state = 0 Toggle, power-on state = 1
Capacitive sensor
SPI boot flash
FPGA signal notes: * APP_ICE* pins are fixed and cannot be changed * APP_LED* pins can be swapped within their group * All other pins are generic GPIO, and can be reassigned as needed.
Boot strapping resistors
AHLB 0 1 0 1
Status LED
Note: Tune C27 for sensitivity
Programming test points
Note: C8 Not populated. U11 used instead but on C8 footprint.
Mode setting
Note: Any generic SPI flash with >1Mbit capacity is acceptable.
Extra GPIO
TOG 0 0 1 1

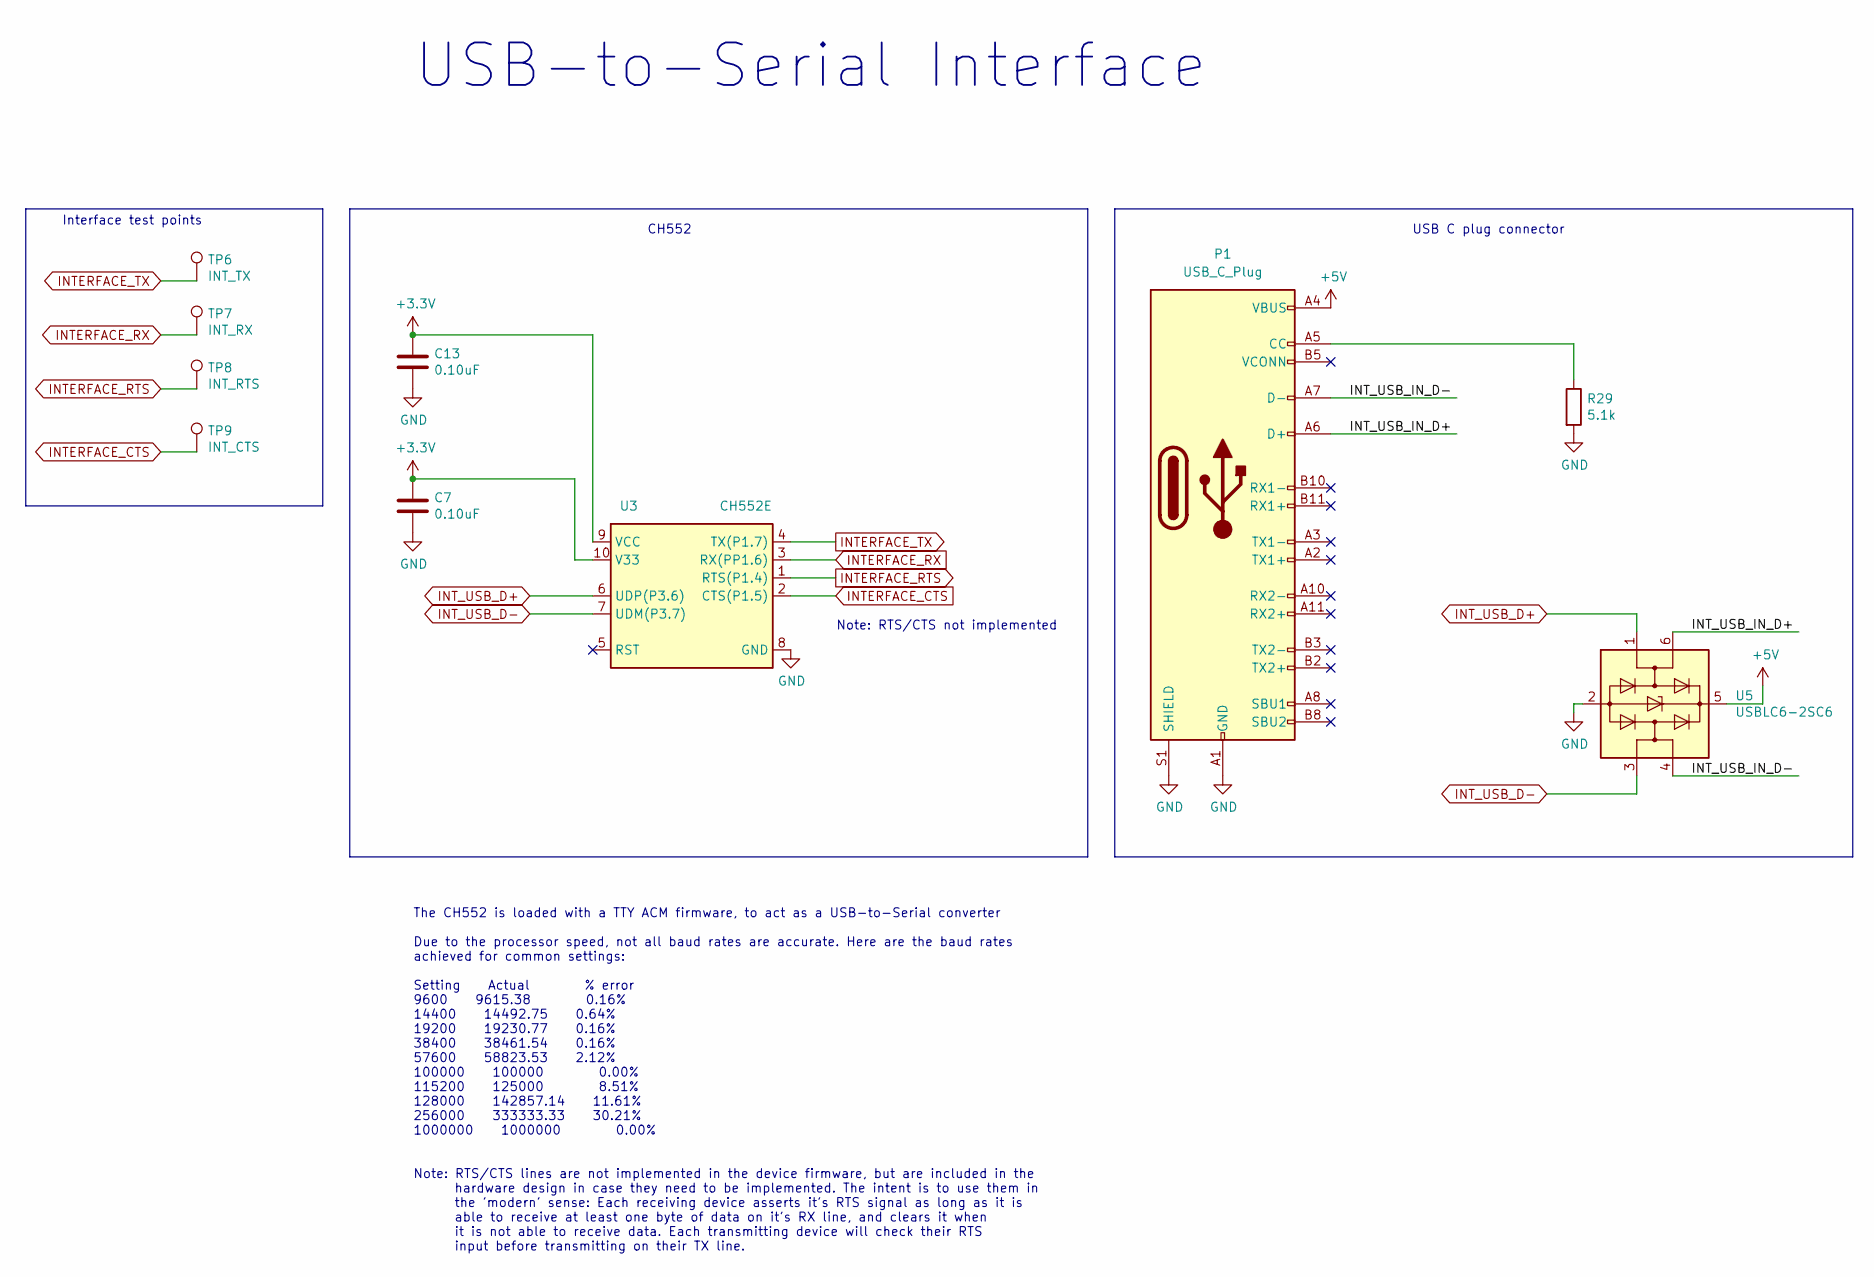
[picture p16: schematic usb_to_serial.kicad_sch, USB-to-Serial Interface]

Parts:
C7, C13: 0.10uF; CAPC1005X06L
P1: USB_C_Plug; U261-241N-4BS60; Manufacturer Part Number U261-241N-4BS60
R29: 5.1k; ERJ2G(0402)_L
TP6: INT_TX; TestPoint_Pad_D1.0mm
TP7: INT_RX; TestPoint_Pad_D1.0mm
TP8: INT_RTS; TestPoint_Pad_D1.0mm
TP9: INT_CTS; TestPoint_Pad_D1.0mm
U3: CH552E; MSOP-10_3x3mm_P0.5mm; Manufacturer Part Number CH552E
U5: USBLC6-2SC6; SOT-23-6; Manufacturer Part Number USBLC6-2SC6

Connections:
+3V3: C7.1, C13.1, U3.9 (VCC), U3.10 (V33); also elsewhere on the board
+5V: P1.A4 (VBUS), P1.A9 (VBUS), P1.B4 (VBUS), P1.B9 (VBUS), U5.5 (VBUS); also elsewhere on the board
/USB to Serial converter/INT_USB_IN_D+: P1.A6 (D+), U5.6 (I/O1)
/USB to Serial converter/INT_USB_IN_D-: P1.A7 (D-), U5.4 (I/O2)
GND: C7.2, C13.2, P1.A1 (GND), P1.A12 (GND), P1.B1 (GND), P1.B12 (GND), P1.S1 (SHIELD), R29.2, U3.8 (GND), U5.2 (GND); also elsewhere on the board
INTERFACE_CTS: TP9.1, U3.2 (CTS(P1.5)); also elsewhere on the board
INTERFACE_RTS: TP8.1, U3.1 (RTS(P1.4)); also elsewhere on the board
INTERFACE_RX: TP7.1, U3.3 (RX(PP1.6)); also elsewhere on the board
INTERFACE_TX: TP6.1, U3.4 (TX(P1.7)); also elsewhere on the board
INT_USB_D+: U3.6 (UDP(P3.6)), U5.1 (I/O1)
INT_USB_D-: U3.7 (UDM(P3.7)), U5.3 (I/O2)
unnamed: P1.A5 (CC), R29.1

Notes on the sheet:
USB C plug connector
CH552
USB-to-Serial Interface
The CH552 is loaded with a TTY ACM firmware, to act as a USB-to-Serial converter Due to the processor speed, not all baud rates are accurate. Here are the baud rates achieved for common settings: Setting Actual % error 9600 9615.38 0.16% 14400 14492.75 0.64% 19200 19230.77 0.16% 38400 38461.54 0.16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
Interface test points
Note: RTS/CTS not implemented

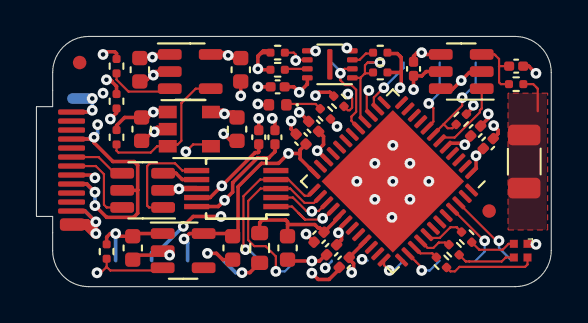
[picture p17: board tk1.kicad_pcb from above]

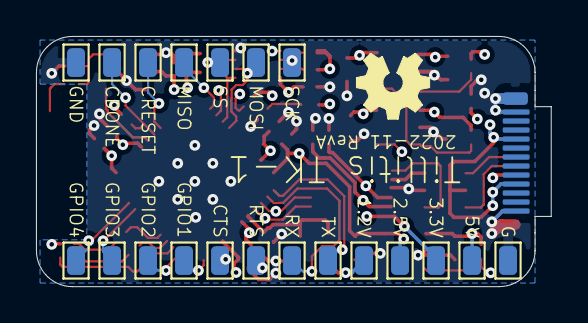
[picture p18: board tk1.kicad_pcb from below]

Board: 4 copper layers, 28.6 x 13.9 mm, 69 parts (20 on the bottom side), 40 nets.

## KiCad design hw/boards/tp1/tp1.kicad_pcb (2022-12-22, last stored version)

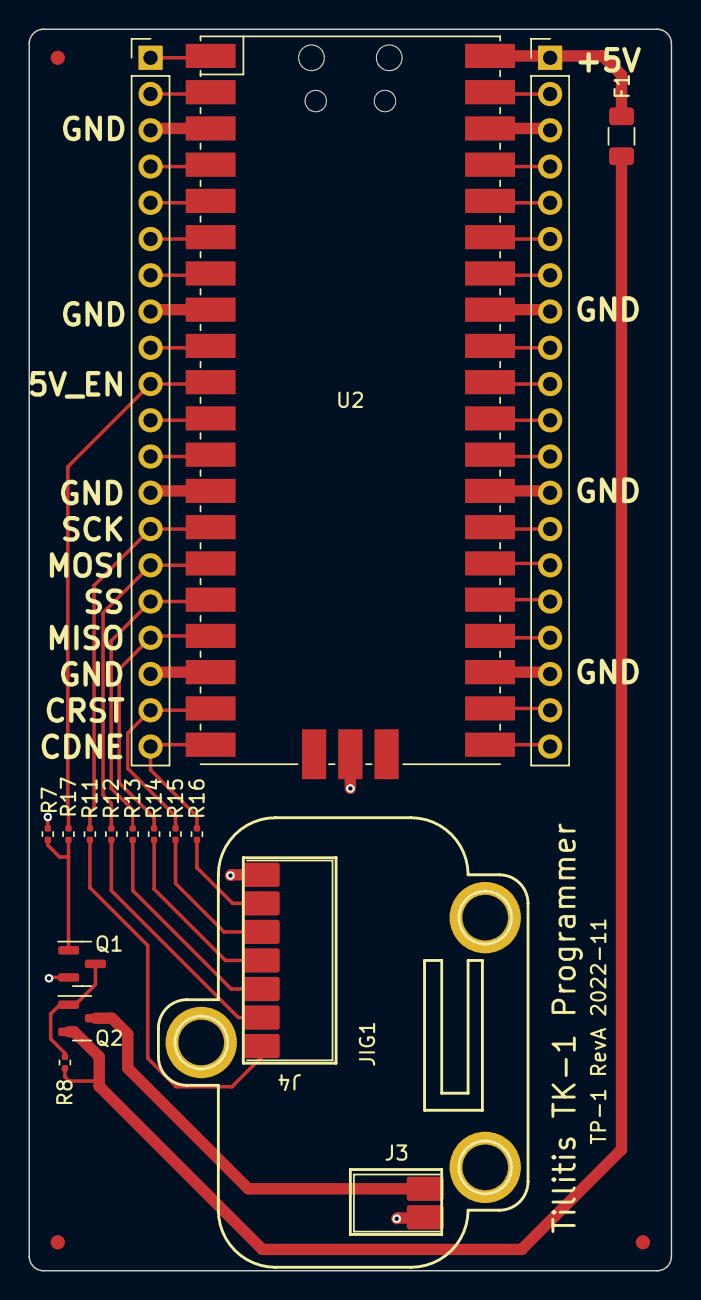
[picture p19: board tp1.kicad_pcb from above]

Board: 2 copper layers, 45.0 x 87.0 mm, 21 parts (0 on the bottom side), 43 nets.

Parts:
F1: 50mA; Fuse_1206_3216Metric
FID1, FID2: Fiducial; Fiducial_1mm_Mask2mm
FIDe: Fiducial; Fiducial_1mm_Mask2mm
J1, J2: Conn_01x20; PinHeader_1x20_P2.54mm_Vertical
J3: BC-1-208
J4: BC-1-701
JIG1: mta1_usb_ch552_flat
Q1: AO3400A; SOT-23
Q2: AO3401A; SOT-23
R7, R8: 10K; ERJ2G(0402)_L
R11, R12, R13, R14, R15, R16, R17: 100R; ERJ2G(0402)_L
U2: Pico; RPi_Pico_SMD_reflow

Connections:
+5V: F1.1, J2.1, U2.40 (VBUS)
/5V_DUT: J3.1, Q2.3 (D)
/5V_EN: J1.10, R17.1, U2.10 (GPIO7)
/5V_FUSE: F1.2, Q2.2 (S), R8.2
/CDONE: J4.6, R16.1
/CDONE_U: J1.20, R16.2, U2.20 (GPIO15)
/CRESET: J4.5, R15.1
/CRESET_U: J1.19, R15.2, U2.19 (GPIO14)
/CTS_U: J2.19, U2.22 (GPIO17)
/GPIO1_U: J2.17, U2.24 (GPIO18)
/GPIO2_U: J2.16, U2.25 (GPIO19)
/GPIO3_U: J2.15, U2.26 (GPIO20)
/GPIO4_U: J2.14, U2.27 (GPIO21)
/MISO: J4.4, R14.1
/MISO_U: J1.17, R14.2, U2.17 (GPIO13)
/MOSI: J4.2, R12.1
/MOSI_U: J1.15, R12.2, U2.15 (GPIO11)
/PICO22: J2.12, U2.29 (GPIO22)
/PICO26: J2.10, U2.31 (GPIO26_ADC0)
/PICO27: J2.9, U2.32 (GPIO27_ADC1)
/PICO28: J2.7, U2.34 (GPIO28_ADC2)
/PICO_0: J1.1, U2.1 (GPIO0)
/PICO_1: J1.2, U2.2 (GPIO1)
/PICO_2: J1.4, U2.4 (GPIO2)
/PICO_3: J1.5, U2.5 (GPIO3)
/PICO_3V3: J2.5, U2.36 (3V3)
/PICO_3V3_EN: J2.4, U2.37 (3V3_EN)
/PICO_4: J1.6, U2.6 (GPIO4)
/PICO_5: J1.7, U2.7 (GPIO5)
/PICO_6: J1.9, U2.9 (GPIO6)
/PICO_ADC_VREF: J2.6, U2.35 (ADC_VREF)
/PICO_RUN: J2.11, U2.30 (RUN)
/PICO_VSYS: J2.2, U2.39 (VSYS)
/RTS_U: J2.20, U2.21 (GPIO16)
/RX_U: J1.12, U2.12 (GPIO9)
/SCK: J4.1, R11.1
/SCK_U: J1.14, R11.2, U2.14 (GPIO10)
/SS: J4.3, R13.1
/SS_U: J1.16, R13.2, U2.16 (GPIO12)
/TX_U: J1.11, U2.11 (GPIO8)
GND: J1.3, J1.8, J1.13, J1.18, J2.3, J2.8, J2.13, J2.18, J3.2, J4.7, Q1.2 (S), R7.1, U2.3 (GND), U2.8 (GND), U2.13 (GND), U2.18 (GND), U2.23 (GND), U2.28 (GND), U2.33 (AGND), U2.38 (GND), U2.42 (GND)
unnamed: Q1.1 (G), R7.2, R17.2
unnamed: Q1.3 (D), Q2.1 (G), R8.1

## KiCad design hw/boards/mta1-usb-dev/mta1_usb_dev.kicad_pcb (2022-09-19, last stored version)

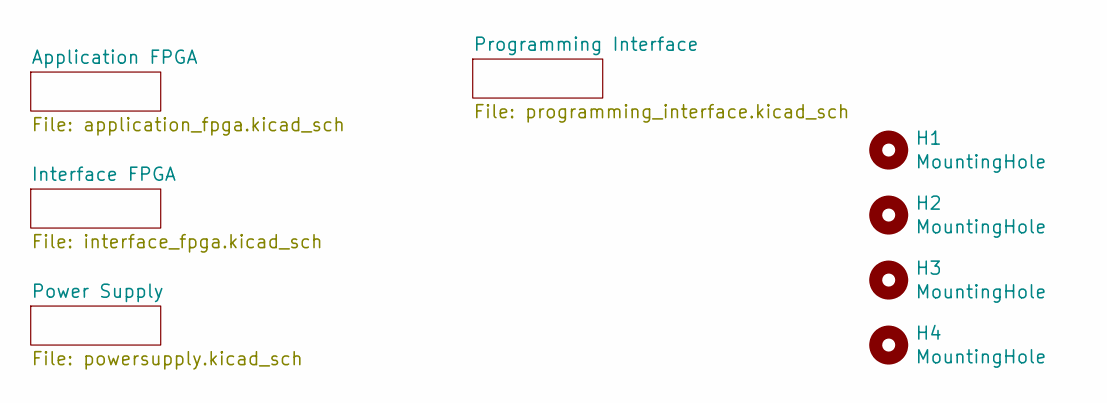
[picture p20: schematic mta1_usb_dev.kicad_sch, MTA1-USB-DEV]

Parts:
H1, H2, H3, H4: MountingHole; MountingHole_3.2mm_M3_DIN965_Pad_TopBottom

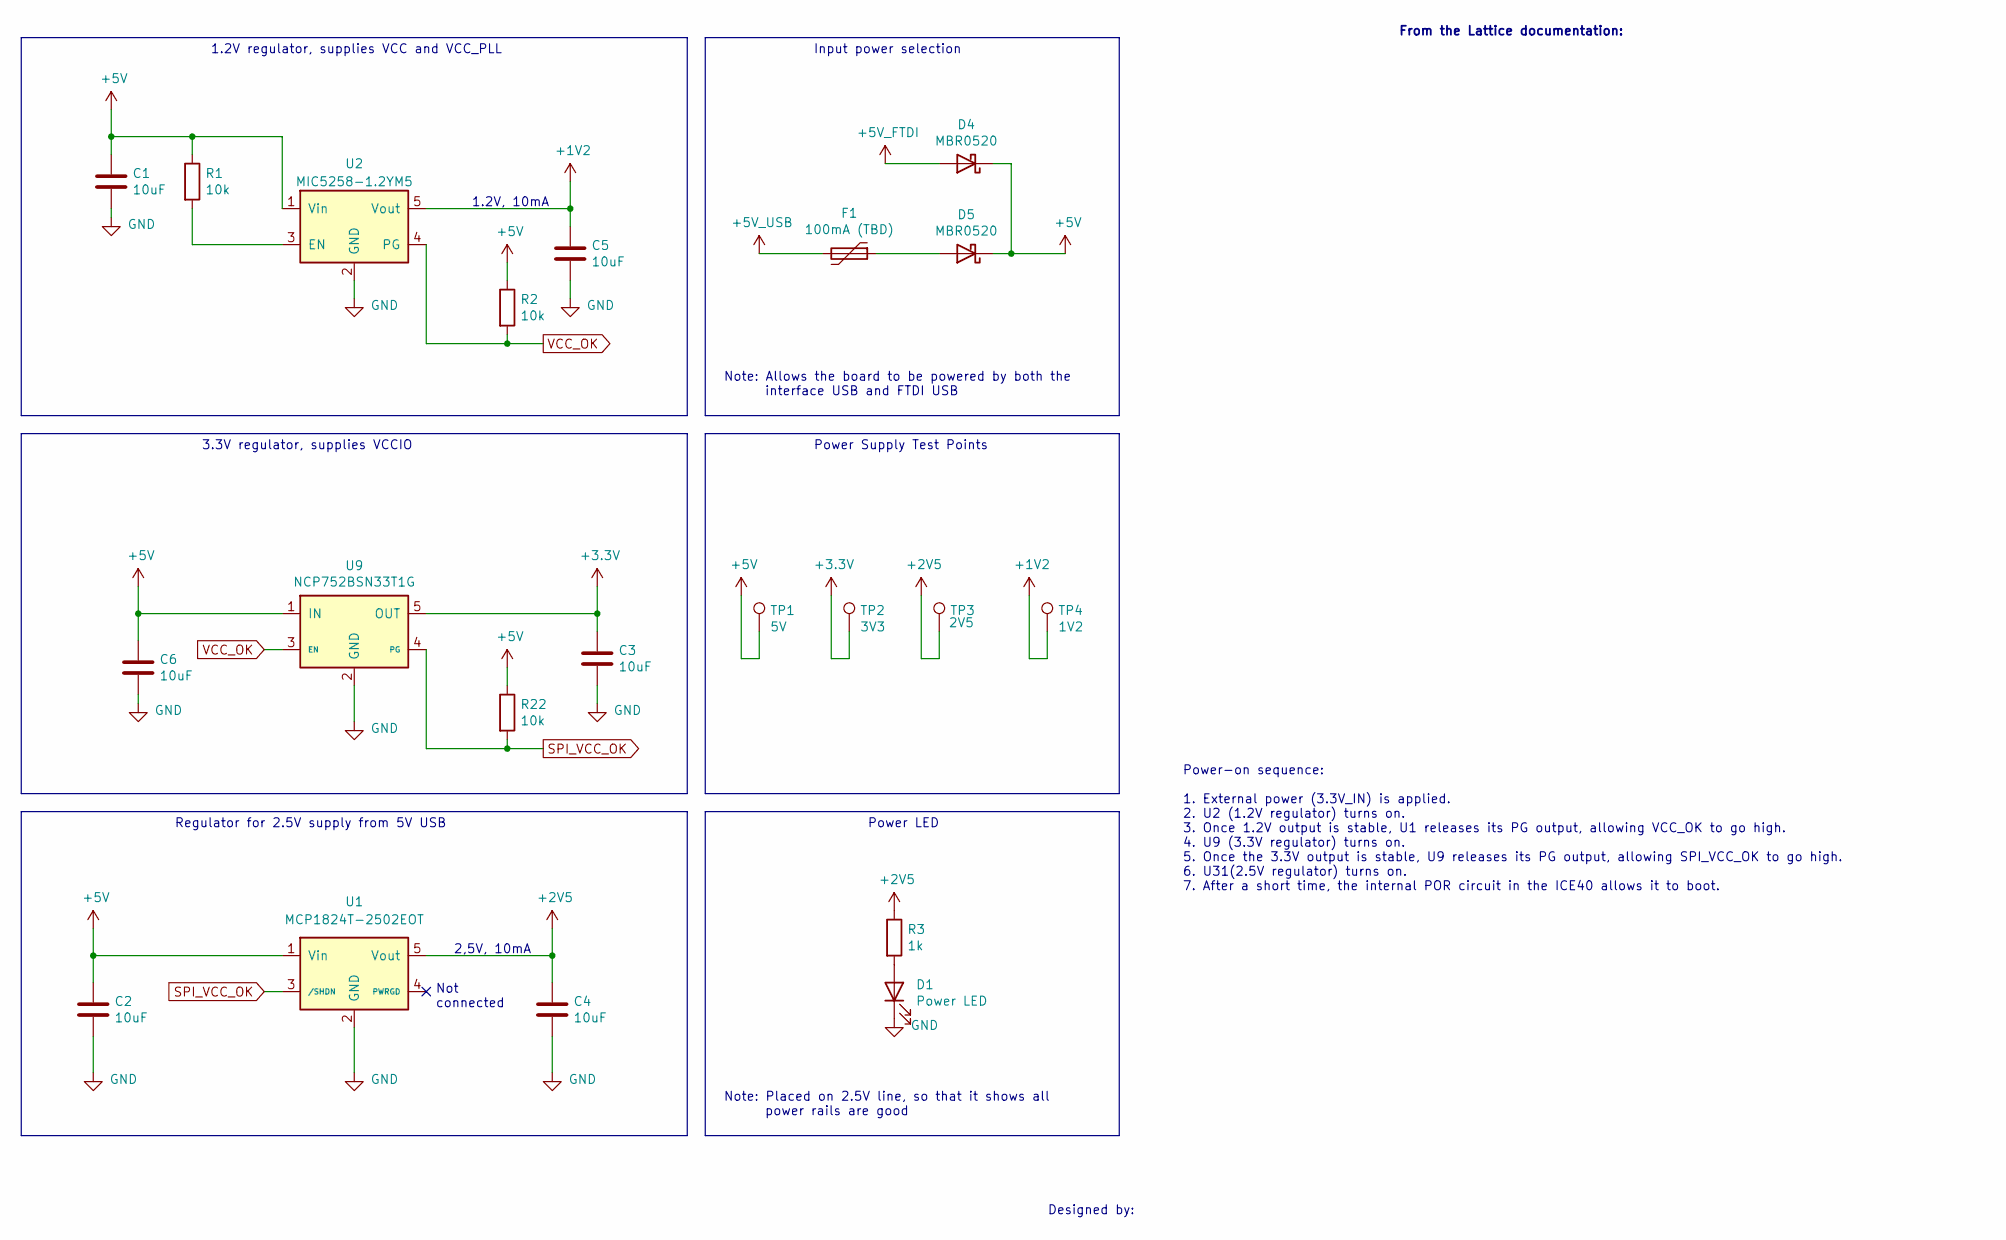
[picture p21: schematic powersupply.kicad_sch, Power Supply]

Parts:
C1, C2, C3, C4, C5, C6: 10uF; CAPC1608X09L
D1: Power LED; LED_0402_1005Metric
D4, D5: MBR0520; D_SOD-123
F1: 100mA (TBD); Fuse_1206_3216Metric
R1, R2, R22: 10k; ERJ2G(0402)_L
R3: 1k; ERJ2G(0402)_L
TP1: 5V; TestPoint_Pad_D1.0mm
TP2: 3V3; TestPoint_Pad_D1.0mm
TP3: 2V5; TestPoint_Pad_D1.0mm
TP4: 1V2; TestPoint_Pad_D1.0mm
U1: MCP1824T-2502EOT; SOT-23-5
U2: MIC5258-1.2YM5; SOT-23-5
U9: NCP752BSN33T1G

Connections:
+1V2: C5.1, TP4.1, U2.5 (Vout); also elsewhere on the board
+2V5: C4.1, R3.1, TP3.1, U1.5 (Vout); also elsewhere on the board
+3V3: C3.1, TP2.1, U9.5 (OUT); also elsewhere on the board
+5V: C1.1, C2.1, C6.1, D4.1 (K), D5.1 (K), R1.1, R2.1, R22.1, TP1.1, U1.1 (Vin), U2.1 (Vin), U9.1 (IN)
+5V_FTDI: D4.2 (A); also elsewhere on the board
+5V_USB: F1.2; also elsewhere on the board
GND: C1.2, C2.2, C3.2, C4.2, C5.2, C6.2, D1.1 (K), U1.2 (GND), U2.2 (GND), U9.2 (GND); also elsewhere on the board
unnamed: D1.2 (A), R3.2
unnamed: D5.2 (A), F1.1
unnamed: R1.2, U2.3 (EN)
SPI_VCC_OK: R22.2, U1.3 (/SHDN), U9.4 (PG)
VCC_OK: R2.2, U2.4 (PG), U9.3 (EN)

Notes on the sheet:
Power-on sequence: 1. External power (3.3V_IN) is applied. 2. U2 (1.2V regulator) turns on. 3. Once 1.2V output is stable, U1 releases its PG output, allowing VCC_OK to go high. 4. U9 (3.3V regulator) turns on. 5. Once the 3.3V output is stable, U9 releases its PG output, allowing SPI_VCC_OK to go 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
Note: Allows the board to be powered by both the interface USB and FTDI USB
2,5V, 10mA
Note: Placed on 2.5V line, so that it shows all power rails are good
Designed by:
Input power selection
1.2V, 10mA
From the Lattice documentation:
1.2V regulator, supplies VCC and VCC_PLL
3.3V regulator, supplies VCCIO
Not connected
Power Supply Test Points
Power LED
Regulator for 2.5V supply from 5V USB

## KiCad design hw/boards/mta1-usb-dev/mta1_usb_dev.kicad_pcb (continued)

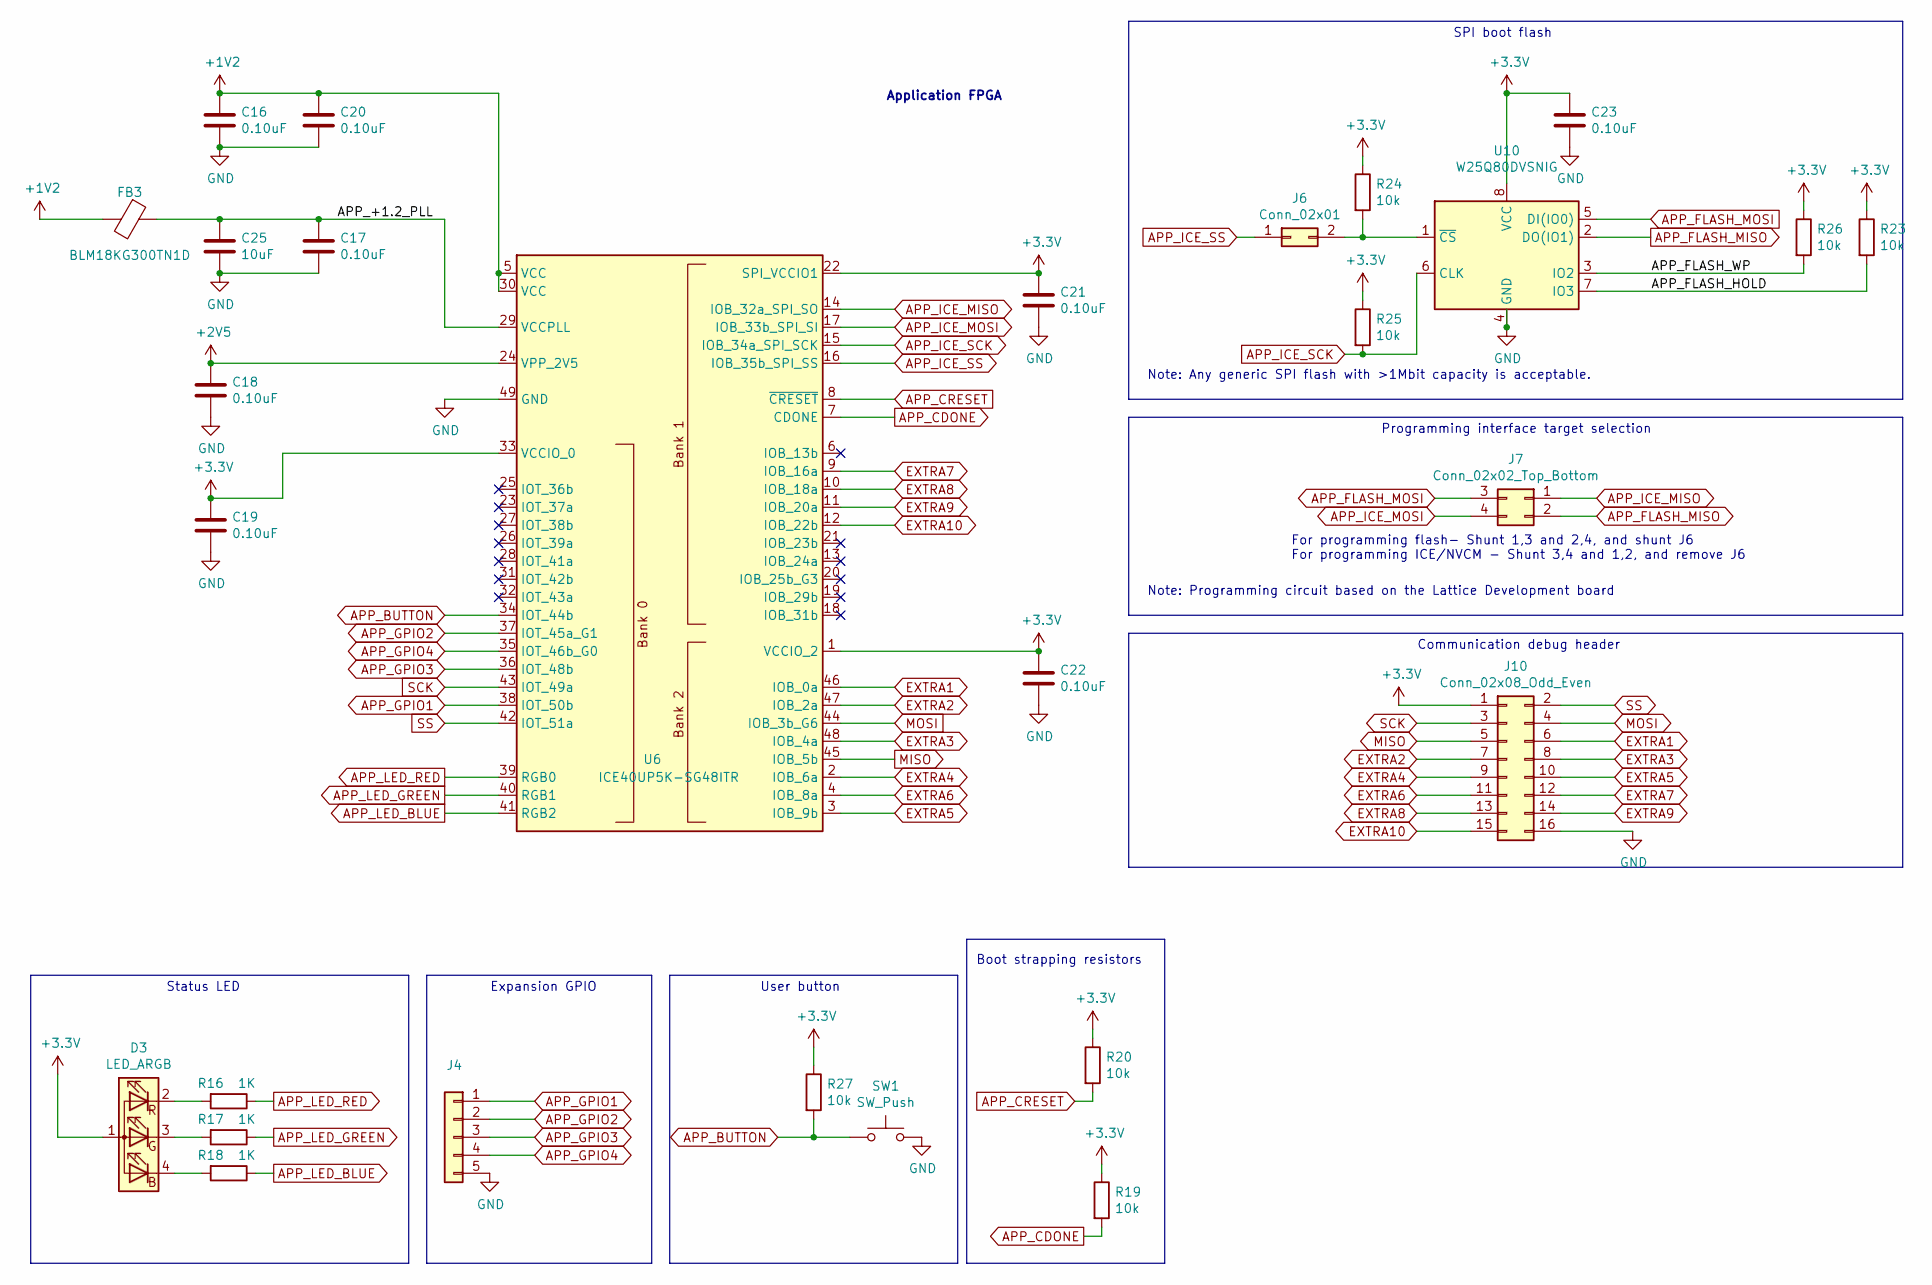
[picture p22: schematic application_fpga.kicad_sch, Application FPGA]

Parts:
C16, C17, C18, C19, C20, C21, C22, C23: 0.10uF; CAPC1005X06L
C25: 10uF; CAPC1608X09L
D3: LED_ARGB; 0402rgb-1010
FB3: BLM18KG300TN1D; Ferritbead_0603_1608Metric
J4: PinHeader_1x05_P2.54mm_Vertical
J6: Conn_02x01; PinHeader_1x02_P2.54mm_Vertical
J7: Conn_02x02_Top_Bottom; PinHeader_2x02_P2.54mm_Vertical
J10: Conn_02x08_Odd_Even; PinHeader_2x08_P2.54mm_Vertical
R16, R17, R18: 1K; ERJ2G(0402)_L
R19, R20, R23, R24, R25, R26, R27: 10k; ERJ2G(0402)_L
SW1: SW_Push; SW_Push_SPST_NO_Alps_SKRK
U6: ICE40UP5K-SG48ITR; QFN-48-1EP_7x7mm_P0.5mm_EP5.6x5.6mm
U10: W25Q80DVSNIG; SOIC-8_3.9x4.9mm_P1.27mm

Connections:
+1V2: C16.1, C20.1, FB3.2, U6.5 (VCC), U6.30 (VCC); also elsewhere on the board
+2V5: C18.1, U6.24 (VPP_2V5); also elsewhere on the board
+3V3: C19.1, C21.1, C22.1, C23.1, D3.1 (A), J10.1, R19.1, R20.1, R23.1, R24.1, R25.1, R26.1, R27.1, U6.1 (VCCIO_2), U6.22 (SPI_VCCIO1), U6.33 (VCCIO_0), U10.8 (VCC); also elsewhere on the board
/Application FPGA/APP_+1.2_PLL: C17.1, C25.1, FB3.1, U6.29 (VCCPLL)
/Application FPGA/APP_FLASH_HOLD: R23.2, U10.7 (IO3)
/Application FPGA/APP_FLASH_WP: R26.2, U10.3 (IO2)
APP_BUTTON: R27.2, SW1.1, U6.34 (IOT_44b)
APP_CDONE: R19.2, U6.7 (CDONE); also elsewhere on the board
APP_CRESET: R20.2, U6.8 (~CRESET); also elsewhere on the board
APP_FLASH_MISO: J7.2, U10.2 (DO(IO1)); also elsewhere on the board
APP_FLASH_MOSI: J7.3, U10.5 (DI(IO0)); also elsewhere on the board
APP_GPIO1: J4.1, U6.38 (IOT_50b)
APP_GPIO2: J4.2, U6.37 (IOT_45a_G1)
APP_GPIO3: J4.3, U6.36 (IOT_48b)
APP_GPIO4: J4.4, U6.35 (IOT_46b_G0)
APP_ICE_MISO: J7.1, U6.14 (IOB_32a_SPI_SO)
APP_ICE_MOSI: J7.4, U6.17 (IOB_33b_SPI_SI)
APP_ICE_SCK: R25.2, U6.15 (IOB_34a_SPI_SCK), U10.6 (CLK); also elsewhere on the board
APP_ICE_SS: J6.1, U6.16 (IOB_35b_SPI_SS); also elsewhere on the board
APP_LED_BLUE: R18.1, U6.41 (RGB2)
APP_LED_GREEN: R17.1, U6.40 (RGB1)
APP_LED_RED: R16.1, U6.39 (RGB0)
EXTRA1: J10.6, U6.46 (IOB_0a); also elsewhere on the board
EXTRA2: J10.7, U6.47 (IOB_2a); also elsewhere on the board
EXTRA3: J10.8, U6.48 (IOB_4a); also elsewhere on the board
EXTRA4: J10.9, U6.2 (IOB_6a); also elsewhere on the board
EXTRA5: J10.10, U6.3 (IOB_9b); also elsewhere on the board
EXTRA6: J10.11, U6.4 (IOB_8a); also elsewhere on the board
EXTRA7: J10.12, U6.9 (IOB_16a); also elsewhere on the board
EXTRA8: J10.13, U6.10 (IOB_18a); also elsewhere on the board
EXTRA9: J10.14, U6.11 (IOB_20a); also elsewhere on the board
EXTRA10: J10.15, U6.12 (IOB_22b); also elsewhere on the board
GND: C16.2, C17.2, C18.2, C19.2, C20.2, C21.2, C22.2, C23.2, C25.2, J4.5, J10.16, SW1.2, U6.49 (GND), U10.4 (GND); also elsewhere on the board
MISO: J10.5, U6.45 (IOB_5b); also elsewhere on the board
MOSI: J10.4, U6.44 (IOB_3b_G6); also elsewhere on the board
unnamed: D3.2 (RK), R16.2
unnamed: D3.3 (GK), R17.2
unnamed: D3.4 (BK), R18.2
unnamed: J6.2, R24.2, U10.1 (~CS)
SCK: J10.3, U6.43 (IOT_49a); also elsewhere on the board
SS: J10.2, U6.42 (IOT_51a); also elsewhere on the board

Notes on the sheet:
Application FPGA
Status LED
Expansion GPIO
Programming interface target selection
SPI boot flash
User button
For programming flash- Shunt 1,3 and 2,4, and shunt J6 For programming ICE/NVCM - Shunt 3,4 and 1,2, and remove J6
Note: Any generic SPI flash with >1Mbit capacity is acceptable.
Communication debug header
Note: Programming circuit based on the Lattice Development board
Boot strapping resistors

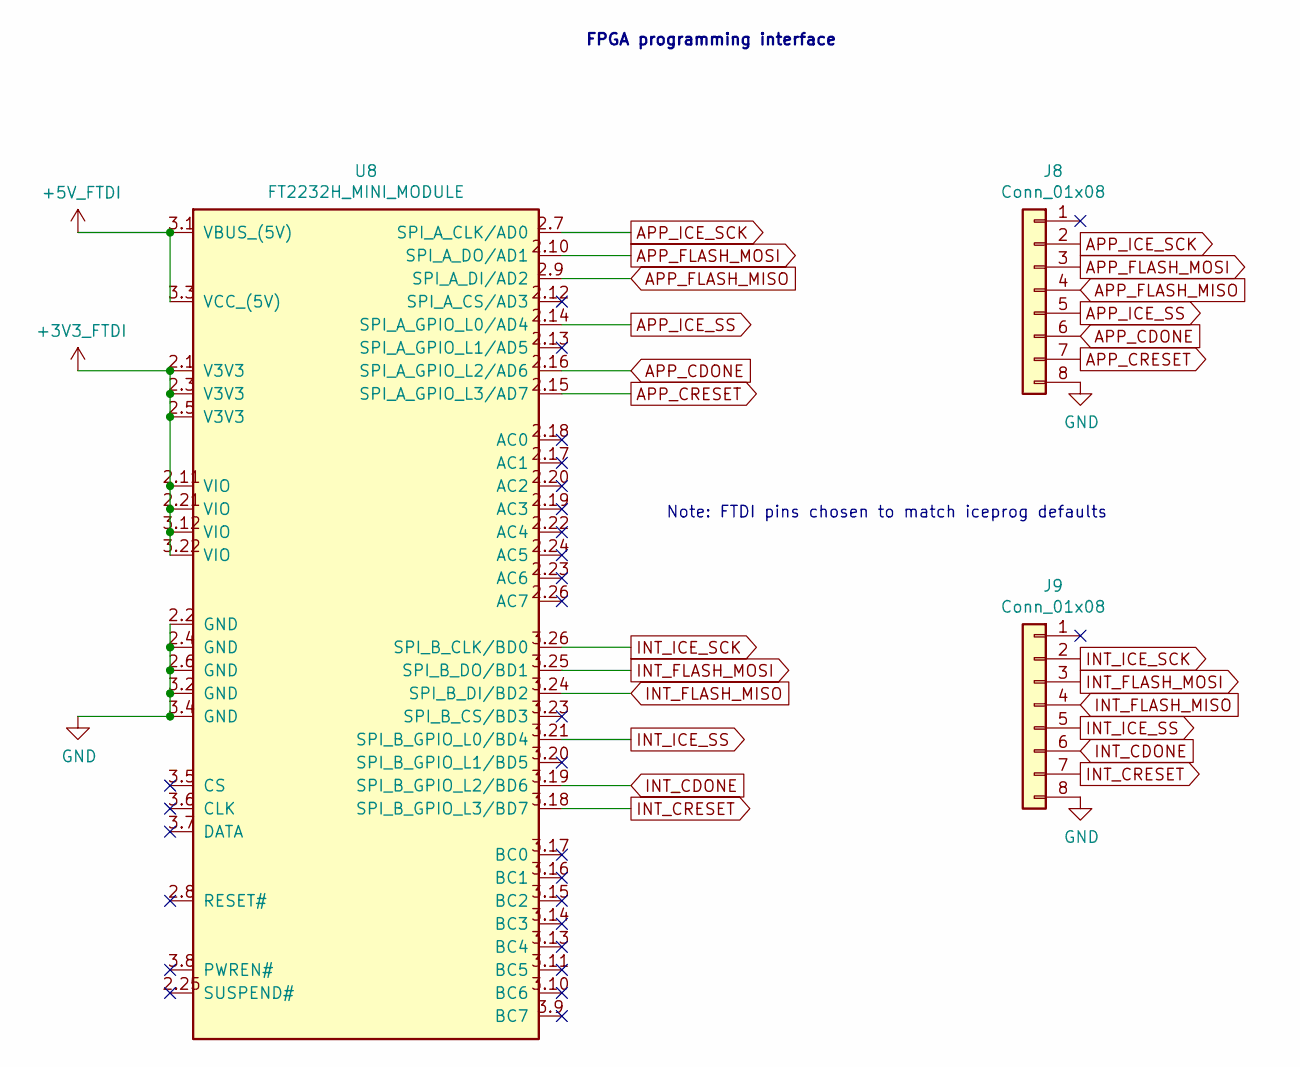
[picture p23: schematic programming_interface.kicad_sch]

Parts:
J8, J9: Conn_01x08; PinHeader_1x08_P2.54mm_Vertical
U8: FT2232H_MINI_MODULE

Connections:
+3V3_FTDI: U8.2.1 (V3V3), U8.2.3 (V3V3), U8.2.5 (V3V3), U8.2.11 (VIO), U8.2.21 (VIO), U8.3.12 (VIO), U8.3.22 (VIO)
+5V_FTDI: U8.3.1 (VBUS_(5V)), U8.3.3 (VCC_(5V)); also elsewhere on the board
APP_CDONE: J8.6, U8.2.16 (SPI_A_GPIO_L2/AD6); also elsewhere on the board
APP_CRESET: J8.7, U8.2.15 (SPI_A_GPIO_L3/AD7); also elsewhere on the board
APP_FLASH_MISO: J8.4, U8.2.9 (SPI_A_DI/AD2); also elsewhere on the board
APP_FLASH_MOSI: J8.3, U8.2.10 (SPI_A_DO/AD1); also elsewhere on the board
APP_ICE_SCK: J8.2, U8.2.7 (SPI_A_CLK/AD0); also elsewhere on the board
APP_ICE_SS: J8.5, U8.2.14 (SPI_A_GPIO_L0/AD4); also elsewhere on the board
GND: J8.8, J9.8, U8.2.2 (GND), U8.2.4 (GND), U8.2.6 (GND), U8.3.2 (GND), U8.3.4 (GND); also elsewhere on the board
INT_CDONE: J9.6, U8.3.19 (SPI_B_GPIO_L2/BD6); also elsewhere on the board
INT_CRESET: J9.7, U8.3.18 (SPI_B_GPIO_L3/BD7); also elsewhere on the board
INT_FLASH_MISO: J9.4, U8.3.24 (SPI_B_DI/BD2); also elsewhere on the board
INT_FLASH_MOSI: J9.3, U8.3.25 (SPI_B_DO/BD1); also elsewhere on the board
INT_ICE_SCK: J9.2, U8.3.26 (SPI_B_CLK/BD0); also elsewhere on the board
INT_ICE_SS: J9.5, U8.3.21 (SPI_B_GPIO_L0/BD4); also elsewhere on the board

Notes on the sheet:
Note: FTDI pins chosen to match iceprog defaults
FPGA programming interface

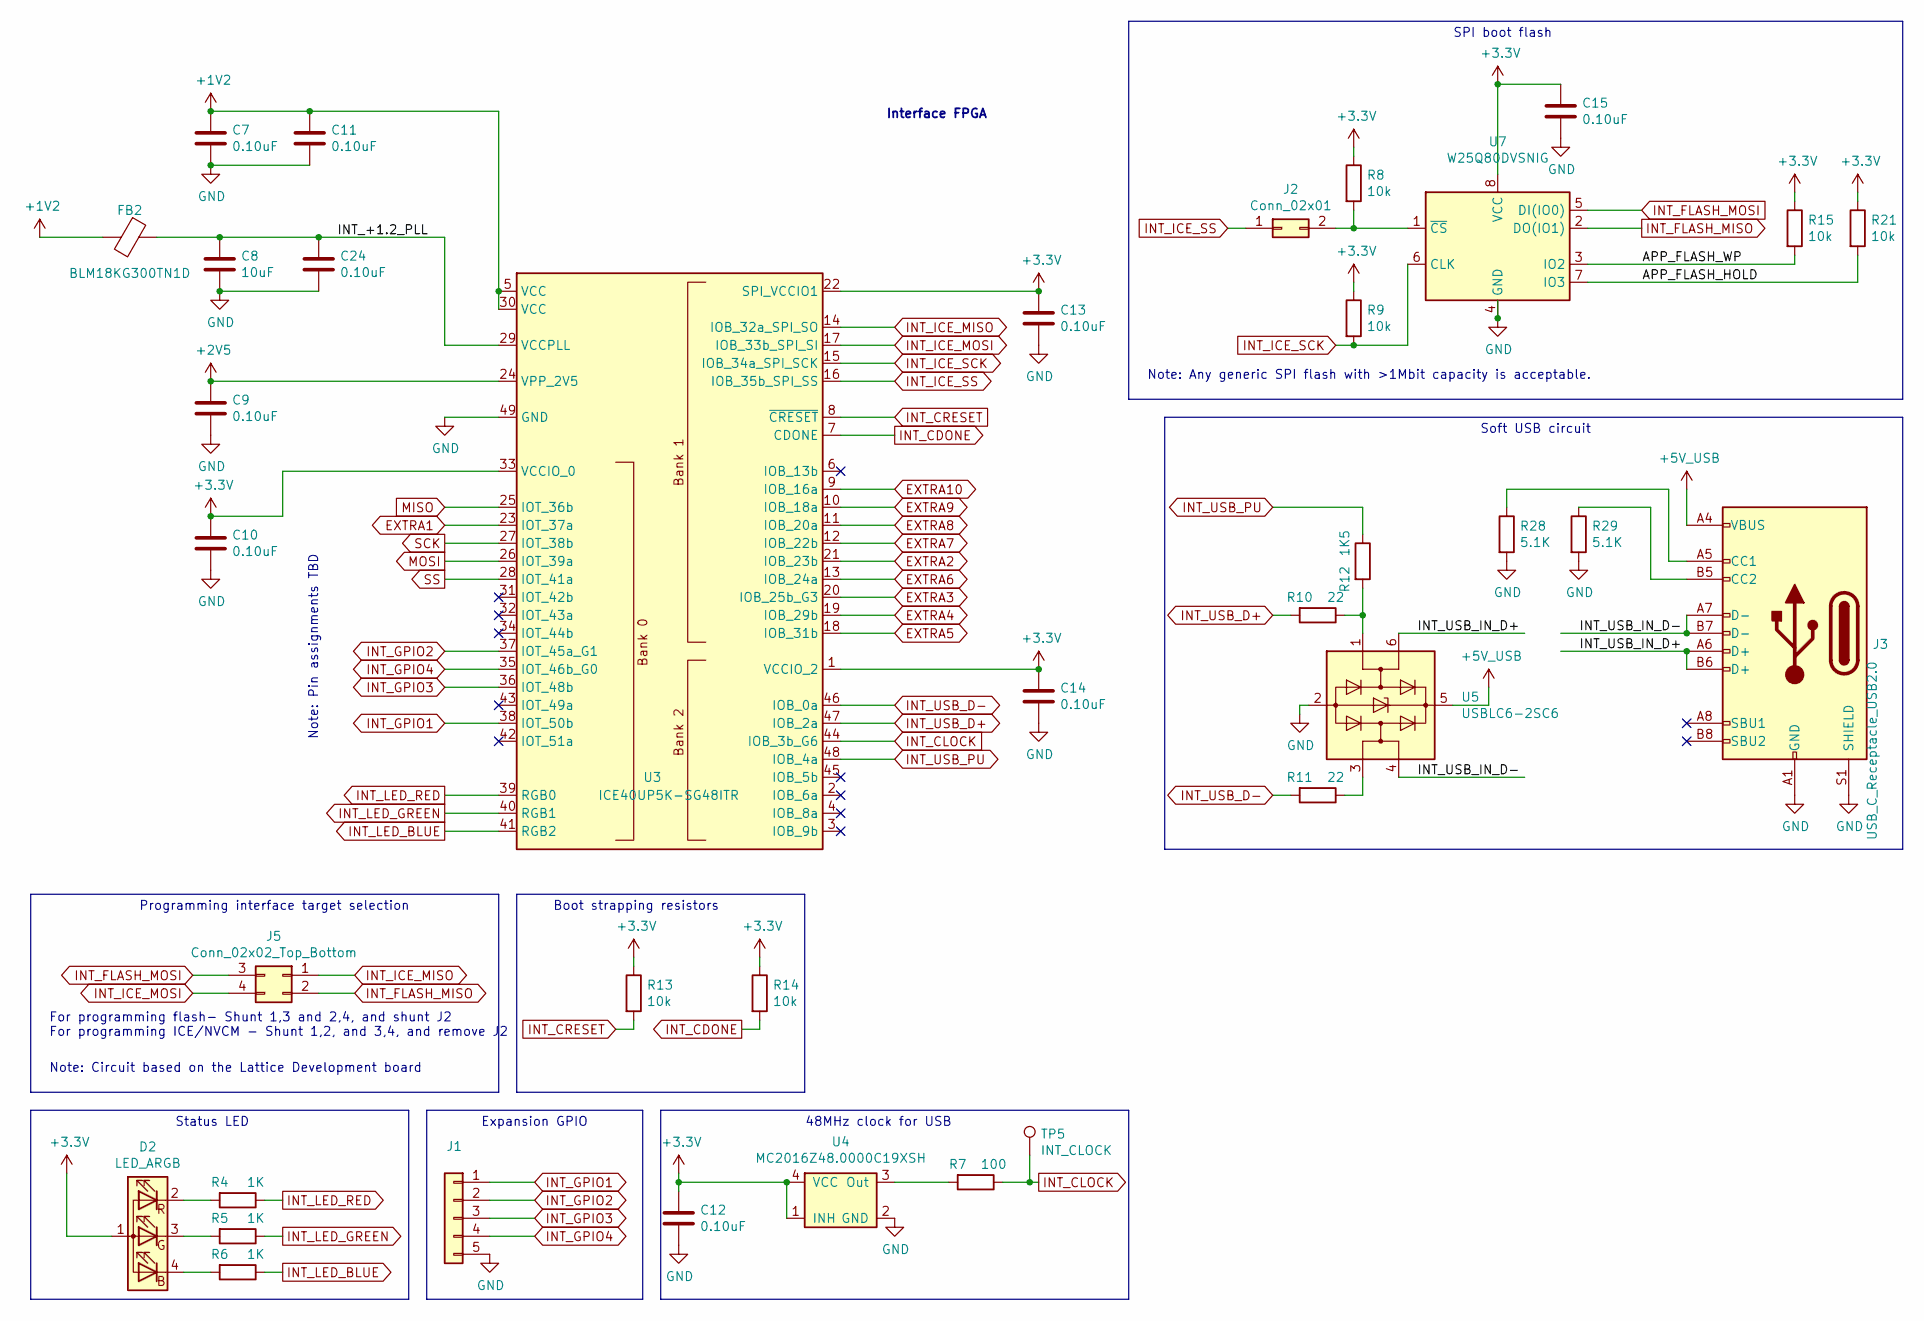
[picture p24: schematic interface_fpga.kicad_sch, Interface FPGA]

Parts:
C7, C9, C10, C11, C12, C13, C14, C15, C24: 0.10uF; CAPC1005X06L
C8: 10uF; CAPC1608X09L
D2: LED_ARGB; 0402rgb-1010
FB2: BLM18KG300TN1D; Ferritbead_0603_1608Metric
J1: PinHeader_1x05_P2.54mm_Vertical
J2: Conn_02x01; PinHeader_1x02_P2.54mm_Vertical
J3: USB_C_Receptacle_USB2.0; USB_C_Receptacle_HRO_TYPE-C-31-M-12
J5: Conn_02x02_Top_Bottom; PinHeader_2x02_P2.54mm_Vertical
R4, R5, R6: 1K; ERJ2G(0402)_L
R7: 100; ERJ2G(0402)_L
R8, R9, R13, R14, R15, R21: 10k; ERJ2G(0402)_L
R10, R11: 22; ERJ2G(0402)_L
R12: 1K5; ERJ2G(0402)_L
R28, R29: 5.1K; ERJ2G(0402)_L
TP5: INT_CLOCK; TestPoint_Pad_D1.0mm
U3: ICE40UP5K-SG48ITR; QFN-48-1EP_7x7mm_P0.5mm_EP5.6x5.6mm
U4: MC2016Z48.0000C19XSH; MC2016Z
U5: USBLC6-2SC6; SOT-23-6
U7: W25Q80DVSNIG; SOIC-8_3.9x4.9mm_P1.27mm

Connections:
+1V2: C7.1, C11.1, FB2.2, U3.5 (VCC), U3.30 (VCC); also elsewhere on the board
+2V5: C9.1, U3.24 (VPP_2V5); also elsewhere on the board
+3V3: C10.1, C12.1, C13.1, C14.1, C15.1, D2.1 (A), R8.1, R9.1, R13.1, R14.1, R15.1, R21.1, U3.1 (VCCIO_2), U3.22 (SPI_VCCIO1), U3.33 (VCCIO_0), U4.1 (INH), U4.4 (VCC), U7.8 (VCC); also elsewhere on the board
+5V_USB: J3.A4 (VBUS), J3.A9 (VBUS), J3.B4 (VBUS), J3.B9 (VBUS), U5.5 (VBUS); also elsewhere on the board
/Interface FPGA/APP_FLASH_HOLD: R21.2, U7.7 (IO3)
/Interface FPGA/APP_FLASH_WP: R15.2, U7.3 (IO2)
/Interface FPGA/INT_+1.2_PLL: C8.1, C24.1, FB2.1, U3.29 (VCCPLL)
/Interface FPGA/INT_USB_IN_D+: J3.A6 (D+), J3.B6 (D+), U5.6 (I/O1)
/Interface FPGA/INT_USB_IN_D-: J3.A7 (D-), J3.B7 (D-), U5.4 (I/O2)
EXTRA1: U3.23 (IOT_37a); also elsewhere on the board
EXTRA2: U3.21 (IOB_23b); also elsewhere on the board
EXTRA3: U3.20 (IOB_25b_G3); also elsewhere on the board
EXTRA4: U3.19 (IOB_29b); also elsewhere on the board
EXTRA5: U3.18 (IOB_31b); also elsewhere on the board
EXTRA6: U3.13 (IOB_24a); also elsewhere on the board
EXTRA7: U3.12 (IOB_22b); also elsewhere on the board
EXTRA8: U3.11 (IOB_20a); also elsewhere on the board
EXTRA9: U3.10 (IOB_18a); also elsewhere on the board
EXTRA10: U3.9 (IOB_16a); also elsewhere on the board
GND: C7.2, C8.2, C9.2, C10.2, C11.2, C12.2, C13.2, C14.2, C15.2, C24.2, J1.5, J3.A1 (GND), J3.A12 (GND), J3.B1 (GND), J3.B12 (GND), J3.S1 (SHIELD), R28.2, R29.2, U3.49 (GND), U4.2 (GND), U5.2 (GND), U7.4 (GND); also elsewhere on the board
INT_CDONE: R14.2, U3.7 (CDONE); also elsewhere on the board
INT_CLOCK: R7.1, TP5.1, U3.44 (IOB_3b_G6)
INT_CRESET: R13.2, U3.8 (~CRESET); also elsewhere on the board
INT_FLASH_MISO: J5.2, U7.2 (DO(IO1)); also elsewhere on the board
INT_FLASH_MOSI: J5.3, U7.5 (DI(IO0)); also elsewhere on the board
INT_GPIO1: J1.1, U3.38 (IOT_50b)
INT_GPIO2: J1.2, U3.37 (IOT_45a_G1)
INT_GPIO3: J1.3, U3.36 (IOT_48b)
INT_GPIO4: J1.4, U3.35 (IOT_46b_G0)
INT_ICE_MISO: J5.1, U3.14 (IOB_32a_SPI_SO)
INT_ICE_MOSI: J5.4, U3.17 (IOB_33b_SPI_SI)
INT_ICE_SCK: R9.2, U3.15 (IOB_34a_SPI_SCK), U7.6 (CLK); also elsewhere on the board
INT_ICE_SS: J2.1, U3.16 (IOB_35b_SPI_SS); also elsewhere on the board
INT_LED_BLUE: R6.1, U3.41 (RGB2)
INT_LED_GREEN: R5.1, U3.40 (RGB1)
INT_LED_RED: R4.1, U3.39 (RGB0)
INT_USB_D+: R10.2, U3.47 (IOB_2a)
INT_USB_D-: R11.2, U3.46 (IOB_0a)
INT_USB_PU: R12.1, U3.48 (IOB_4a)
MISO: U3.25 (IOT_36b); also elsewhere on the board
MOSI: U3.26 (IOT_39a); also elsewhere on the board
unnamed: D2.2 (RK), R4.2
unnamed: D2.3 (GK), R5.2
unnamed: D2.4 (BK), R6.2
unnamed: J2.2, R8.2, U7.1 (~CS)
unnamed: J3.A5 (CC1), R28.1
unnamed: J3.B5 (CC2), R29.1
unnamed: R7.2, U4.3 (Out)
unnamed: R10.1, R12.2, U5.1 (I/O1)
unnamed: R11.1, U5.3 (I/O2)
SCK: U3.27 (IOT_38b); also elsewhere on the board
SS: U3.28 (IOT_41a); also elsewhere on the board

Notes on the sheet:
Expansion GPIO
48MHz clock for USB
Note: Any generic SPI flash with >1Mbit capacity is acceptable.
Boot strapping resistors
Soft USB circuit
Note: Circuit based on the Lattice Development board
Status LED
Programming interface target selection
Interface FPGA
Note: Pin assignments TBD
For programming flash- Shunt 1,3 and 2,4, and shunt J2 For programming ICE/NVCM - Shunt 1,2, and 3,4, and remove J2
SPI boot flash


Board: 4 copper layers, 91.4 x 40.6 mm, 92 parts (0 on the bottom side), 83 nets.

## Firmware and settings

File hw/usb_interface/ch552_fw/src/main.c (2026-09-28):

// SPDX-FileCopyrightText: 2017 WCH <wch-ic.com>
// SPDX-FileCopyrightText: 2022 Tillitis AB <tillitis.se>
// SPDX-License-Identifier: MIT

/********************************** (C) COPYRIGHT *******************************
 * File Name          : CDC.C
 * Author             : WCH
 * Version            : V1.0
 * Date               : 2017/03/01
 * Description        : CH554 as CDC device to serial port, select serial port 1
 *******************************************************************************/
#include <stdint.h>
#include <string.h>

#include <ch554.h>
#include <ch554_usb.h>

#include "config.h"
#include "debug.h"
#include "flash.h"
#include "io.h"
#include "lib.h"
#include "mem.h"
#include "print.h"
#include "usb_strings.h"

XDATA AT0000 uint8_t Ep0Buffer[DEFAULT_EP0_SIZE + 2*DEFAULT_EP4_SIZE] = { 0 };
                                                            // Endpoint 0, Default endpoint, OUT & IN buffer[64],
                                                            // must be an even address.
                                                            // Endpoint 4, DEBUG endpoint, buffer OUT[64]+IN[64],
                                                            // must be an even address
XDATA AT00C0 uint8_t Ep1Buffer[  DEFAULT_EP1_SIZE] = { 0 }; // Endpoint 1, CDC Ctrl endpoint, IN[8] buffer
XDATA AT00C8 uint8_t Ep2Buffer[2*DEFAULT_EP2_SIZE] = { 0 }; // Endpoint 2, CDC Data endpoint, buffer OUT[64]+IN[64],
                                                            // must be an even address
XDATA AT0148 uint8_t Ep3Buffer[2*DEFAULT_EP3_SIZE] = { 0 }; // Endpoint 3, FIDO/CCID endpoint, buffer OUT[64]+IN[64],
                                                            // must be an even address

#define Ep2BufferRx  (Ep2Buffer)
#define Ep2BufferTx  (Ep2Buffer + DEFAULT_EP2_SIZE)
#define Ep3BufferRx  (Ep3Buffer)
#define Ep3BufferTx  (Ep3Buffer + DEFAULT_EP3_SIZE)
#define Ep4BufferRx  (Ep0Buffer + DEFAULT_EP0_SIZE)
#define Ep4BufferTx  (Ep0Buffer + DEFAULT_EP0_SIZE + DEFAULT_EP4_SIZE)

uint16_t SetupLen = 0;
uint8_t SetupReq = 0;
uint8_t UsbConfig = 0;
const uint8_t *pDescr = NULL;         // USB configuration flag

#define UsbSetupBuf                   ((PUSB_SETUP_REQ)Ep0Buffer)

#define CDC_CTRL_EPOUT_ADDR            0x01              // CDC Ctrl Endpoint OUT Address
#define CDC_CTRL_EPOUT_SIZE            DEFAULT_EP1_SIZE  // CDC Ctrl Endpoint OUT Size

#define CDC_CTRL_EPIN_ADDR             0x81              // CDC Ctrl Endpoint IN Address
#define CDC_CTRL_EPIN_SIZE             DEFAULT_EP1_SIZE  // CDC Ctrl Endpoint IN Size

#define CDC_DATA_EPOUT_ADDR            0x02              // CDC Data Endpoint OUT Address
#define CDC_DATA_EPOUT_SIZE            DEFAULT_EP2_SIZE  // CDC Data Endpoint OUT Size

#define CDC_DATA_EPIN_ADDR             0x82              // CDC Data Endpoint IN Address
#define CDC_DATA_EPIN_SIZE             DEFAULT_EP2_SIZE  // CDC Data Endpoint IN Size

#define FIDO_EPOUT_ADDR                0x03              // FIDO Endpoint OUT Address
#define FIDO_EPOUT_SIZE                DEFAULT_EP3_SIZE  // FIDO Endpoint OUT Size

#define FIDO_EPIN_ADDR                 0x83              // FIDO Endpoint IN Address
#define FIDO_EPIN_SIZE                 DEFAULT_EP3_SIZE  // FIDO Endpoint IN Size

#define CCID_BULK_EPOUT_ADDR           0x03              // CCID Bulk Endpoint OUT Address
#define CCID_BULK_EPOUT_SIZE           DEFAULT_EP3_SIZE  // CCID Bulk Endpoint OUT Size

#define CCID_BULK_EPIN_ADDR            0x83              // CCID Bulk Endpoint IN Address
#define CCID_BULK_EPIN_SIZE            DEFAULT_EP3_SIZE  // CCID Bulk Endpoint IN Size

#define DEBUG_EPOUT_ADDR               0x04              // DEBUG Endpoint OUT Address
#define DEBUG_EPOUT_SIZE               DEFAULT_EP4_SIZE  // DEBUG Endpoint OUT Size

#define DEBUG_EPIN_ADDR                0x84              // DEBUG Endpoint IN Address
#define DEBUG_EPIN_SIZE                DEFAULT_EP4_SIZE  // DEBUG Endpoint IN Size

#define CDC_CTRL_FS_BINTERVAL          16                // Gives 16 ms polling interval at Full Speed for interrupt transfers
#define CDC_DATA_FS_BINTERVAL          0                 // bInterval is ignored for BULK transfers

#ifdef USE_SLOW_TRANSFER_FOR_FIDO
#define FIDO_FS_BINTERVAL              16                // Gives 16 ms polling interval at Full Speed for interrupt transfers
#else
#define FIDO_FS_BINTERVAL              2                 // Gives 2 ms polling interval at Full Speed for interrupt transfers
#endif

#define CCID_BULK_FS_BINTERVAL         0                 // bInterval is ignored for BULK transfers

#ifdef USE_BULK_TRANSFER_FOR_DEBUG
#define DEBUG_FS_BINTERVAL             0                 // bInterval is ignored for BULK transfers
#define DEBUG_DESC_SIZE                23                // Size of DebugDesc
#else
#define DEBUG_FS_BINTERVAL             16                // Gives 16 ms polling interval at Full Speed for interrupt transfers
#define DEBUG_DESC_SIZE                32                // Size of DebugDesc
#define DEBUG_REPORT_DESC_SIZE         34                // Size of DebugReportDesc
#endif

#define MAX_CFG_DESC_SIZE              (9+66+77+DEBUG_DESC_SIZE)  // Size of CfgDesc+CdcDesc+MAX(FidoDesc,CcidDesc)+DebugDesc

#define NUM_INTERFACES                 4                 // Number of interfaces

#define CHANGE_ME                      0x00              // Value placeholder

#define FIDO_REPORT_DESC_SIZE          47                // Size of FidoReportDesc

#define CCID_VALUE_BCDCCID                 0x0110
#define CCID_VALUE_DWPROTOCOLS             0x00000002
#define CCID_VALUE_DWDEFAULTCLOCK          3580
#define CCID_VALUE_DWMAXIUMUMCLOCK         3580
#define CCID_VALUE_DWDATARATE              9600
#define CCID_VALUE_DWMAXDATARATE           9600
#define CCID_VALUE_DWMAXIFSD               254
#define CCID_VALUE_DWSYNCPROTOCOLS         0x0
#define CCID_VALUE_DWMECHANICAL            0x0
#define CCID_VALUE_DWFEATURES              0x000400FE
#define CCID_VALUE_DWMAXCCIDMESSAGELENGTH  3072
#define CCID_VALUE_WLCDLAYOUT              0x0

#define MIN(a, b)  (((a) < (b)) ? (a) : (b))
#define MAX(a, b)  (((a) > (b)) ? (a) : (b))

#define LOBYTE(x)  ((uint8_t)( (x)        & 0x00FFU))
#define HIBYTE(x)  ((uint8_t)(((x) >> 8U) & 0x00FFU))

#define BYTE0(x)   ((uint8_t)( (x)        & 0x000000FFU))  // Least significant byte
#define BYTE1(x)   ((uint8_t)(((x) >>  8) & 0x000000FFU))  // Second byte
#define BYTE2(x)   ((uint8_t)(((x) >> 16) & 0x000000FFU))  // Third byte
#define BYTE3(x)   ((uint8_t)(((x) >> 24) & 0x000000FFU))  // Most significant byte

uint8_t FidoInterfaceNum = 0;
uint8_t CcidInterfaceNum = 0;
uint8_t DebugInterfaceNum = 0;

XDATA uint8_t ActiveCfgDesc[MAX_CFG_DESC_SIZE];
XDATA uint8_t ActiveCfgDescSize = 0;

// Device Descriptor
FLASH uint8_t DevDesc[] = {
        0x12,                             /* bLength */
        USB_DESC_TYPE_DEVICE,             /* bDescriptorType: Device */
        0x00,                             /* bcdUSB (low byte), USB Specification Release Number in Binary-Coded Decimal (2.0 is 200h) */
        0x02,                             /* bcdUSB (high byte) USB Specification Release Number in Binary-Coded Decimal (2.0 is 200h) */
        USB_DEV_CLASS_MISCELLANEOUS,      /* bDeviceClass: Miscellaneous Device Class (Composite) */
        0x02,                             /* bDeviceSubClass: Common Class */
        0x01,                             /* bDeviceProtocol: IAD (Interface Association Descriptor) */
        BUF_EP0_SIZE,                     /* bMaxPacketSize */
        0x09,                             /* idVendor */            // VID LOBYTE
        0x12,                             /* idVendor */            // VID HIBYTE
        0x85,                             /* idProduct */           // PID LOBYTE
        0x88,                             /* idProduct */           // PID HIBYTE
        0x00,                             /* bcdDevice (device release number in binary-coded decimal (BCD) format, low byte, i.e. YY) rel. XX.YY */
        0x01,                             /* bcdDevice (device release number in binary-coded decimal (BCD) format, high byte, i.e. XX) rel. XX.YY */
        USB_IDX_MFC_STR,                  /* Index of manufacturer string */
        USB_IDX_PRODUCT_STR,              /* Index of product string */
        USB_IDX_SERIAL_STR,               /* Index of serial number string */
        0x01,                             /* bNumConfigurations */
        /* 18 */
};

// Configuration Descriptor
FLASH uint8_t CfgDesc[] = {
        /******************** Configuration Descriptor ********************/
        0x09,                             /* bLength: Configuration Descriptor size */
        USB_DESC_TYPE_CONFIGURATION,      /* bDescriptorType: Configuration */
        CHANGE_ME,                        /* wTotalLength (low byte): Bytes returned */
        0x00,                             /* wTotalLength (high byte): Bytes returned */
        CHANGE_ME,                        /* bNumInterfaces: 1 CDC Ctrl + 1 CDC Data, 1 FIDO or 1 CCID, 1 DEBUG ) */
        0x01,                             /* bConfigurationValue: Configuration value */
        0x00,                             /* iConfiguration: Index of string descriptor describing the configuration */
        0xA0,                             /* bmAttributes: Bus powered and Support Remote Wake-up */
        0x32,                             /* MaxPower 100 mA: this current is used for detecting Vbus */
        /* 9 */
};
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
void main(void)
{
    gpio_init_p1_5_out();   // Init GPIO p1.5 to output mode for CH552_CTS
    cts_stop();             // Signal not OK to send
    gpio_init_p1_4_in();    // Init GPIO p1.4 to input mode for FPGA_CTS

    CfgFsys();     // CH559 clock selection configuration
    mDelaymS(5);   // Modify the main frequency and wait for the internal crystal to stabilize, which must be added
#ifdef DEBUG_PRINT_HW
    mInitSTDIO();  // Serial port 0, can be used for debugging
#endif
    UART1Setup();  // For communication with FPGA
    UART1Clean();  // Clean register from spurious data

    printStrSetup("\nStartup\n");

    uint8_t ActiveEndpoints = RESET_KEEP;

    // Always enable CH552 endpoint
    if ((ActiveEndpoints & IO_CH552) == 0x0) {
        ActiveEndpoints |= IO_CH552;
    }

    // FIDO and CCID can't be enabled at the same time. Disable both!
    if ((ActiveEndpoints & IO_FIDO) && (ActiveEndpoints & IO_CCID)) {
        ActiveEndpoints &= ~(IO_FIDO | IO_CCID);
    }

    // If no USB endpoints enabled we wait for a valid
    // SET_ENDPOINTS command.
    if (ActiveEndpoints == IO_CH552) {
        EA = 1;                      // Allow microcontroller interrupt
        cts_start();

        while (uart_byte_count() < 4)
            ;

        uint8_t InitFrameMode = UartRxBuf[UartRxBufOutputPointer];
        UartRxBufOutputPointer = increment_pointer(UartRxBufOutputPointer, 1, UART_RX_BUF_SIZE);

        uint8_t InitFrameLength = UartRxBuf[UartRxBufOutputPointer];
        UartRxBufOutputPointer = increment_pointer(UartRxBufOutputPointer, 1, UART_RX_BUF_SIZE);

        uint8_t Ch552Command = UartRxBuf[UartRxBufOutputPointer];
        UartRxBufOutputPointer = increment_pointer(UartRxBufOutputPointer, 1, UART_RX_BUF_SIZE);

        uint8_t Endpoints = UartRxBuf[UartRxBufOutputPointer];
        UartRxBufOutputPointer = increment_pointer(UartRxBufOutputPointer, 1, UART_RX_BUF_SIZE);

        if (InitFrameMode == IO_CH552 && InitFrameLength == 2 && Ch552Command == SET_ENDPOINTS) {
            RESET_KEEP = Endpoints; // Save endpoints to persistent register
        } else {
            RESET_KEEP = 0; // Disable all USB endpoints on invalid command
        }

        cts_stop(); // Stop UART data from FPGA
        SAFE_MOD = 0x55; // Start reset sequence
        SAFE_MOD = 0xAA;
        GLOBAL_CFG = bSW_RESET;
        while (1)
            ;
    }

    CreateCfgDescriptor(ActiveEndpoints);

    USBDeviceCfg();
    USBDeviceEndPointCfg(); // Endpoint configuration
    USBDeviceIntCfg();      // Interrupt initialization

    UEP0_T_LEN = 0;         // Transmit length must be cleared (Endpoint 0)
    UEP1_T_LEN = 0;         // Transmit length must be cleared (Endpoint 1)
    UEP2_T_LEN = 0;         // Transmit length must be cleared (Endpoint 2)
    UEP3_T_LEN = 0;         // Transmit length must be cleared (Endpoint 3)
    UEP4_T_LEN = 0;         // Transmit length must be cleared (Endpoint 4)

    cts_start();            // Signal OK to send

    while (1) {
        if (UsbConfig) {

            // Check if Endpoint 2 (CDC) has received data
            if (UsbEp2ByteCount && fpga_uart_ready()) {
                // Only send if FPGA CTS is low (ready to receive)

                CH554UART1SendByte(IO_CDC);  // Send CDC mode header
                CH554UART1SendByte(UsbEp2ByteCount);  // Send length
                CH554UART1SendBuffer(Ep2BufferRx, UsbEp2ByteCount);
                UsbEp2ByteCount = 0;
                UEP2_CTRL = (UEP2_CTRL & ~MASK_UEP_R_RES) | UEP_R_RES_ACK; // Enable Endpoint 2 to ACK again
            }

            // Check if Endpoint 3 (FIDO or CCID) has received data
            if (UsbEp3ByteCount && fpga_uart_ready()) {
                // Only send if FPGA CTS is low (ready to receive)

                if (ActiveEndpoints & IO_FIDO) {
                    CH554UART1SendByte(IO_FIDO); // Send FIDO mode header
                } else if (ActiveEndpoints & IO_CCID) {
                    CH554UART1SendByte(IO_CCID); // Send CCID mode header
                }

                CH554UART1SendByte(UsbEp3ByteCount); // Send length (always 64 bytes for FIDO, variable for CCID)
                CH554UART1SendBuffer(Ep3BufferRx, UsbEp3ByteCount);
                UsbEp3ByteCount = 0;
                UEP3_CTRL = (UEP3_CTRL & ~MASK_UEP_R_RES) | UEP_R_RES_ACK; // Enable Endpoint 3 to ACK again
            }

            // Check if Endpoint 4 (DEBUG) has received data
            if (UsbEp4ByteCount && fpga_uart_ready()) {
                // Only send if FPGA CTS is low (ready to receive)

                CH554UART1SendByte(IO_DEBUG); // Send DEBUG mode header
                CH554UART1SendByte(UsbEp4ByteCount); // Send length (always 64 bytes)
                CH554UART1SendBuffer(Ep4BufferRx, UsbEp4ByteCount);
                UsbEp4ByteCount = 0;
                UEP4_CTRL = (UEP4_CTRL & ~MASK_UEP_R_RES) | UEP_R_RES_ACK; // Enable Endpoint 4 to ACK again
            }

            UartRxBufByteCount = uart_byte_count(); // Check amount of data in buffer

            if ((UartRxBufByteCount >= 2) && !FrameStarted) {  // If we have data and the header is not yet validated
                FrameMode = UartRxBuf[UartRxBufOutputPointer]; // Extract frame mode
                if ((FrameMode == IO_CDC)   ||
                    (FrameMode == IO_FIDO)  ||
                    (FrameMode == IO_CCID)  ||
                    (FrameMode == IO_DEBUG) ||
                    (FrameMode == IO_CH552)) {

                    FrameLength = UartRxBuf[increment_pointer(UartRxBufOutputPointer,
                                                              1,
                                                              UART_RX_BUF_SIZE)]; // Extract frame length
                    FrameRemainingBytes = FrameLength;
                    UartRxBufOutputPointer = increment_pointer(UartRxBufOutputPointer,
                                                               2,
                                                               UART_RX_BUF_SIZE); // Start at valid data so skip the mode and length byte
                    UartRxBufByteCount -= 2; // Subtract the frame mode and frame length bytes from the total byte count
                    FrameStarted = 1;

                    // Mark that we should discard data if destination for the frame is not active
                    if ((FrameMode & ActiveEndpoints) == 0) {
                        FrameDiscard = 1;
                    }

                } else { // Invalid frame mode

                    cts_stop();

                    // Reset CH552 to start from a known state
                    SAFE_MOD = 0x55;
                    SAFE_MOD = 0xAA;
                    GLOBAL_CFG = bSW_RESET;
                    while (1)
                        ;
                }
            }
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

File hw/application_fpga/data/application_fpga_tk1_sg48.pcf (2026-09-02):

#=======================================================================
#
# application_fpga_tk1_sg48.pcf
# ------------------------
# Pin constraints file for the Application FPGA design to be used
# on the tk1 board with the CH552 MCU used as a USB-serial chip.
# This version targets the SG48 package.
#
#
# SPDX-FileCopyrightText: 2022 Tillitis AB <tillitis.se>
# SPDX-License-Identifier: BSD-2-Clause
#
#=======================================================================

# UART.
set_io interface_rx 26
set_io interface_tx 25
set_io interface_ch552_cts 27
set_io interface_fpga_cts 28


# SPI master to flash memory.
set_io spi_miso 17
set_io spi_sck  15
set_io spi_ss   16
set_io spi_mosi 14


# Touch sense.
set_io touch_event 6


# GPIOs.
set_io app_gpio1 36
set_io app_gpio2 38
set_io app_gpio3 45
set_io app_gpio4 46


# LEDs
set_io led_r 39
set_io led_g 40
set_io led_b 41

#=======================================================================
# EOF application_fpga_tk1_sg48.pcf
#=======================================================================

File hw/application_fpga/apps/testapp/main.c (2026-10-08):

// SPDX-FileCopyrightText: 2022 Tillitis AB <tillitis.se>
// SPDX-License-Identifier: BSD-2-Clause

#include <fw/tk1/proto.h>
#include <fw/tk1/reset.h>
#include <fw/tk1/syscall_num.h>
#include <stdint.h>
#include <string.h>
#include <tkey/assert.h>
#include <tkey/io.h>
#include <tkey/led.h>
#include <tkey/lib.h>
#include <tkey/tk1_mem.h>

#include "syscall.h"

#define USBMODE_PACKET_SIZE 64

// clang-format off
volatile uint32_t *tk1name0         = (volatile uint32_t *)TK1_MMIO_TK1_NAME0;
volatile uint32_t *tk1name1         = (volatile uint32_t *)TK1_MMIO_TK1_NAME1;
volatile uint32_t *tk1version       = (volatile uint32_t *)TK1_MMIO_TK1_VERSION;
volatile uint32_t *uds              = (volatile uint32_t *)TK1_MMIO_UDS_FIRST;
volatile uint32_t *cdi              = (volatile uint32_t *)TK1_MMIO_TK1_CDI_FIRST;
volatile uint32_t *udi              = (volatile uint32_t *)TK1_MMIO_TK1_UDI_FIRST;
volatile uint8_t  *fw_ram           = (volatile uint8_t  *)TK1_MMIO_FW_RAM_BASE;
volatile uint32_t *system_reset     = (volatile uint32_t *)TK1_MMIO_TK1_SYSTEM_RESET;
volatile uint32_t *timer            = (volatile uint32_t *)TK1_MMIO_TIMER_TIMER;
volatile uint32_t *timer_prescaler  = (volatile uint32_t *)TK1_MMIO_TIMER_PRESCALER;
volatile uint32_t *timer_status     = (volatile uint32_t *)TK1_MMIO_TIMER_STATUS;
volatile uint32_t *timer_ctrl       = (volatile uint32_t *)TK1_MMIO_TIMER_CTRL;
volatile uint32_t *trng_status      = (volatile uint32_t *)TK1_MMIO_TRNG_STATUS;
volatile uint32_t *trng_entropy     = (volatile uint32_t *)TK1_MMIO_TRNG_ENTROPY;
// clang-format on

#define UDS_WORDS 8
#define UDI_WORDS 2
#define CDI_WORDS 8

void puthexn(uint8_t *p, int n)
{
	for (int i = 0; i < n; i++) {
		puthex(IO_CDC, p[i]);
	}
}

void reverseword(uint32_t *wordp)
{
	*wordp = ((*wordp & 0xff000000) >> 24) | ((*wordp & 0x00ff0000) >> 8) |
		 ((*wordp & 0x0000ff00) << 8) | ((*wordp & 0x000000ff) << 24);
}

uint32_t wait_timer_tick(uint32_t last_timer)
{
	uint32_t newtimer;
	for (;;) {
		newtimer = *timer;
		if (newtimer != last_timer) {
			return newtimer;
		}
	}
}

void failmsg(char *s)
{
	puts(IO_CDC, "FAIL: ");
	puts(IO_CDC, s);
	puts(IO_CDC, "\r\n");
}

int main(void)
{
	uint8_t in = 0;
	uint8_t available = 0;
	enum ioend endpoint = IO_NONE;

	led_set(LED_BLUE);

	config_endpoints(IO_CDC);

	// Wait for terminal program and a character to be typed
	if (readselect(IO_CDC, false, &endpoint, &available) < 0) {
		// readselect failed! I/O broken? Just redblink.
		assert(1 == 2);
	}

	if (read(IO_CDC, &in, 1, 1) < 0) {
		// read failed! I/O broken? Just redblink.
		assert(1 == 2);
	}

	puts(IO_CDC, "\r\nI'm testapp on:");
	// Output the TK1 core's NAME0 and NAME1
	uint32_t name;
	wordcpy_s(&name, 1, (void *)tk1name0, 1);
	reverseword(&name);
	write(IO_CDC, (const uint8_t *)&name, 4);
	puts(IO_CDC, " ");
	wordcpy_s(&name, 1, (void *)tk1name1, 1);
	reverseword(&name);
	write(IO_CDC, (const uint8_t *)&name, 4);
	puts(IO_CDC, "\r\n");
	puts(IO_CDC, "Version: ");
	putinthex(IO_CDC, *tk1version);
	puts(IO_CDC, "\r\n");

	uint32_t zeros[8];
	memset(zeros, 0, 8 * 4);

	int anyfailed = 0;

	uint32_t uds_local[UDS_WORDS];
	uint32_t udi_local[UDI_WORDS];

	// Should NOT be able to read from UDS in app-mode.
	wordcpy_s(uds_local, UDS_WORDS, (void *)uds, UDS_WORDS);
	if (!memeq(uds_local, zeros, UDS_WORDS * 4)) {
		failmsg("Read from UDS in app-mode");
		anyfailed = 1;
	}

	// Should NOT be able to read from UDI in app-mode.
	wordcpy_s(udi_local, UDI_WORDS, (void *)udi, UDI_WORDS);
	if (!memeq(udi_local, zeros, UDI_WORDS * 4)) {
		failmsg("Read from UDI in app-mode");
		anyfailed = 1;
	}

	// But a syscall to get parts of UDI should be able to run
	int vidpid = syscall(TK1_SYSCALL_GET_VIDPID, 0, 0, 0);

	if (vidpid != 0x073570c0) {
		failmsg("Expected VID/PID to be 0x073570c0");
		anyfailed = 1;
	}

	puts(IO_CDC, "\r\nAllocating storage area...");

	if (syscall(TK1_SYSCALL_ALLOC_AREA, 0, 0, 0) != 0) {
		failmsg("Failed to allocate storage area");
	}
	puts(IO_CDC, "done.\r\n");

	puts(IO_CDC, "\r\nWriting to storage area...");

	uint8_t out_data[14] = {0, 1, 2, 3, 4, 5, 6, 7, 8, 9, 10, 11, 12, 13};
	if (syscall(TK1_SYSCALL_WRITE_DATA, 0, (uint32_t)out_data,
		    sizeof(out_data)) != 0) {
		failmsg("Failed to write to storage area");
	}
	puts(IO_CDC, "done.\r\n");

	puts(IO_CDC, "\r\nReading data from storage area...");

	uint8_t in_data[14] = {0};
	if (syscall(TK1_SYSCALL_READ_DATA, 0, (uint32_t)in_data,
		    sizeof(in_data)) != 0) {
		failmsg("Failed to write to storage area");
	}
	if (!memeq(in_data, out_data, sizeof(in_data))) {
		failmsg("Failed to read back data from storage area");
		anyfailed = 1;
	}
	puts(IO_CDC, "done.\r\n");

	puts(IO_CDC, "\r\nErasing written data from storage area...");

	if (syscall(TK1_SYSCALL_ERASE_DATA, 0, 4096, 0) != 0) {
		failmsg("Failed to erase storage area");
	}
	puts(IO_CDC, "done.\r\n");

	puts(IO_CDC, "\r\nVerify erased storage area data...");

	if (syscall(TK1_SYSCALL_READ_DATA, 0, (uint32_t)in_data,
		    sizeof(in_data)) != 0) {
		failmsg("Failed to write to storage area");
	}
	uint8_t check_data[sizeof(in_data)] = {0xff, 0xff, 0xff, 0xff, 0xff,
					       0xff, 0xff, 0xff, 0xff, 0xff,
					       0xff, 0xff, 0xff, 0xff};
	if (!memeq(in_data, check_data, sizeof(check_data))) {
		failmsg("Failed to read back data from storage area");
		anyfailed = 1;
	}
	puts(IO_CDC, "done.\r\n");

	puts(IO_CDC, "\r\nDeallocating storage area...");

	if (syscall(TK1_SYSCALL_DEALLOC_AREA, 0, 0, 0) != 0) {
		failmsg("Failed to deallocate storage area");
	}
	puts(IO_CDC, "done.\r\n");

	uint32_t cdi_local[CDI_WORDS];
	uint32_t cdi_local2[CDI_WORDS];
	wordcpy_s(cdi_local, CDI_WORDS, (void *)cdi, CDI_WORDS);

	// Write to CDI should NOT have any effect in app mode.
	wordcpy_s((void *)cdi, CDI_WORDS, zeros, CDI_WORDS);
	wordcpy_s(cdi_local2, CDI_WORDS, (void *)cdi, CDI_WORDS);
	if (!memeq(cdi_local, cdi_local2, CDI_WORDS * 4)) {
		failmsg("Write to CDI in app-mode");
		anyfailed = 1;
	}

	// Should NOT be able to reset Tkey from app mode
	puts(IO_CDC, "\r\nTesting system reset...");
	*system_reset = 1;
	puts(IO_CDC, "done.\r\n");

	// Test FW_RAM.
	*fw_ram = 0x21;
	if (*fw_ram == 0x21) {
		failmsg("Write and read FW RAM in app-mode");
		anyfailed = 1;
	}

	puts(IO_CDC, "\r\nTesting timer... 3");
	// Matching clock at 24 MHz, giving us timer in seconds
	*timer_prescaler = 24 * 1000000;

	// Test timer expiration after 1s
	*timer = 1;
	// Start the timer
	*timer_ctrl = (1 << TK1_MMIO_TIMER_CTRL_START_BIT);
	while (*timer_status & (1 << TK1_MMIO_TIMER_STATUS_RUNNING_BIT)) {
	}
	// Now timer has expired and is ready to run again
	puts(IO_CDC, " 2");

	// Test to interrupt a timer - and reads from timer register
	// Starting 10s timer and interrupting it in 3s...
	*timer = 10;
	*timer_ctrl = (1 << TK1_MMIO_TIMER_CTRL_START_BIT);
	uint32_t last_timer = 10;
	for (int i = 0; i < 3; i++) {
		last_timer = wait_timer_tick(last_timer);
	}
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

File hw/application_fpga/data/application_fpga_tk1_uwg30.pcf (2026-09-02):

#=======================================================================
#
# application_fpga_tk1_uwg30.pcf
# ------------------------------
# Pin constraints file for the Application FPGA design to be used
# on the tk1 board with the CH552 MCU used as a USB-serial chip.
# This version targets the UWG30 package.
#
#
# SPDX-FileCopyrightText: 2022 Tillitis AB <tillitis.se>
# SPDX-License-Identifier: BSD-2-Clause
#
#=======================================================================

# UART.
set_io interface_rx A1
set_io interface_tx A2
set_io interface_ch552_cts A4
set_io interface_fpga_cts B3


# SPI master to flash memory.
set_io spi_miso E1
set_io spi_sck  D1
set_io spi_ss   C1
set_io spi_mosi F1


# Touch sense.
set_io touch_event B1


# LEDs
set_io led_r A5
set_io led_b B5
set_io led_g C5

#=======================================================================
# EOF application_fpga_tk1_uwg30.pcf
#=======================================================================

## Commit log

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2022-09-28 Be consistent and check for errors first
    [main.c]
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2022-10-06 Squashed commit of the following:
    Silence lint on intentional combinatinal loops
    Use better instance names, and a single lint pragma for all macros
    Remove unused pointer update signals
    Silence lint on wires where not all bits are used
    Change fw_app_mode to be an input port to allow access control
    Remove redundant, unused wire mem_busy
    Add lint pragma to ignore debug register only enabled by a define
    Remove clk and reset_n ports from the ROM
    Adding note and lint pragma for rom address width
    Fix incorrect register widths in uart_core
    Assign all 16 bits in LUT config
    Silence lint warnings on macro instances
    Correct bit extraction for core addr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
2022-10-12 Adjust and document the firmware state-machine, including USS
    In particular, order of LOAD_USS and LOAD_APP_SIZE is not required, but
    the need to send both is documented. This is followed up with adjustment
    in the host programs' Go code, to try to reinforce this. LoadApp() will
    take the secretPhrase parameter (to be hashed as USS), and loadUSS()
    will be unexported.
    Correct CMD/RSP lengths in pseudo-code.
    [main.c]
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2022-10-24 Clear all RAM during start
    Since SRAM has some data remanence even without power it seems good
    hygien to clear all RAM when starting the device so as not to leak
    potential sensitive data between device apps.
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2022-11-02 Make hid_test fail less confusingly when programming device is not connected
    Add requirements.txt
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2022-12-19 Purge UDA; never implemented, now deprecated
    Fixes #58
    [main.c]
2022-12-22 TK-1 and TP-1 PCBs (#52)
    * Add kicad library for flat programming clip
    * Add descriptions to part symbols
    * Add extended values, manufacturer/distributor info to components in mta1
    * Add new board entry for TK1
    * Add TP1 programmer design
    * Update MTA1-USB-V1 release files to match production
    * Change SPI flash memory type to XT25F08BDFIGT-S
    * Change touch sensor feedback cap to 1uF
    * Add manufacturer, manufacturer part number, distributor, distributor part number
    * Update component values for TK1 PCB
    * Use specific part # for C8
    * Change flash back to Winbond part, for easier sourcing
    * Change C1 to 1pF
    * Fixes for production programmer PCB
    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
    [application_fpga.kicad_sch, mta1-usb-v1-programmer.csv, mta1-usb-v1-programmer.kicad_sch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]
2023-01-11 Add (hardware) production tests for the TK-1 and TP-1 (#69)
    * ch552 firmware: add ch55x support files directly
    * Add sdcc compiler to docker image, for building CH552 firmware
    * Rework production test script
    * Add menu-based test runner
    * Rewrite production test flows as lists of individual tests
    * Add both production flows and manual tests to menu
    * Switch to using included binaries
    * production test: Update message format
    * test_txrx_touchpad: Retry if device communications fail
    * production test: put all binaries in binaries/ folder
    * binaries/top.bin: replace broken binary
    * flash_check: Check for explicit flash IDs
    * Document most test procedures
    * Test plan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
    [usb_pins-good.csv, usb_pins.csv]
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2023-02-15 toolchain setup: link to CH552 build instructions (#78)
    * Remove 'Optional' section from README, and update titles of
    sub-sections.
    * Add link to sub-directory with CH552 setup instructions
    * Fix line lengths in programmer board section
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2023-03-14 fw: Safer memory functions + asserts
    Introduce memcpy_s() and wordcpy_s() that takes the destination buffer
    size as an argument. Use assert() which aborts our program to an
    eternal loop if we hit problems.
    Sprinkle asserts elsewhere as well.
    [main.c]
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2023-03-14 fw: Use byte readable UDS
    UDS is now byte readable (but not writable).
    Use UDS and USS directly in a blake2s_update() instead of
    concatenating them into fw_ram. UDS will still live for a short while
    in fw_ram in the blake2s context buffer but will soon be overwritten.
    [main.c]
2023-03-14 fw: Remove state init_loading, introduce state fail
    - We always assert on allowed commands in a state.
    - We don't allow FW_CMD_LOAD_APP to be used twice.
    - Enter fail state on read buffer overrun, header endpoint not for us,
    header parse error, and unknown firmware command.
    [main.c]
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2023-03-14 Keep uninitialized var in main, not globally, preventing any BSS
    [main.c]
2023-03-14 fw: load app at the start of RAM
    Since app is always loaded at the start of RAM, the TK1_APP_ADDR define
    is no longer needed.
    [main.c]
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2023-03-14 fw: Go to state fail on bad command lengths
    [main.c]
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2023-03-21 Fix udev rules
    * USB VID and PID are case sensitive
    * Only give permissions for owner and group
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2023-03-22 fw: clang-tidy and splint: New make target: check
    Add clang-tidy and splint static analytics check. For now, we use only
    the cert-* warnings on clang-tidy and run splint with a lot of flags
    to allow more things.
    Changes to silence these analytics:
    - Stop returning stuff from our debug print functions. We don't check
    them anyway and we don't have any way of detecting transmission
    failure.
    - Declare more things static that isn't used outside of a file.
    - Change types to be more consistent, typically to size_t or
    something or to uint32_t.
    [main.c]
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2023-03-27 fw: UDS not byte-readable
    Since UDS is not byte-readable we copy it by word to local_uds. Now
    UDS lives for a short while in local_uds on the stack in FW_RAM and in
    the internal buffer of the blake2s context (also in FW_RAM) but is
    very soon overwritten.
    [main.c]
2023-03-28 testfw: update check for new known UDS; correctly and always print UDS
    [main.c]
2023-03-28 testfw: use a func for fail prints
    Now testfw fits again (when built with -Os)
    [main.c]
2023-03-28 testfw: compare UDS correctly, correct byte-order
    Also don't let fwram success overwrite anyfailed
    [main.c]
2023-03-29 toolchain: pin yosys to latest tag, icestorm to recent commit, use newer nextpnr
    The icebram and nextpnr issues have been resolved.
2023-07-04 Replaced Cap w. spring contacts
    [application_fpga.kicad_sch, powersupply.kicad_sch, tk1.csv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]
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2024-03-14 FW: Force the CPU to hang on errors
    [main.c]
2024-03-19 Change memory constants to defines
    Instead of putting memory constant into an enum we use defines.
    Use the direct memory address instead of ORing constants together to
    compute the address.
    An enum in ISO C is a signed int. Some of are memory addresses are to
    large to fit in a signed int. This is not a problem since we're not
    using ISO C (-std=gnu99) but it doesn't look very nice if you turn on
    pedantic warnings. Also, if someone would use another compiler which
    at least supports the inline assembly we use, but possible not other
    GNU extensions, things would probably break.
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2024-03-19 fw: Change memory constants to defines
    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
2024-03-20 Add set-only register for the force_trap signal to ensure that the device must be reset to get out of trap. This change also breaks a critical path.
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2024-03-22 Include static analysis in CI
    - Exclude splint from CI, so we make another target for it "splint",
    which we might include in the "check" target later.
    - Move the analysis runs earlier in CI so they, including indentation
    checks, fail first.
    - Include printouts of hashen in check-binary-hashes to easier see
    what the digest are if it fails in CI.
2024-03-26 fw: Protect zeroisation against compiler optimisation.
    The memset() responsible for the zeroisation of the secure_ctx under
    the compute_cdi() function in FW's main.c, was optimised away by the
    compiler. Instead of using memset(), secure_wipe() is introduced
    which uses a volatile keyword to prevent the compiler to try to
    optimise it. Secure_wipe() is now used on all locations handling
    removal of sensitive data.
    [main.c]
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2024-06-13 Remove redundant RAM address and data scrambling
    The RAM address and data scrambling API was called twice, once before filling
    RAM with random values, and once after. Since moving to a significantly
    better PRNG (xorwow) this is now deemed unnecessary. See issue #225.
    This changes both FPGA and firmware hashes.
    [main.c]
2024-06-19 FPGA: SPI-master improvements
    - Changed FSM states to localparams
    - Added localparam for SPI clock divisor
    - Added internal signal for divisor reached
    - Improved comments to clarify code
    - Fixed some minor textual nits
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2024-07-11 FPGA: Cleanup tk1 spi testbench
    - Remove DUT variables from state display that was removed as part of
    performance fix
    - Corrected some incorrect display statements for expected unique ID and
    byte counters
2024-09-19 fw: remove warning of missing prototypes when building with QEMU console enabled.
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2024-10-16 Include SPI master in default build
    This prevents building without the SPI master, the intention is to use
    a different method than if-defs, but it will be introduced at a later
    stage.
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2024-10-17 Move the `boards` folder to new repositories
    To simplify versioning and isolate the different parts of the projects
    to their own repositories, these hardware parts are moved to separate
    locations.
    - tk1, mta1-usb-dev, mta-usb-v1 and mta1-library moves to
    https://github.com/tillitis/tk1-pcba
    - tp1, mta1-usb-programmer, mta1-library and KiCad-RP Pico moves to
    https://github.com/tillitis/tp1
    - Relevant documentation referring to these boards are also moved to the
    new repositories, links are updated to point to the new location
    - The CERN-OHL-S license is removed from this repo
    - CI is no longer building the TP1 firmware
    [2022-08-22 case production bottom.step, 2022-08-22 case production top.step, 2022-08-22 case v3.f3z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]
2024-10-22 Add yosys flags to optimize synthesis
    * -abc2, run two passes of 'abc' for slightly improved logic density
    * -device u, optimize timing for up5k device
    * -dff, run 'abc'/'abc9' with -dff (D flip flop) option
    Update digest of application_fpga.bin
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2024-10-25 Fix flash target in contrib/Makefile
    Setting the working directory to a directory that exist.
    Previously the working directory was set to /build/hw/application_fpga.
    But that path does not exist since hw/application_fpga was mounted to
    /build. Thus resulting in an error:
    'Error: workdir "/build/hw/application_fpga" does not exist on
    container'
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2024-11-27 Fix bug in timer core, where it misses clock cycles
    Remove redundant timer state. This fixes a bug where the timer misses a
    clock cycle every time the prescaler counter reaches 1. This means if
    one uses a large prescaler, like 18E6, it is barely noticeable, but if
    one have a low prescaler and a high timer value it becomes significant.
    This also yields the running_* registers redundant, which are removed.
    Add clarity to the readme.
    Update the timer to default to values of one, for prescaler and timer
    count.
2024-11-27 tb: make timer core testbench selftesting
    - Compare against an expected result and count errors
    - Exit with the right error code
    - Clean up the output
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2025-02-11 ch552: Use the new hardware CTS signals for UART access
    - Use CTS signals to let the FPGA and CH552 signal each other that
    it is OK send UART data.
    - Update the CH552 rx and frame handling logic.
    - Fix minor spelling errors and indentation
    [main.c]
2025-02-11 fpga/testfw: Update clock frequency to 24 MHz
    Reconfigure the baudrate to keep 500 kbaud.
    Correct a forgotten test in testfw that wasn't updated the last time
    frequency was raised in commit
    75b028505f0d6dc685d37b84d73ddb9db5ee7ea2 in June 17, 2024.
    [main.c]
2025-02-11 fpga: Fix bitrate counter bug
    Fix off-by-one UART bitrate counter value that will make the RX
    sampling and TX sending drift. The impact gets higher as the baudrate
    increases and the bitrate counter value gets smaller.
2025-02-11 ch552: Fix CDC configuration problem on Windows
    Fix CDC configuration problem on Windows when we have a composite
    device (multiple different Device Classes). Add "Interface Association
    Descriptor" to make it work.
    [main.c]
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2025-02-21 fpga/fw: Resize ROM and FW_RAM, add RESETINFO partition
    In order to be able to leave data for firmware signalling the
    intention with a reset or to leave data for the next app in a chain of
    apps, we introduce a part of FW_RAM that can be used to store this
    data. In order to do this, we:
    - Change size of ROM from 6 KB to 8 KB.
    - Change size of FW_RAM, from 2 KB to 4 KB.
    - Add RESETINFO memory partition inside FW_RAM.
    - Add generation of map file.
    - Change CFLAGS from using -O2 to using -Os.
    - Update address ranges for valid access to ROM and FW_RAM.
    - Move stack to be located before data+bss and the RESETINFO data
    above them. This also means we introduce hardware stack overflow
    protection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
    [main.c]
2025-02-25 ch552: Fix race condition
    - Move "EndpointXUploadBusy = 1" to before USB transfer is started to fix
    race with USB transfer complete interrupt.
    [main.c]
2025-02-25 ch552: Misc. fixes and cleanup
    - Move copying of TKEYCTRL data from UartRxBuf to TkeyCtrlRxBuf to align
    with previous code.
    - Remove obsolete UartRxBufOverflow variable.
    - Add missing Endpoint4 handling for USB bus reset.
    - Fix more robust uart_byte_count() calculation.
    - Fix baudrate fast mode calculation to get rid of compiler warning.
    - Fix assignment of bUD_PD_DIS to UDEV_CTRL.
    - Cleanup comments.
    [main.c]
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2025-02-27 testfw/testapp: Break out tests running in app mode into separate app
    App mode can no longer be controlled from software. So the tests have to
    run from firmware RAM.
    [main.c]
2025-02-27 testapp: Call reset syscall
    [main.c]
2025-02-27 fpga/fw: Introduce syscall TK1_SYSCALL_GET_VIDPID
    Introduce new syscall TK1_SYSCALL_GET_VIDPID to get Vendor ID and
    Product ID from the protected Unique Device Identification number.
    UDI is protected from device apps to protect the serial number, so
    apps won't know the exact TKey they are running on other than the CDI.
    It may, however, be important to know what *kind* of TKey they are
    running on, so we want to expose the Vendor ID and Product ID.
    - fpga: Allow UDI to be read when doing syscalls.
    - Add the new syscall to firmware.
    - Add test to testapp directly after negative test of reading UDI to
    read out VID/PID through a syscall.
    [main.c]
2025-02-27 fpga: Only allow system reset in firmware mode and syscalls
    [main.c]
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2025-03-13 fw: Import tkey-libs fw-2
    This is an import of the fw-2 tag of tkey-libs.
    We import the entire tkey-libs repo minus dot files into the
    tillitis-key1 repo to make it very simple not to make mistakes
    regarding which firmware tag depends on which tkey-libs tag,
    especially considering locking down with NVCM.
    Please see README for information about developing with another
    tkey-libs or how to import future tkey-libs.
    Since tkey-libs is now a part of the repo we also add tkey-libs to the
    clean_fw target.
    [io.c, monocypher.c]
2025-03-14 ch552: Misc. cleanup
    - Merge Makefile and Makefile.include into Makefile
    - Format structure
    - Remove unused variables, targets etc.
    - Add missing check if it is ok to send data to the FPGA.
    - Remove 'baud rate calculator.ods'
    - Update encode_usb_strings.py to generate strings for
    CdcCtrlInterfaceDesc, CdcDataInterfaceDesc,
    FidoHidInterfaceDesc, TkeyCtrlInterfaceDesc.
    Also store generated strings in UTF-16 instead of hex.
    - Update usb_strings.h to match new encode_usb_strings.py
    output.
    - Remove unused struct SetupReqBuf.
    [baud rate calculator.ods]
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2025-04-17 ch552: Fix various USB stack things, add check for IO_CH552 command range.
    - Move handling of returning data from USB_GET_DESCRIPTOR request.
    - Fix correct size of ActiveCfgDesc descriptor.
    - Add missing check for limiting total length in USB_CDC_REQ_TYPE_GET_LINE_CODING.
    - Add missing break in DeviceInterrupt to follow coding style.
    - Check command range for IO_CH552.
    - Add some comments.
    [main.c]
2025-04-24 fw: Add pre loaded flash app and flash data storage
    - Add per app flash storage
    - Adds four data areas. An app can allocate an area. Once allocated
    the area is tied to the CDI of the app and can only be
    read/written/deallocated by the same app.
    - Add two pre loaded app slots to flash
    - Load an app from the first slot at boot. The app digest must match a
    specific digest specified in firmware.
    - Optionally load an app from the second slot
    - Add a resetinfo area in FW_RAM which is used to signal an app's intent
    of resetting the system and, optionally, pass data to firmware or the
    next app in a bootchain.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
    [flash.c, main.c]
2025-04-24 reset_test: Add resetinfo testapp
    [main.c]
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2025-05-06 fw: Introduce reset()
    - New function reset.c:reset(). Move code from syscall handler switch
    to this function.
    - Rename resetinfo.h to reset.h.
    [main.c]
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2025-05-07 ch552: Fix FIDO data copy
    Fix potential out of bounds write.
    [main.c]
2025-05-15 fw: Add syscall TK1_SYSCALL_GET_APP_DATA
    Add a new syscall to enable an app to get the data left for it by the
    previous app in chain.
    - Change testloadapp to leave some data for the next app to read.
    - Call system call with:
    uint8_t next_app_data[RESET_DATA_SIZE];
    syscall(TK1_SYSCALL_GET_APP_DATA, (uint32_t)next_app_data, 0, 0);
    [main.c]
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2025-05-16 Reset USB controller endpoints when starting
    When starting, reset the USB controller to only enable the USB CDC
    endpoint and the internal command channel. If the app resets firmware,
    but had differend endpoints enabled, we want to go back to a known
    state.
    [main.c]
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2025-05-20 fw: Add debug print when reading partition table fails
    [main.c]
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2025-06-19 fw: Fix qemu_firmware build warnings
    [main.c]
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2025-06-27 Update USB VID and PID for Castor
    VID has been wrong for some reason, therefore changed to the
    correct value 0x1209.
    New PID to differentiate Castor from Bellatrix.
    [main.c]
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2025-11-13 ch552: add zero length packet handling
    Terminate all 64-byte frames with a zero-length packet. Handle incoming
    zero-byte frames by ignoring them. This fix addresses issues related to
    transfers of an exact length of 64 bytes (or multiples thereof) on all
    platforms. For simplicity, all 64-byte frames are terminated, regardless
    of whether they are the last or not.
    [main.c]
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2026-01-23 Fix endpoint buffer namning and cleanup comment formatting.
    [main.c]
2026-01-23 ch552: fix warning 283: function declarator with no prototype
    [gpio.c, main.c]
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2026-01-28 fw: Support combination of measured boot and verified boot
    Change to using two modes for the CDI computation to support verified
    boot:
    1. Measure the app digest with the UDS and USS, like before:
    CDI = blake2s(UDS, blake2s(entire app)[, USS])
    This is the default.
    2. When using verified boot indicated by setting the new
    struct reset member mask bitmask to include RESET_SEED) compute CDI
    like this instead:
    CDI = blake2s(UDS, blake2s(previous app's CDI, measured_id_seed)[, USS])
    In order not to leak CDI over resets we do the computation in two
    steps:
    1. When an verified boot app has verified the next app it fills in
    the measured_id_seed, typically with a dig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
    [main.c]
2026-09-01 ch552: Deactivate CTS early
    Deactivating CTS early to increase the chance that it has the correct
    state when the other end samples it the first time.
    [main.c]
2026-09-01 fw/ch552: Enable USB endpoints after a SET_ENDPOINTS command is received
    Instead of always enabling USB endpoints at boot we let the firmware or
    app that intend to receive data decide when to enable them.
    This allows a client to know when to send data after a reset.
    [main.c]
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2026-09-01 testfw: Workaround UART TX line power-on glitch
    A glitch on the UART TX line during power-on is interpreted as a valid
    byte by the USB controller. This corrupts the first command we try to
    send, causing the USB controller to ignore the command and reset.
    We work around this by sending a command to force a reset and then
    waiting until the USB controller has restarted before sending the
    endpoint configuration command.
    Since we introduce a delay the LED is turned on after the config command
    has been sent. This gives the user a hint for when the port will be up.
    [main.c]
2026-09-02 fpga: Experimental fpga build for uwg30 package
    nextpnr-ice40 fails with:
    ```
    Info: Placing PLLs..
    ERROR: PLL 'reset_gen_inst.pll_inst' couldn't be placed anywhere, no
    suitable BEL found.
    PLL bel 'X12/Y31/pll_3' cannot be used as it conflicts with input
    'interface_ch552_cts$sb_io' on pin 'B3'.
    ```
    [application_fpga_tk1_uwg30.pcf]
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2026-09-02 flip correct tx/rx pins
    [application_fpga_tk1_uwg30.pcf]
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2026-09-15 ch552: add optional bulk-transfer mode for DEBUG interface
    - Add BULK make flag to define USE_BULK_TRANSFER_FOR_DEBUG, switching
    the DEBUG interface from interrupt to bulk endpoints (0 ms bInterval
    instead of 16 ms)
    - Add a bulk-only DebugDesc variant (23 bytes vs. 32) alongside the
    existing interrupt version, selected via #ifdef
    USE_BULK_TRANSFER_FOR_DEBUG
    - Skip DebugCfgDesc/DebugReportDesc HID requests when built with
    USE_BULK_TRANSFER_FOR_DEBUG, since the vendor-specific bulk
    interface has no HID report descriptor
    - Fold DEBUG_REPORT_DESC_SIZE into the interrupt/bulk #ifdef
    [main.c]
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2026-09-15 ch552: gate USB-to-UART forwarding on FPGA CTS signal
    - Only forward buffered USB data (EP2 CDC, EP3 FIDO/CCID, EP4 DEBUG)
    to the UART when the FPGA asserts CTS (P1.4 low), preventing
    deadlocks when the FPGA isn't ready to receive
    - Fix bug where the FPGA's CTS signal was constantly ignored in
    CH554UART1SendByte
    [gpio.c, main.c]
2026-09-18 fw: minimise reset types and hence boot paths
    Remove START_DEFAULT, START_FLASH1 and START_FLASH0_VER as possible
    reset types. This removes a few possible boot paths, where the main
    reason is to lower complexity and number of states in firmware.
    This does not remove any features, the same states is still reachable -
    just with fewer paths getting there.
    - Update testapps under apps/
    - Update hashes for firmware and bitstream
    [main.c]
2026-09-23 fw: Separate CDI domains based on how they where loaded
    Prevents the case where a verified app booted from client modifies the
    data area of a verified app installed in flash. If the app booted from
    client performs data migrations, or modifies data in some other way, the
    result could be that the app in flash cannot boot correctly.
    - A 'DOMAIN_RESET_TYPE' field is added to the CDI domain byte to give
    apps different CDIs depending on how they where loaded. 'resetinfo.type'
    is used as value.
    - DOMAIN_* defines changes names to make intent clearer.
    [main.c]
2026-09-24 fw: Support the standardized reset command
    Support the reset command as implemented in tkeyclient commit
    8a6c73692db2e685d86672879f5943404bc9e361.
    We choose to be conservative and only allow reset when in the
    'FW_STATE_WAITCOMMAND' state.
    [main.c]
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
